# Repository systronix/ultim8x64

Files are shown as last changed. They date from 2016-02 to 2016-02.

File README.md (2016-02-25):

# ultim8x64

ultimate LED panel

built using APA102 RGB LEDs

8x64 matrix

Modular

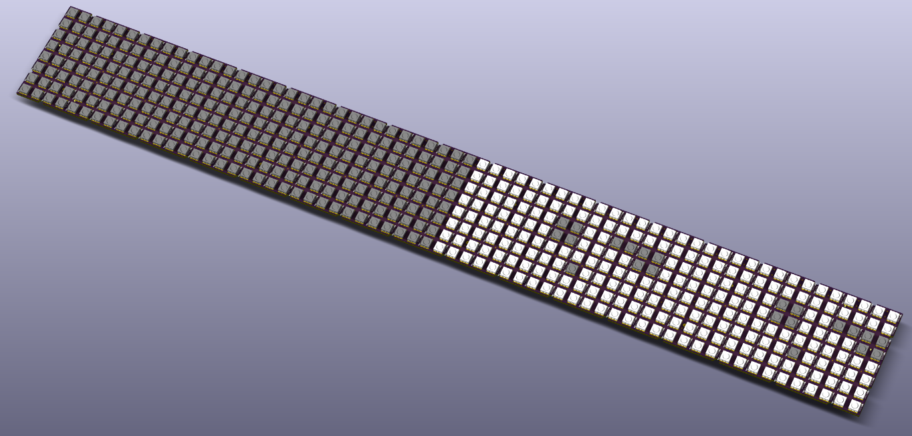
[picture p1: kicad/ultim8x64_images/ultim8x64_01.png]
ultim8x64 top


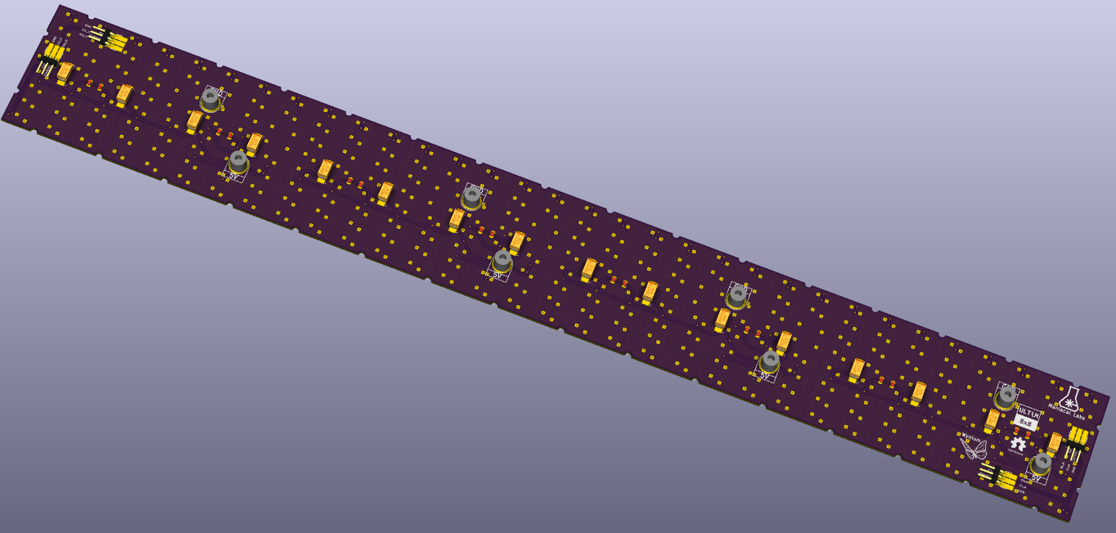
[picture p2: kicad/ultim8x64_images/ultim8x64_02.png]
ultim8x64 bottom


License
-------
[CERN Open Hardware Licence v1.2 ]

[CERN Open Hardware Licence v1.2 ]:http://www.ohwr.org/attachments/2388/cern_ohl_v_1_2.txt

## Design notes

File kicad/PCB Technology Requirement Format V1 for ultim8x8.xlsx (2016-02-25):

深圳矽递科技有限公司 Seeed Technology Limited
PCB Technology Requirement Format
PCB Name & Version | ULTiM8x8
PCB Material PCB板材： | (Rigid)FR－4
PCB Size PCB大小： | inch | ( 2.40 ) × (2.40 )
PCB Layer PCB层数： | 2
Thickness PCB厚度：
 | 1.6mm
Copper Weight 铜厚： | 1oz
PCB Colour 阻焊颜色： |  | White白色
Silkscreen 字符颜色： |  | Black 黑色 | other:( )
Pads Finished 焊盘喷镀： | (Hasl-lead free) 无铅喷锡
Via solder mask 阻焊覆盖： |  | solder mask opening 过孔开窗
Minimum trace/space (mm) 最小线宽 | 0.254mm/0.254mm | Minimum hole size (mm) 最小孔径 | 0.635mm
Special requirements 特殊工艺： | No | (Put requirements here)
Comment:

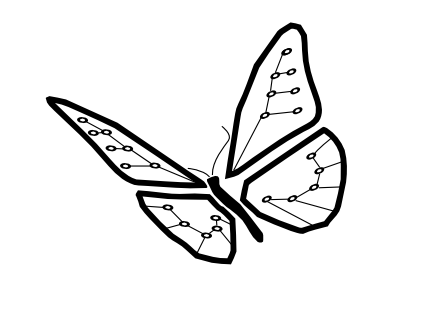
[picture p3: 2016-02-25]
kicad/ultim8x64_data/wyolum_butterfly.png

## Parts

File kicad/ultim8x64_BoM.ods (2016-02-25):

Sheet: BoM_TinyTiM
Id | Reference | Quantity | Value | Package
1 | C1,C3 | 2 | 100nF | c_0805
2 | C2,C4 | 2 | 47uF 20V | c_2917
3 | P1, P2, P5, P6 | 1 | Input1, Input2, Output1,Output2 | header_3pos_smd_male
4 | P3, P4 | 1 | 5V, GND | PowerIn_stud
5 | U01 ~ U64 | 64 | APA102 | APA102

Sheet: BoM_PCB
Id | Value | Reference | Quantity | Package
1 | 100nF | C3,C1 | 2 | c_0805
2 | 47uF 20V | C2,C4 | 2 | c_2917
3 | Input1, Input2, Output1,Output2 | P1, P2, P5, P6 | 1 | header_3pos_smd_male
4 | 5V, GND | P3, P4 | 1 | PowerIn_stud
5 | APA102 | U01 ~ U64 | 64 | APA102

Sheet: BoM_SCH
Reference | Value | Footprint
C1, C3 | 100nF | ultim8x8_libs:c_0805
C2, C4 | 47uF 20V | ultim8x8_libs:c_2917
P1, P2, P5, P6 | Input1, Input2, Output1, Output2 | ultim8x8_libs:header_3pos_smd_male
P3, P4 | 5V, GND | ultim8x8_libs:PowerIn_stud
U01 ~ U64 | APA102 | ultim8x8_libs:APA102

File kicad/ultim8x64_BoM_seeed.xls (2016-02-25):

Electronic Engineering BOM List
Product Name：ULTiM8x8
Version：V1.0
Issue Date：19/Feb/2016
Item No. (序号) | Reference Des (上件位置) | Qty (用量) | Catalog (分类） | Part_Description (规格描述) | Part_Value （元件值） | Part_Package （元件封装） | Manufacturers Name (使用厂牌名称) | Manufacturers Part No. (使用厂牌型号) | Distributors Name （供应商名称） | Distributors Part No. (供貨商型号) | Unit Price （单价） | Price Break To Use （价格分段的购买量） | Notes/Remark （备注）
Example（填写范例）
1 | U01 ~ U64 | 64 | OTHER | 5050 SMD RGB LED with built-in controller | APA102 | 5050 | Shiji Lighting | APA102C | Aliexpress | APA102C
2 | C1 , C3 | 2 | Capacitor | CAP CER 0.1UF 25V 10% X7R 0805 | 100nF, 25V | Surface Mount, MLCC (c0805) | Kemet | C0805C104K3RACTU | Digikey | 399-1168-1-ND |  |  | http://www.digikey.com/product-detail/en/C0805C104K3RACTU/399-1168-1-ND/411443
3 | C2, C4 | 2 | Capacitor | CAP POLY 47UF 20% 20V SMD | 47uF, 20V | Surface Mount 2917 (7343 Metric) | Panasonic Electronic Components | EEF-CT1D470R | Digikey | P18993CT-ND |  |  | http://www.digikey.com/product-detail/en/EEF-CT1D470R/P18993CT-ND/5805643
4 | P1, P2, P5, P6 | 4 | Connector | CONN HEADER 3POS .100 RT/A SMD | Input1, Input2, Output1,Output2 | Male Pin, Header, Unshrouded, Breakaway, 3 pin | Sullins Connector Solutions | GBC03SGSN-M89 | Digikey | S1143E-03-ND |  |  | http://www.digikey.com/product-detail/en/GBC03SGSN-M89/S1143E-03-ND/862388
5 | P3, P4 | 2 | Connector | POWER ELEMENT BUSH | 5V, GND | Screw Terminal, Power Tap, M3 | Wurth Electronics Inc | 7466103 | Digikey | 732-5242-ND |  |  | http://www.digikey.com/product-detail/en/7466103/732-5242-ND/4733834
1. Recommended Distributor: Digi-Key, Mouser, Avnet Express, Farnell.
2. Catalog: Capacitor,Resister,Diode,Connector,Transistor,IC,PROTECTOR CATEGORY,OTHER
3. Required Fields: Item No, Reference Des, Qty, Catalog, Part_Value, Part Package
Optional Fields: Part_Description, Manufacturers Name, Manufacturers Part No, Distributors Name, Distributors Part No, Unit Cost, Price break to use, Notes/Remark

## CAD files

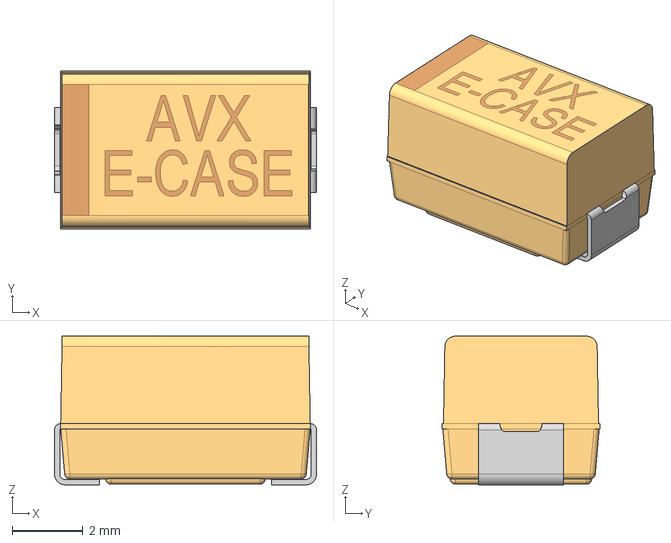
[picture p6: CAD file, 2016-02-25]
kicad/ultim8x64_3D_modules/Cap_2917_AVX_E_CASE.step
7.40 x 4.45 x 4.20 mm

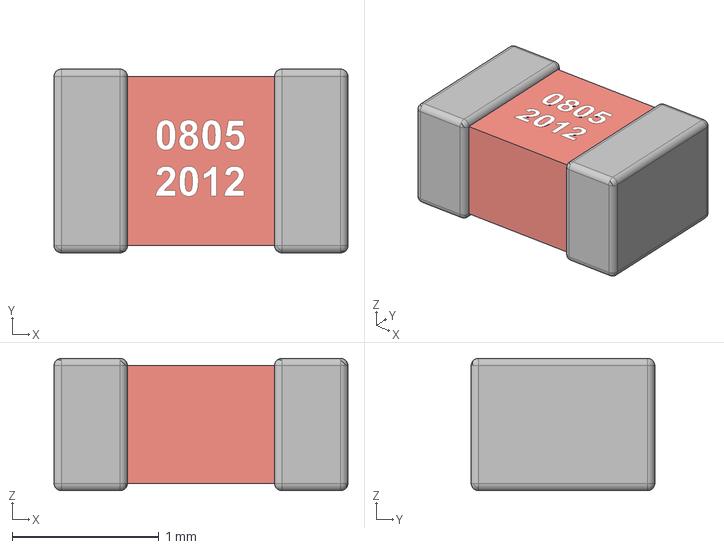
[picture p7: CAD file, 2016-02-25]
kicad/ultim8x64_3D_modules/Cap_0805_2012.step
2.00 x 1.25 x 0.9 mm

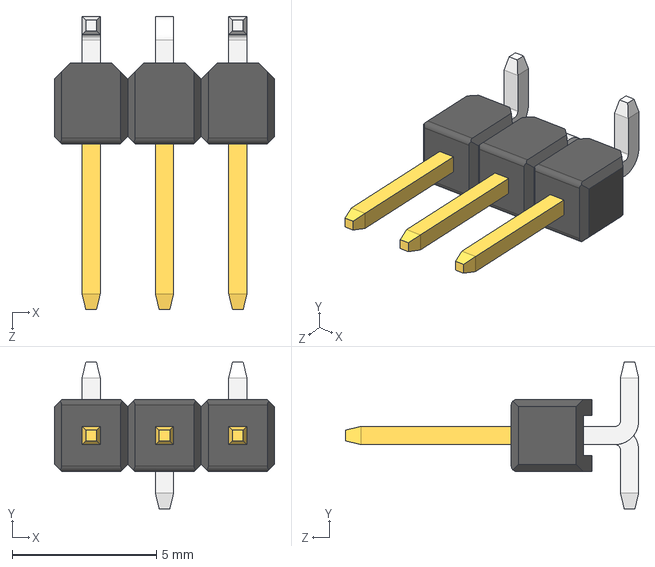
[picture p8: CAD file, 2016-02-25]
kicad/ultim8x64_3D_modules/header1x3_1241150-3.step
7.62 x 5.08 x 10.2 mm

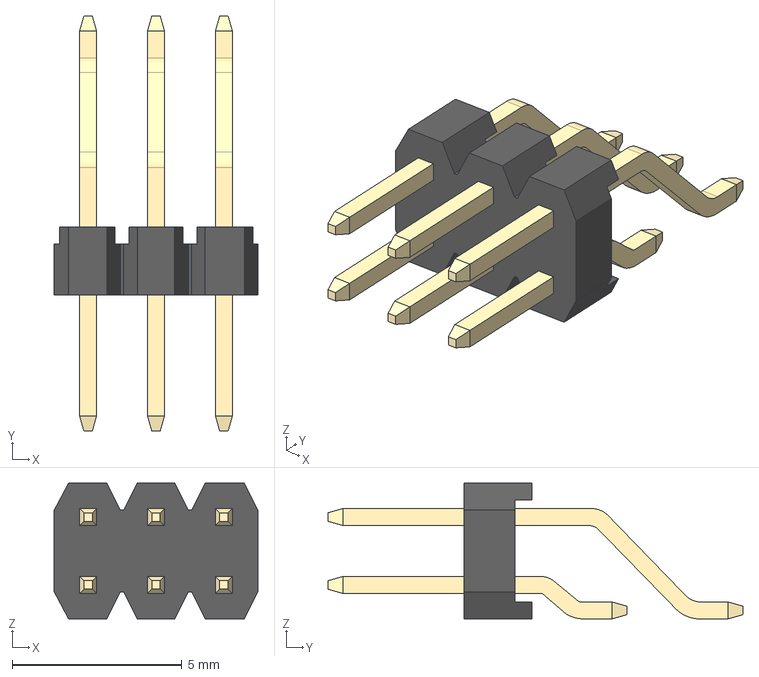
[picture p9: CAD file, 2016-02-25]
kicad/ultim8x64_3D_modules/header_a-sl200-da-g06mp1.step
6.00 x 12.2 x 4.00 mm

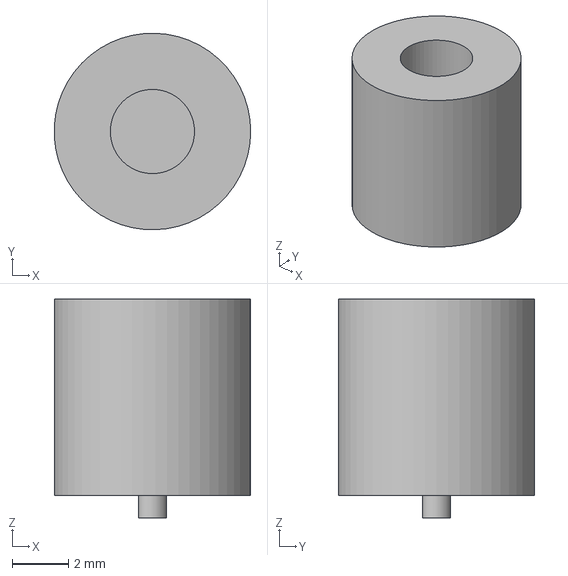
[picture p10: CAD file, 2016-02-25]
kicad/ultim8x64_3D_modules/PowerIn_Stud.step
6.99 x 7.00 x 7.80 mm

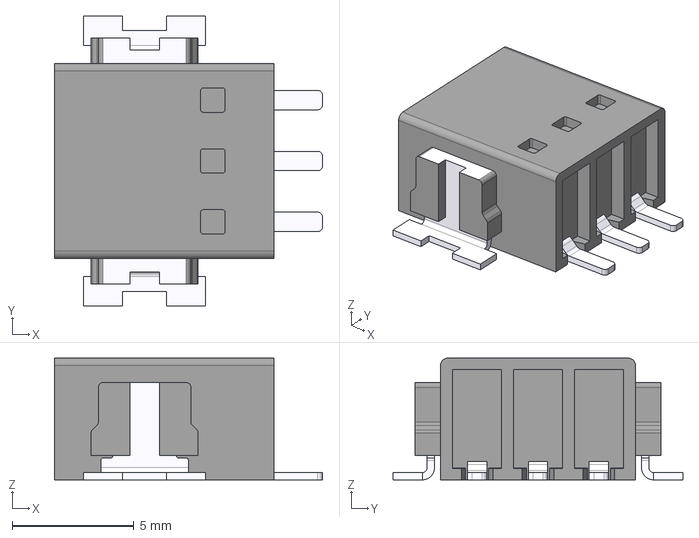
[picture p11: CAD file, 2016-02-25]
kicad/ultim8x64_3D_modules/conn_1771033.stp
11.0 x 11.9 x 5.00 mm

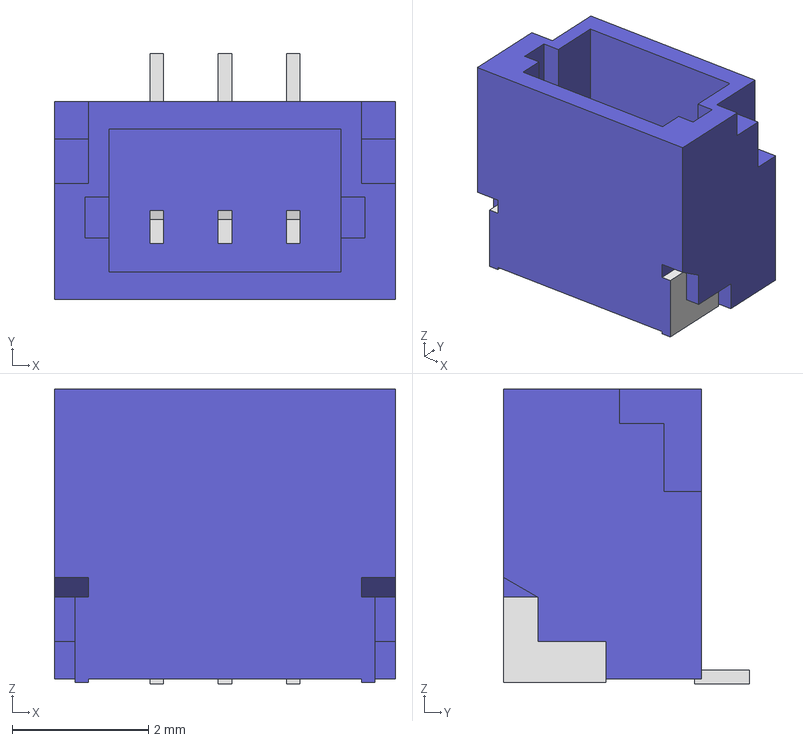
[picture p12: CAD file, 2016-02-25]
kicad/ultim8x64_3D_modules/BM03B-SRSS-TB.step
5.00 x 3.60 x 4.32 mm

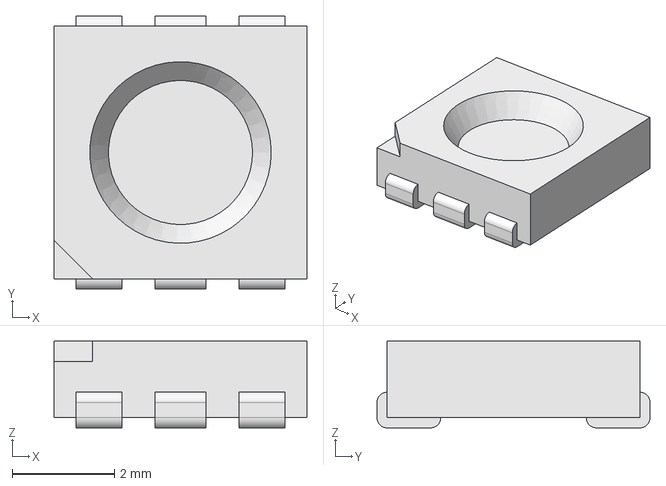
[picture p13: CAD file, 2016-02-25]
kicad/ultim8x64_3D_modules/LED_SMD_APA102.step
4.95 x 5.35 x 1.70 mm

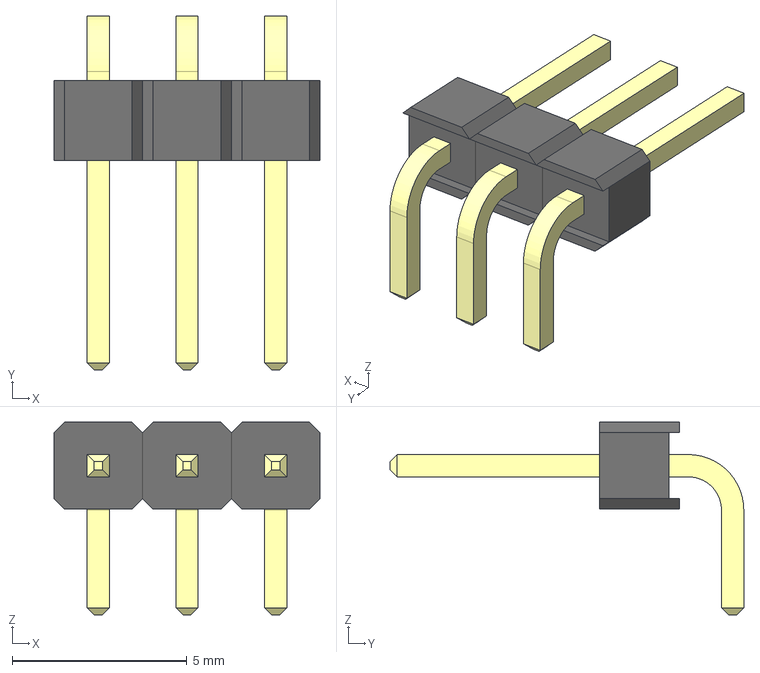
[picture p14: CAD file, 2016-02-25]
kicad/ultim8x64_3D_modules/header_Male_RA_Low_3Pin.step
7.62 x 10.1 x 5.52 mm

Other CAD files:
kicad/ultim8x64_3D_modules/PowerIn_Stud.fcstd

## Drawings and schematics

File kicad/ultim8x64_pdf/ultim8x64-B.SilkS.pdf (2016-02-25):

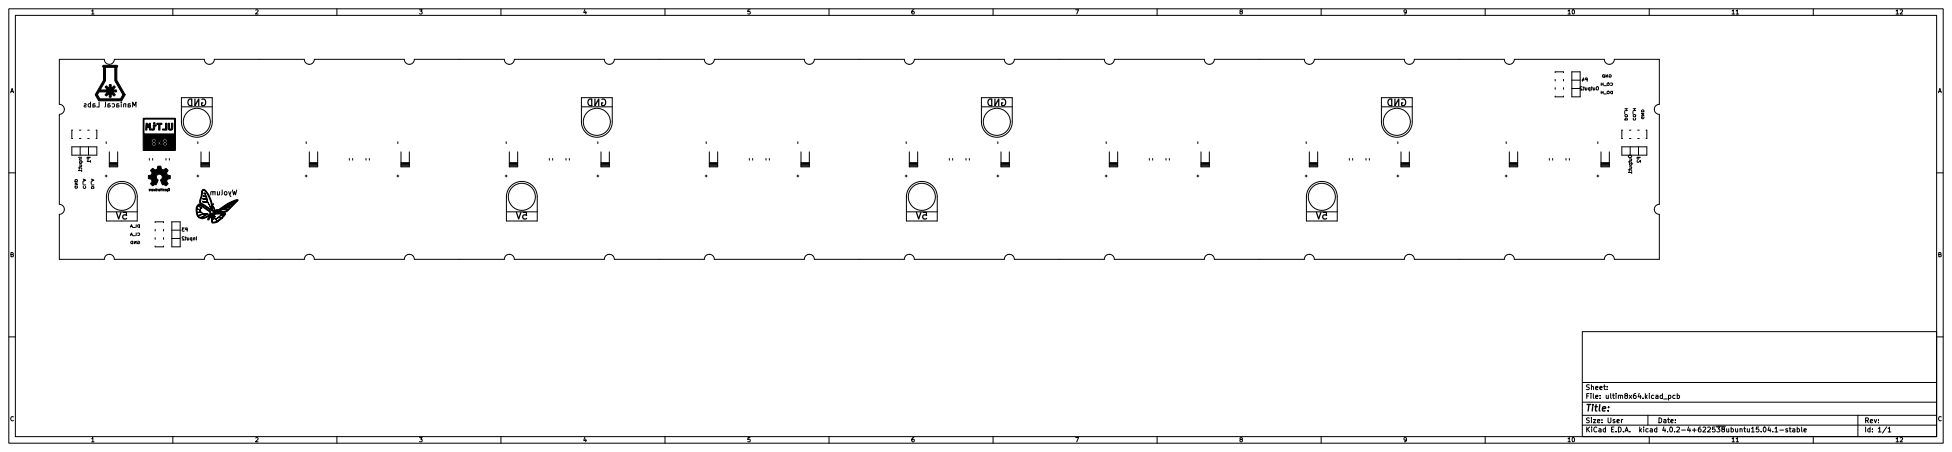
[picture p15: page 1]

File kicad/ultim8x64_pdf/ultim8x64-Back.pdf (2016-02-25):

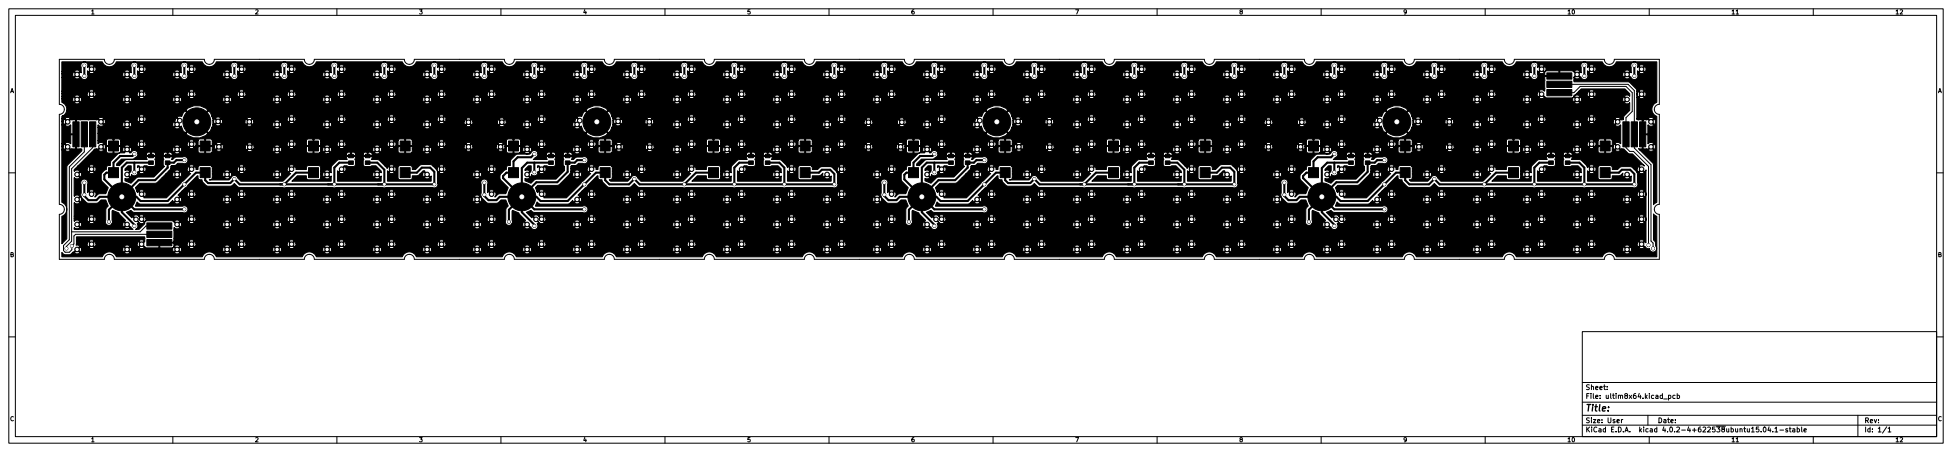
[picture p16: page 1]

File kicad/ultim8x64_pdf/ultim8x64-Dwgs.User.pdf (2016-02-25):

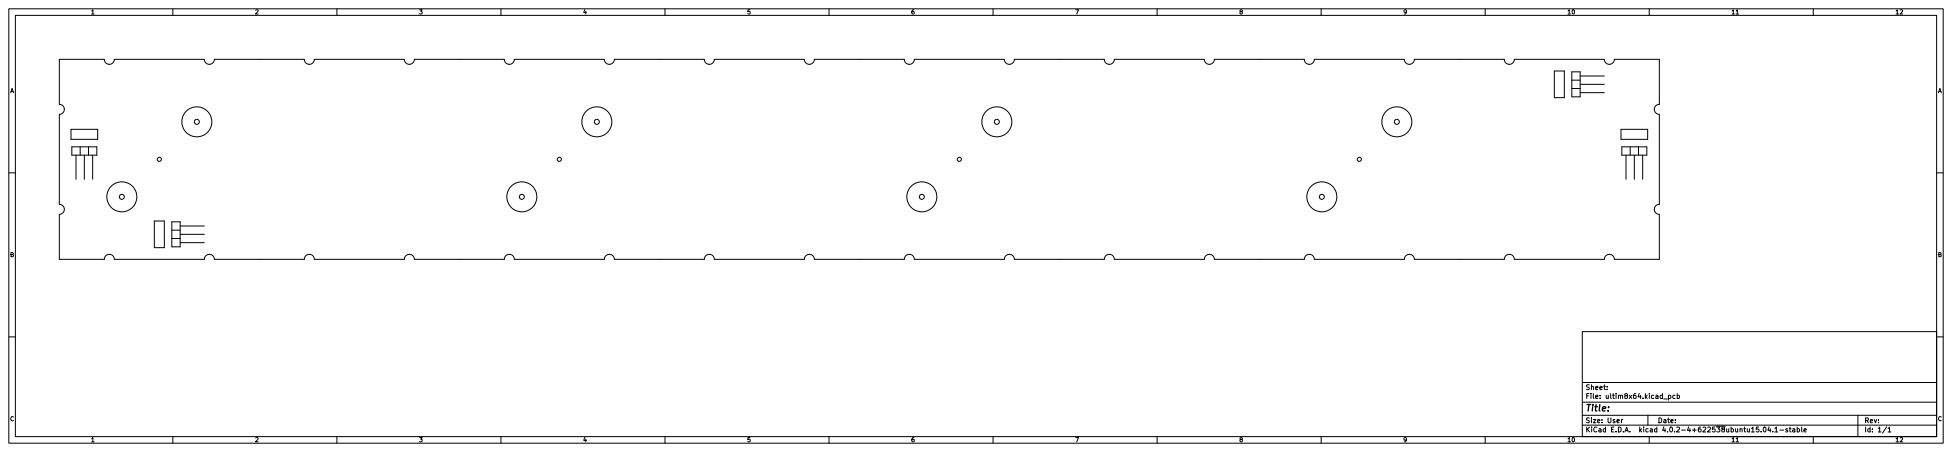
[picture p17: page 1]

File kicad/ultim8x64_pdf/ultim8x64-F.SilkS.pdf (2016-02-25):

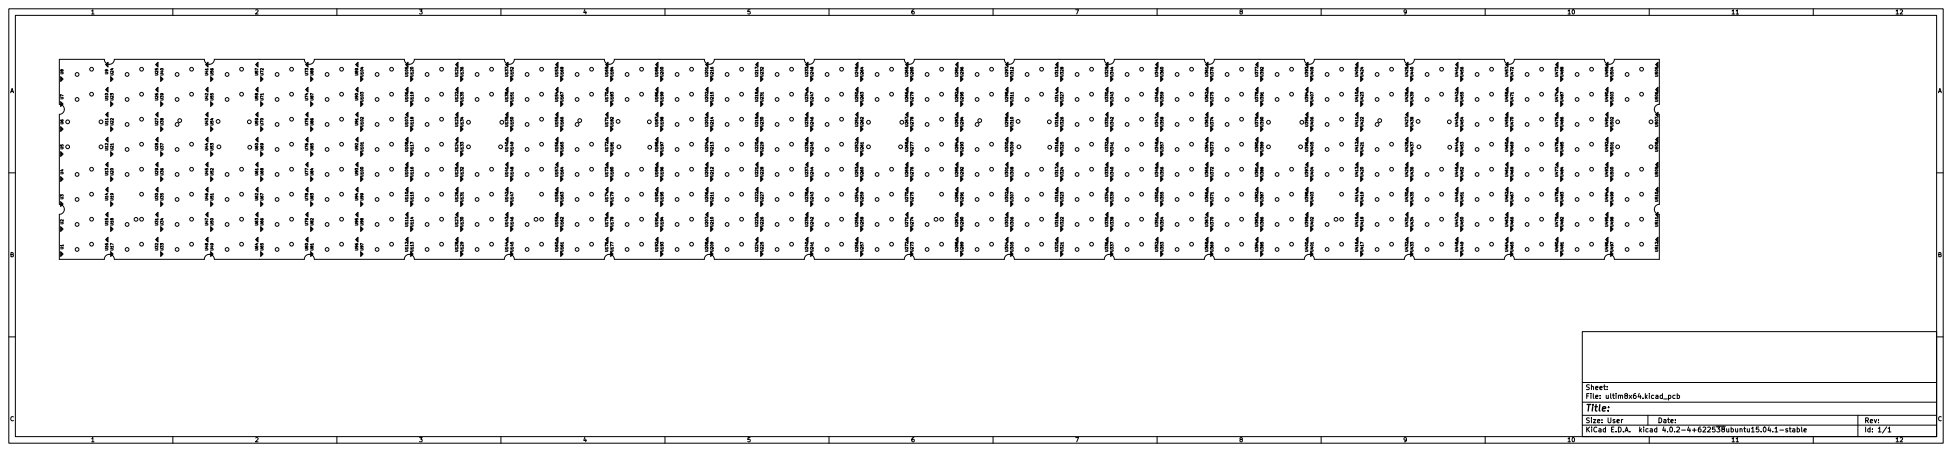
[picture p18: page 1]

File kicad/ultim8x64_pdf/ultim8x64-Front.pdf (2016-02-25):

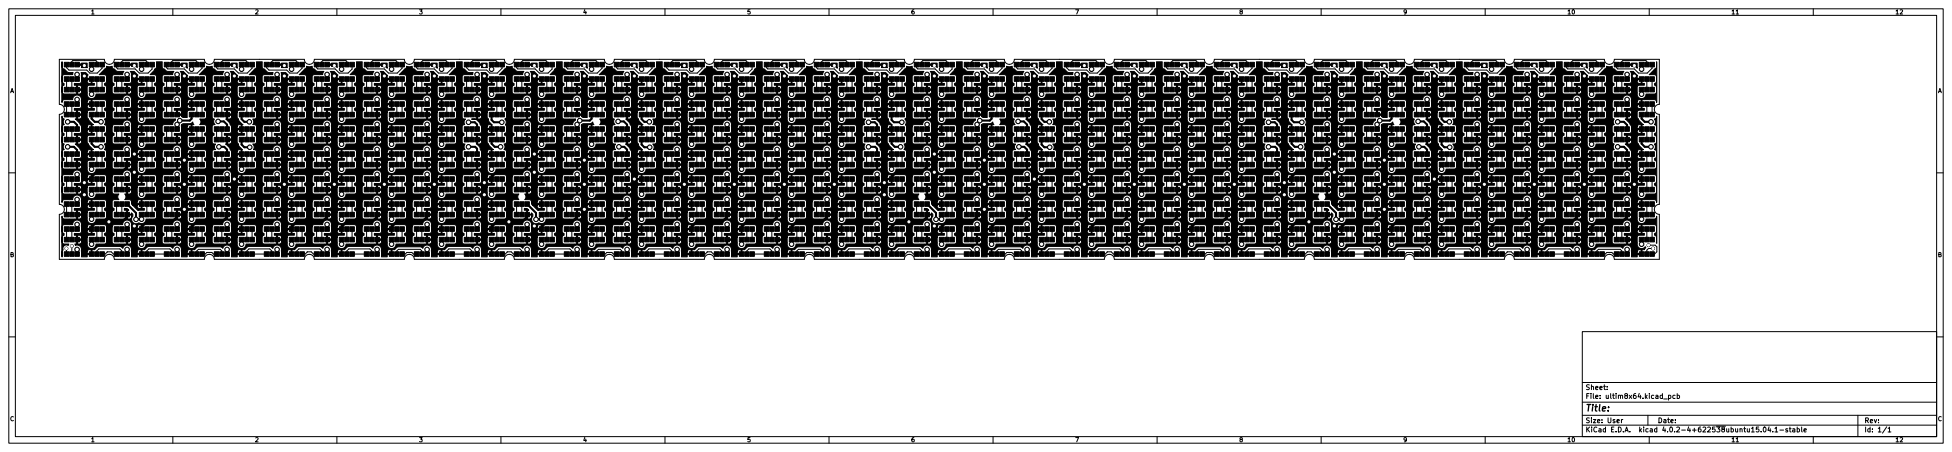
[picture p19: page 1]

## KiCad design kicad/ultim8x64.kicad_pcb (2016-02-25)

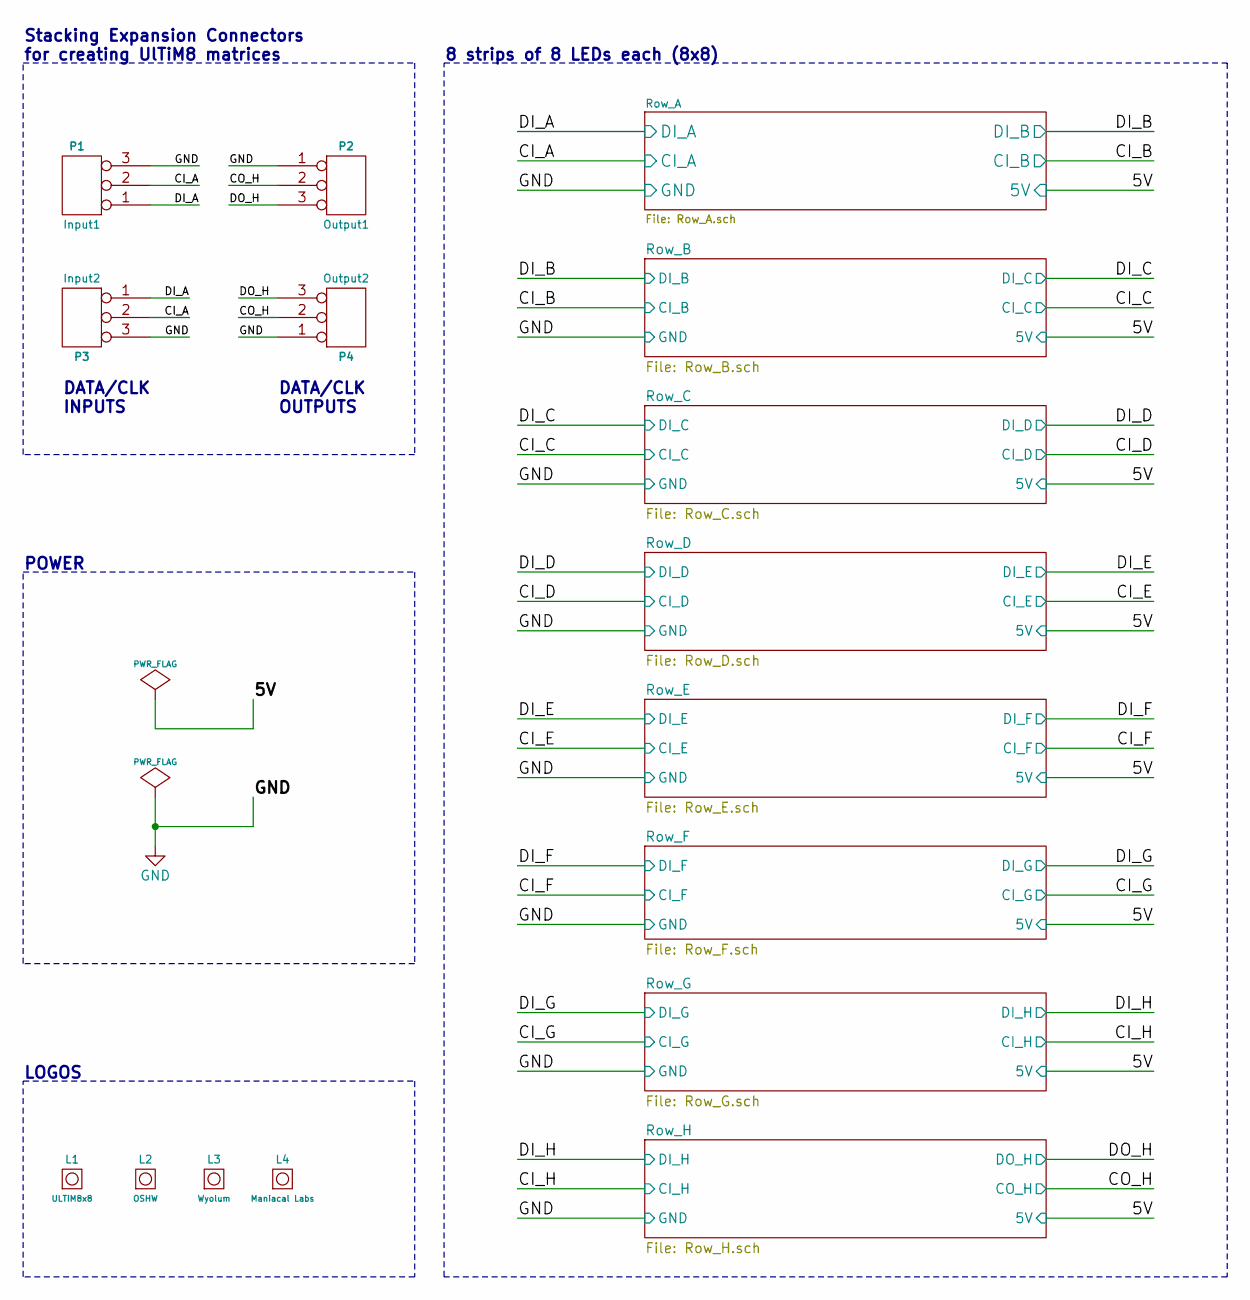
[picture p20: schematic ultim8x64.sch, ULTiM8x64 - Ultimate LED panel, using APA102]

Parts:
L1: ULTiM8x8; logo_ultim8x8
L2: OSHW; OSHW_6mm
L3: Wyolum; logo_wyo_butterfly
L4: Maniacal Labs; logo_MLlabs
P1: Input1; header_3pos_smd_male
P2: Output1; header_3pos_smd_male
P3: Input2; header_3pos_smd_male
P4: Output2; header_3pos_smd_male

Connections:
/Row_A/CI_A: P1.2, P3.2; also elsewhere on the board
/Row_A/DI_A: P1.1, P3.1; also elsewhere on the board
/Row_H/CO_H: P2.2, P4.2; also elsewhere on the board
/Row_H/DO_H: P2.3, P4.3; also elsewhere on the board
GND: P1.3, P2.1, P3.3, P4.1; also elsewhere on the board

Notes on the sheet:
Stacking Expansion Connectors for creating UlTiM8 matrices
LOGOS
POWER
DATA/CLK OUTPUTS
DATA/CLK INPUTS
8 strips of 8 LEDs each (8x8)

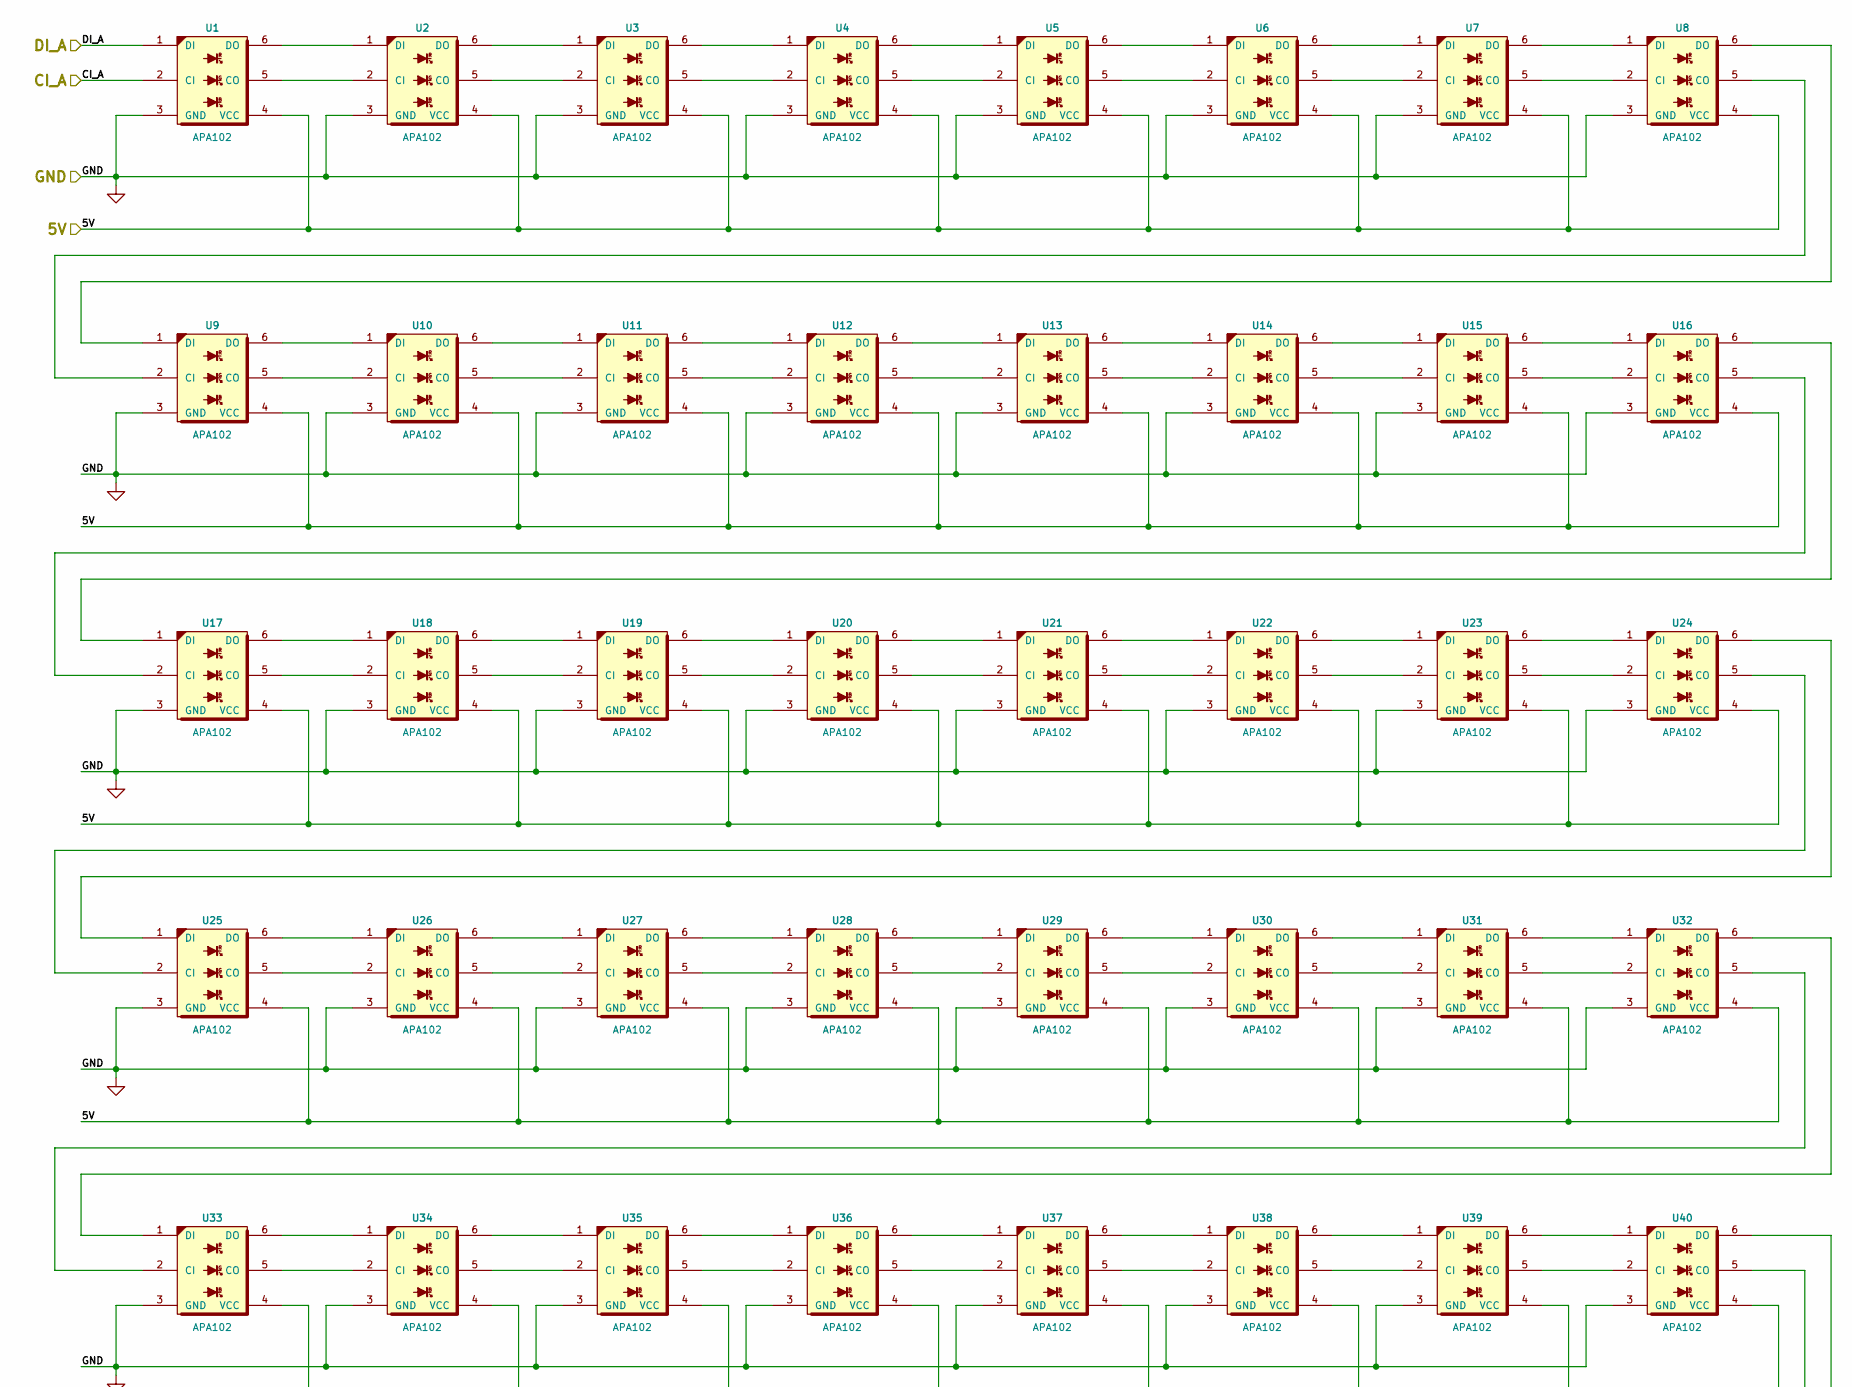
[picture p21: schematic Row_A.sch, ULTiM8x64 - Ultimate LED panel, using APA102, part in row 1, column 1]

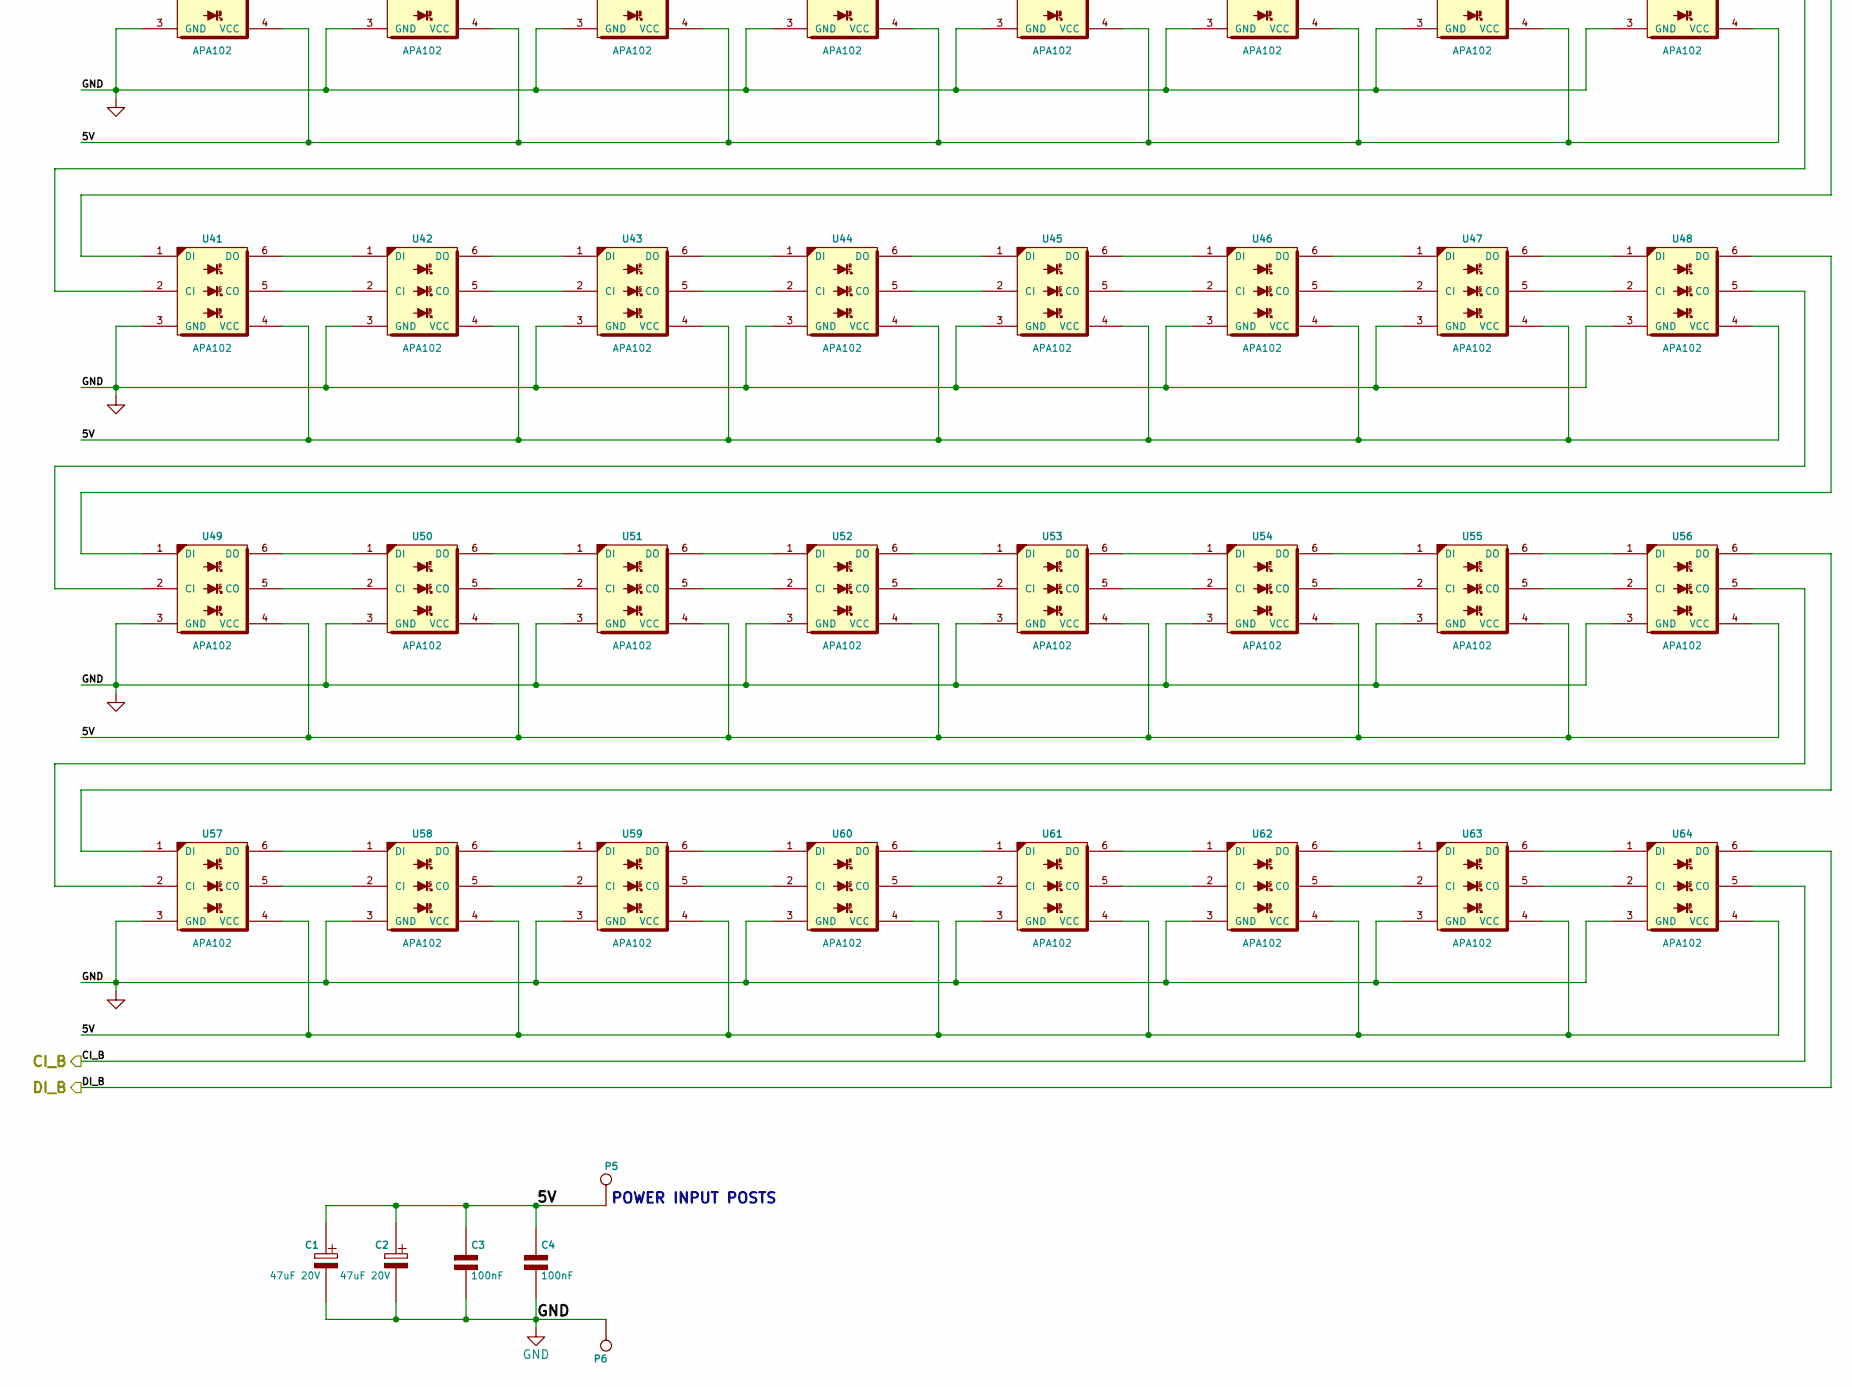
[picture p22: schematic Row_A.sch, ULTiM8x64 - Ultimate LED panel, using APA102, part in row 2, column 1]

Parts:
C1, C2: 47uF 20V; c_2917
C3, C4: 100nF; c_0805
P5: 5V; PowerIn_stud
P6: GND; PowerIn_stud
U1, U2, U3, U4, U7, U8, U9, U10, U13, U14, U15, U16, U17, U18, U20, U21, U22, U23, U24, U25, U26, U27, U28, U29, U30, U31, U32, U33, U34, U35, U36, U37, U39, U40, U41, U42, U44, U45, U46, U47, U48, U49, U50, U51, U52, U55, U56, U57, U58, U61, U62, U63, U64: APA102
U5: APA102; APA102_U05
U6: APA102; APA102_U06
U11: APA102; APA102_U11
U12: APA102; APA102_U12
U19: APA102; APA102_U19
U38: APA102; APA102_U38
U43: APA102; APA102_U43
U53: APA102; APA102_U53
U54: APA102; APA102_U54
U59: APA102; APA102_U59
U60: APA102; APA102_U60

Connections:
/Row_A/5V: C1.1 (+), C2.1 (+), C3.1, C4.1, P5.1, U1.4 (VCC), U2.4 (VCC), U3.4 (VCC), U4.4 (VCC), U5.4 (VCC), U6.4 (VCC), U7.4 (VCC), U8.4 (VCC), U9.4 (VCC), U10.4 (VCC), U11.4 (VCC), U12.4 (VCC), U13.4 (VCC), U14.4 (VCC), U15.4 (VCC), U16.4 (VCC), U17.4 (VCC), U18.4 (VCC), U19.4 (VCC), U20.4 (VCC), U21.4 (VCC), U22.4 (VCC), U23.4 (VCC), U24.4 (VCC), U25.4 (VCC), U26.4 (VCC), U27.4 (VCC), U28.4 (VCC), U29.4 (VCC), U30.4 (VCC), U31.4 (VCC), U32.4 (VCC), U33.4 (VCC), U34.4 (VCC), U35.4 (VCC), U36.4 (VCC), U37.4 (VCC), U38.4 (VCC), U39.4 (VCC), U40.4 (VCC), U41.4 (VCC), U42.4 (VCC), U43.4 (VCC), U44.4 (VCC), U45.4 (VCC), U46.4 (VCC), U47.4 (VCC), U48.4 (VCC), U49.4 (VCC), U50.4 (VCC), U51.4 (VCC), U52.4 (VCC), U53.4 (VCC), U54.4 (VCC), U55.4 (VCC), U56.4 (VCC), U57.4 (VCC), U58.4 (VCC), U59.4 (VCC), U60.4 (VCC), U61.4 (VCC), U62.4 (VCC), U63.4 (VCC), U64.4 (VCC); also elsewhere on the board
/Row_A/CI_A: U1.2 (CI); also elsewhere on the board
/Row_A/CI_B: U64.5 (CO); also elsewhere on the board
/Row_A/DI_A: U1.1 (DI); also elsewhere on the board
/Row_A/DI_B: U64.6 (DO); also elsewhere on the board
GND: C1.2 (-), C2.2 (-), C3.2, C4.2, P6.1, U1.3 (GND), U2.3 (GND), U3.3 (GND), U4.3 (GND), U5.3 (GND), U6.3 (GND), U7.3 (GND), U8.3 (GND), U9.3 (GND), U10.3 (GND), U11.3 (GND), U12.3 (GND), U13.3 (GND), U14.3 (GND), U15.3 (GND), U16.3 (GND), U17.3 (GND), U18.3 (GND), U19.3 (GND), U20.3 (GND), U21.3 (GND), U22.3 (GND), U23.3 (GND), U24.3 (GND), U25.3 (GND), U26.3 (GND), U27.3 (GND), U28.3 (GND), U29.3 (GND), U30.3 (GND), U31.3 (GND), U32.3 (GND), U33.3 (GND), U34.3 (GND), U35.3 (GND), U36.3 (GND), U37.3 (GND), U38.3 (GND), U39.3 (GND), U40.3 (GND), U41.3 (GND), U42.3 (GND), U43.3 (GND), U44.3 (GND), U45.3 (GND), U46.3 (GND), U47.3 (GND), U48.3 (GND), U49.3 (GND), U50.3 (GND), U51.3 (GND), U52.3 (GND), U53.3 (GND), U54.3 (GND), U55.3 (GND), U56.3 (GND), U57.3 (GND), U58.3 (GND), U59.3 (GND), U60.3 (GND), U61.3 (GND), U62.3 (GND), U63.3 (GND), U64.3 (GND); also elsewhere on the board
unnamed: U1.5 (CO), U2.2 (CI)
unnamed: U1.6 (DO), U2.1 (DI)
unnamed: U2.5 (CO), U3.2 (CI)
unnamed: U2.6 (DO), U3.1 (DI)
unnamed: U3.5 (CO), U4.2 (CI)
unnamed: U3.6 (DO), U4.1 (DI)
unnamed: U4.5 (CO), U5.2 (CI)
unnamed: U4.6 (DO), U5.1 (DI)
unnamed: U5.5 (CO), U6.2 (CI)
unnamed: U5.6 (DO), U6.1 (DI)
unnamed: U6.5 (CO), U7.2 (CI)
unnamed: U6.6 (DO), U7.1 (DI)
unnamed: U7.5 (CO), U8.2 (CI)
unnamed: U7.6 (DO), U8.1 (DI)
unnamed: U8.5 (CO), U9.2 (CI)
unnamed: U8.6 (DO), U9.1 (DI)
unnamed: U9.6 (DO), U10.1 (DI)
unnamed: U9.5 (CO), U10.2 (CI)
unnamed: U10.5 (CO), U11.2 (CI)
unnamed: U10.6 (DO), U11.1 (DI)
unnamed: U11.5 (CO), U12.2 (CI)
unnamed: U11.6 (DO), U12.1 (DI)
unnamed: U12.5 (CO), U13.2 (CI)
unnamed: U12.6 (DO), U13.1 (DI)
unnamed: U13.5 (CO), U14.2 (CI)
unnamed: U13.6 (DO), U14.1 (DI)
unnamed: U14.5 (CO), U15.2 (CI)
unnamed: U14.6 (DO), U15.1 (DI)
unnamed: U15.5 (CO), U16.2 (CI)
unnamed: U15.6 (DO), U16.1 (DI)
unnamed: U16.5 (CO), U17.2 (CI)
unnamed: U16.6 (DO), U17.1 (DI)
unnamed: U17.5 (CO), U18.2 (CI)
unnamed: U17.6 (DO), U18.1 (DI)
unnamed: U18.5 (CO), U19.2 (CI)
unnamed: U18.6 (DO), U19.1 (DI)
unnamed: U19.5 (CO), U20.2 (CI)
unnamed: U19.6 (DO), U20.1 (DI)
unnamed: U20.5 (CO), U21.2 (CI)
unnamed: U20.6 (DO), U21.1 (DI)
unnamed: U21.5 (CO), U22.2 (CI)
unnamed: U21.6 (DO), U22.1 (DI)
unnamed: U22.5 (CO), U23.2 (CI)
unnamed: U22.6 (DO), U23.1 (DI)
unnamed: U23.5 (CO), U24.2 (CI)
unnamed: U23.6 (DO), U24.1 (DI)
unnamed: U24.5 (CO), U25.2 (CI)
unnamed: U24.6 (DO), U25.1 (DI)
unnamed: U25.5 (CO), U26.2 (CI)
unnamed: U25.6 (DO), U26.1 (DI)
unnamed: U26.5 (CO), U27.2 (CI)
unnamed: U26.6 (DO), U27.1 (DI)
unnamed: U27.5 (CO), U28.2 (CI)
unnamed: U27.6 (DO), U28.1 (DI)
unnamed: U28.5 (CO), U29.2 (CI)
unnamed: U28.6 (DO), U29.1 (DI)
unnamed: U29.5 (CO), U30.2 (CI)
unnamed: U29.6 (DO), U30.1 (DI)
unnamed: U30.5 (CO), U31.2 (CI)
unnamed: U30.6 (DO), U31.1 (DI)
unnamed: U31.5 (CO), U32.2 (CI)
unnamed: U31.6 (DO), U32.1 (DI)
unnamed: U32.5 (CO), U33.2 (CI)
unnamed: U32.6 (DO), U33.1 (DI)
unnamed: U33.5 (CO), U34.2 (CI)
unnamed: U33.6 (DO), U34.1 (DI)
unnamed: U34.5 (CO), U35.2 (CI)
unnamed: U34.6 (DO), U35.1 (DI)
unnamed: U35.5 (CO), U36.2 (CI)
unnamed: U35.6 (DO), U36.1 (DI)
unnamed: U36.5 (CO), U37.2 (CI)
unnamed: U36.6 (DO), U37.1 (DI)
unnamed: U37.5 (CO), U38.2 (CI)
unnamed: U37.6 (DO), U38.1 (DI)
unnamed: U38.5 (CO), U39.2 (CI)
unnamed: U38.6 (DO), U39.1 (DI)
unnamed: U39.5 (CO), U40.2 (CI)
unnamed: U39.6 (DO), U40.1 (DI)
unnamed: U40.5 (CO), U41.2 (CI)
unnamed: U40.6 (DO), U41.1 (DI)
unnamed: U41.5 (CO), U42.2 (CI)
unnamed: U41.6 (DO), U42.1 (DI)
unnamed: U42.5 (CO), U43.2 (CI)
unnamed: U42.6 (DO), U43.1 (DI)
unnamed: U43.5 (CO), U44.2 (CI)
unnamed: U43.6 (DO), U44.1 (DI)
unnamed: U44.5 (CO), U45.2 (CI)
unnamed: U44.6 (DO), U45.1 (DI)
unnamed: U45.5 (CO), U46.2 (CI)
unnamed: U45.6 (DO), U46.1 (DI)
unnamed: U46.5 (CO), U47.2 (CI)
unnamed: U46.6 (DO), U47.1 (DI)
unnamed: U47.5 (CO), U48.2 (CI)
unnamed: U47.6 (DO), U48.1 (DI)
unnamed: U48.5 (CO), U49.2 (CI)
unnamed: U48.6 (DO), U49.1 (DI)
unnamed: U49.5 (CO), U50.2 (CI)
unnamed: U49.6 (DO), U50.1 (DI)
unnamed: U50.5 (CO), U51.2 (CI)
unnamed: U50.6 (DO), U51.1 (DI)
unnamed: U51.5 (CO), U52.2 (CI)
unnamed: U51.6 (DO), U52.1 (DI)
unnamed: U52.5 (CO), U53.2 (CI)
unnamed: U52.6 (DO), U53.1 (DI)
unnamed: U53.5 (CO), U54.2 (CI)
unnamed: U53.6 (DO), U54.1 (DI)
unnamed: U54.5 (CO), U55.2 (CI)
unnamed: U54.6 (DO), U55.1 (DI)
unnamed: U55.5 (CO), U56.2 (CI)
unnamed: U55.6 (DO), U56.1 (DI)
unnamed: U56.5 (CO), U57.2 (CI)
unnamed: U56.6 (DO), U57.1 (DI)
unnamed: U57.5 (CO), U58.2 (CI)
unnamed: U57.6 (DO), U58.1 (DI)
unnamed: U58.5 (CO), U59.2 (CI)
unnamed: U58.6 (DO), U59.1 (DI)
unnamed: U59.5 (CO), U60.2 (CI)
unnamed: U59.6 (DO), U60.1 (DI)
unnamed: U60.5 (CO), U61.2 (CI)
unnamed: U60.6 (DO), U61.1 (DI)
unnamed: U61.5 (CO), U62.2 (CI)
unnamed: U61.6 (DO), U62.1 (DI)
unnamed: U62.5 (CO), U63.2 (CI)
unnamed: U62.6 (DO), U63.1 (DI)
unnamed: U63.5 (CO), U64.2 (CI)
unnamed: U63.6 (DO), U64.1 (DI)

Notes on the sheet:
POWER INPUT POSTS

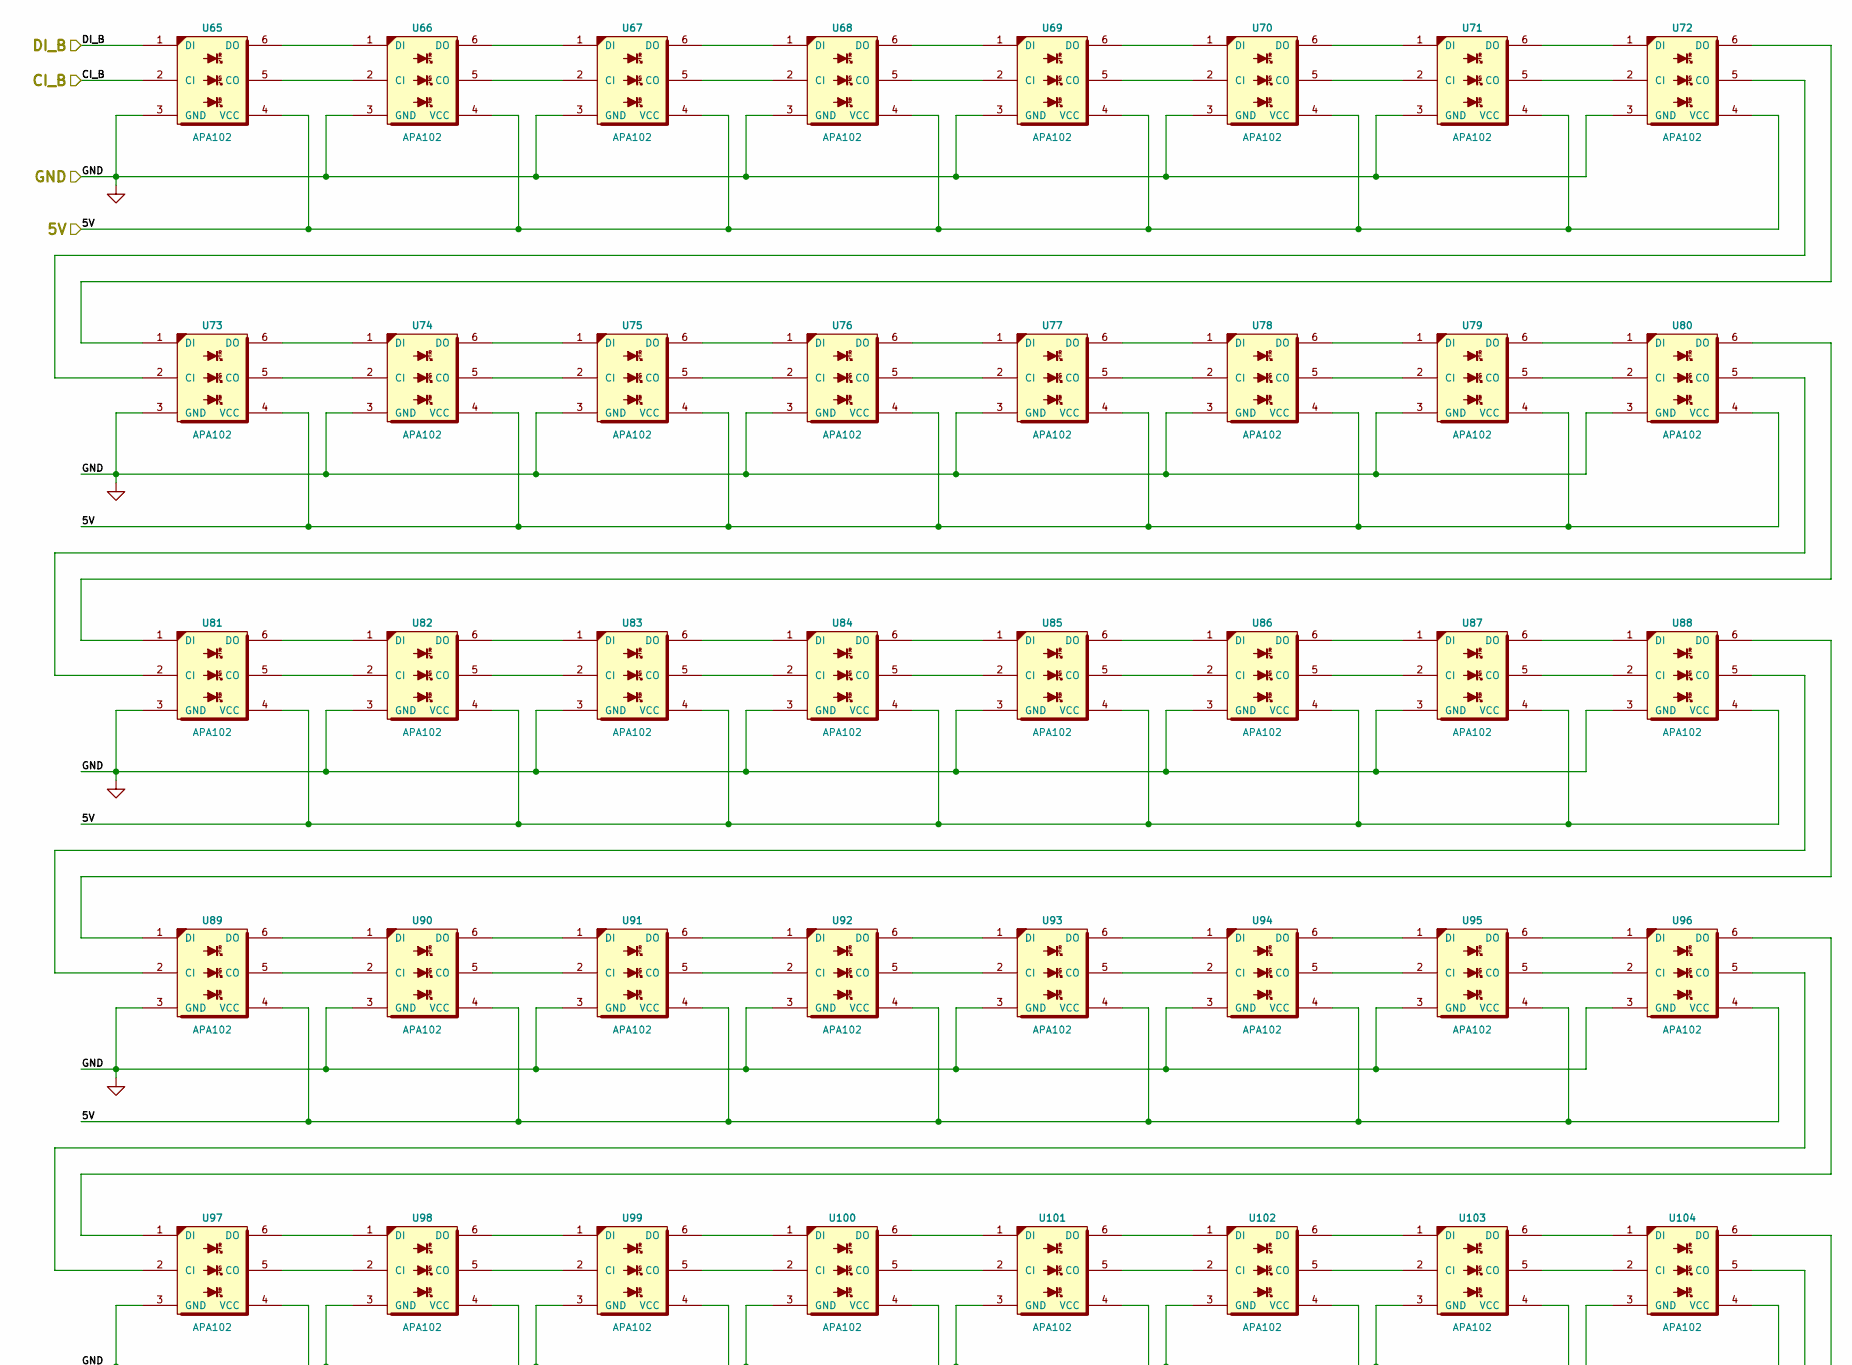
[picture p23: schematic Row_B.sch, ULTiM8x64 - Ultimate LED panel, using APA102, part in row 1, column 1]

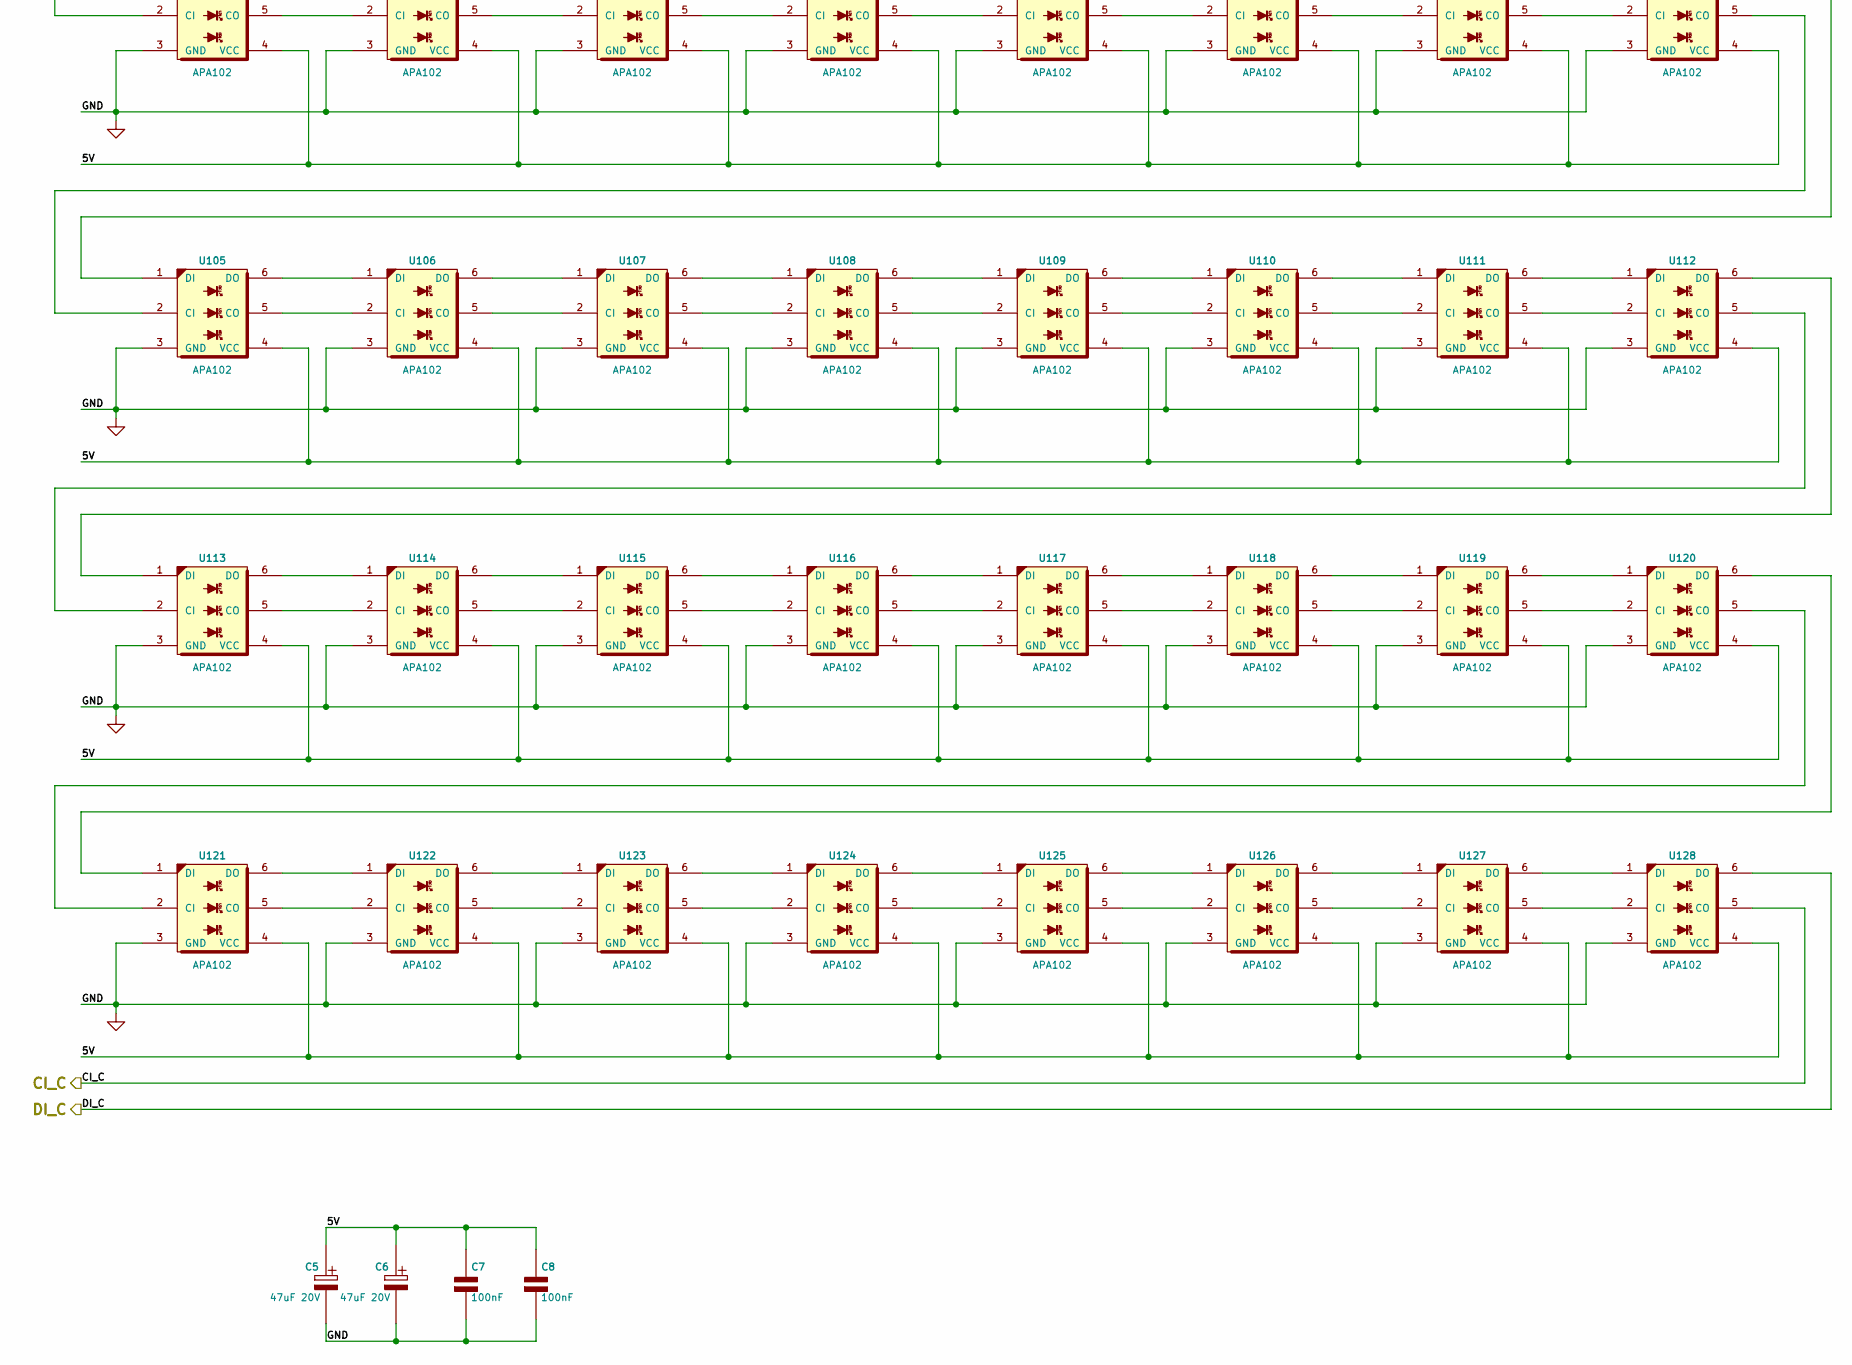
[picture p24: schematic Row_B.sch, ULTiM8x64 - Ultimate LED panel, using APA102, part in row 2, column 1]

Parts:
C5, C6: 47uF 20V; c_2917
C7, C8: 100nF; c_0805
U65, U66, U67, U68, U69, U70, U71, U72, U73, U74, U75, U76, U77, U78, U79, U80, U81, U82, U83, U84, U85, U86, U87, U88, U89, U90, U91, U92, U93, U94, U95, U96, U97, U98, U99, U100, U101, U102, U103, U104, U105, U106, U107, U108, U109, U110, U111, U112, U113, U114, U115, U116, U117, U118, U119, U120, U121, U122, U123, U124, U125, U126, U127, U128: APA102

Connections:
/Row_A/5V: C5.1 (+), C6.1 (+), C7.1, C8.1, U65.4 (VCC), U66.4 (VCC), U67.4 (VCC), U68.4 (VCC), U69.4 (VCC), U70.4 (VCC), U71.4 (VCC), U72.4 (VCC), U73.4 (VCC), U74.4 (VCC), U75.4 (VCC), U76.4 (VCC), U77.4 (VCC), U78.4 (VCC), U79.4 (VCC), U80.4 (VCC), U81.4 (VCC), U82.4 (VCC), U83.4 (VCC), U84.4 (VCC), U85.4 (VCC), U86.4 (VCC), U87.4 (VCC), U88.4 (VCC), U89.4 (VCC), U90.4 (VCC), U91.4 (VCC), U92.4 (VCC), U93.4 (VCC), U94.4 (VCC), U95.4 (VCC), U96.4 (VCC), U97.4 (VCC), U98.4 (VCC), U99.4 (VCC), U100.4 (VCC), U101.4 (VCC), U102.4 (VCC), U103.4 (VCC), U104.4 (VCC), U105.4 (VCC), U106.4 (VCC), U107.4 (VCC), U108.4 (VCC), U109.4 (VCC), U110.4 (VCC), U111.4 (VCC), U112.4 (VCC), U113.4 (VCC), U114.4 (VCC), U115.4 (VCC), U116.4 (VCC), U117.4 (VCC), U118.4 (VCC), U119.4 (VCC), U120.4 (VCC), U121.4 (VCC), U122.4 (VCC), U123.4 (VCC), U124.4 (VCC), U125.4 (VCC), U126.4 (VCC), U127.4 (VCC), U128.4 (VCC); also elsewhere on the board
/Row_A/CI_B: U65.2 (CI); also elsewhere on the board
/Row_A/DI_B: U65.1 (DI); also elsewhere on the board
/Row_B/CI_C: U128.5 (CO); also elsewhere on the board
/Row_B/DI_C: U128.6 (DO); also elsewhere on the board
GND: C5.2 (-), C6.2 (-), C7.2, C8.2, U65.3 (GND), U66.3 (GND), U67.3 (GND), U68.3 (GND), U69.3 (GND), U70.3 (GND), U71.3 (GND), U72.3 (GND), U73.3 (GND), U74.3 (GND), U75.3 (GND), U76.3 (GND), U77.3 (GND), U78.3 (GND), U79.3 (GND), U80.3 (GND), U81.3 (GND), U82.3 (GND), U83.3 (GND), U84.3 (GND), U85.3 (GND), U86.3 (GND), U87.3 (GND), U88.3 (GND), U89.3 (GND), U90.3 (GND), U91.3 (GND), U92.3 (GND), U93.3 (GND), U94.3 (GND), U95.3 (GND), U96.3 (GND), U97.3 (GND), U98.3 (GND), U99.3 (GND), U100.3 (GND), U101.3 (GND), U102.3 (GND), U103.3 (GND), U104.3 (GND), U105.3 (GND), U106.3 (GND), U107.3 (GND), U108.3 (GND), U109.3 (GND), U110.3 (GND), U111.3 (GND), U112.3 (GND), U113.3 (GND), U114.3 (GND), U115.3 (GND), U116.3 (GND), U117.3 (GND), U118.3 (GND), U119.3 (GND), U120.3 (GND), U121.3 (GND), U122.3 (GND), U123.3 (GND), U124.3 (GND), U125.3 (GND), U126.3 (GND), U127.3 (GND), U128.3 (GND); also elsewhere on the board
unnamed: U65.5 (CO), U66.2 (CI)
unnamed: U65.6 (DO), U66.1 (DI)
unnamed: U66.5 (CO), U67.2 (CI)
unnamed: U66.6 (DO), U67.1 (DI)
unnamed: U67.5 (CO), U68.2 (CI)
unnamed: U67.6 (DO), U68.1 (DI)
unnamed: U68.5 (CO), U69.2 (CI)
unnamed: U68.6 (DO), U69.1 (DI)
unnamed: U69.5 (CO), U70.2 (CI)
unnamed: U69.6 (DO), U70.1 (DI)
unnamed: U70.5 (CO), U71.2 (CI)
unnamed: U70.6 (DO), U71.1 (DI)
unnamed: U71.5 (CO), U72.2 (CI)
unnamed: U71.6 (DO), U72.1 (DI)
unnamed: U72.5 (CO), U73.2 (CI)
unnamed: U72.6 (DO), U73.1 (DI)
unnamed: U73.5 (CO), U74.2 (CI)
unnamed: U73.6 (DO), U74.1 (DI)
unnamed: U74.5 (CO), U75.2 (CI)
unnamed: U74.6 (DO), U75.1 (DI)
unnamed: U75.5 (CO), U76.2 (CI)
unnamed: U75.6 (DO), U76.1 (DI)
unnamed: U76.5 (CO), U77.2 (CI)
unnamed: U76.6 (DO), U77.1 (DI)
unnamed: U77.5 (CO), U78.2 (CI)
unnamed: U77.6 (DO), U78.1 (DI)
unnamed: U78.5 (CO), U79.2 (CI)
unnamed: U78.6 (DO), U79.1 (DI)
unnamed: U79.5 (CO), U80.2 (CI)
unnamed: U79.6 (DO), U80.1 (DI)
unnamed: U80.5 (CO), U81.2 (CI)
unnamed: U80.6 (DO), U81.1 (DI)
unnamed: U81.5 (CO), U82.2 (CI)
unnamed: U81.6 (DO), U82.1 (DI)
unnamed: U82.5 (CO), U83.2 (CI)
unnamed: U82.6 (DO), U83.1 (DI)
unnamed: U83.5 (CO), U84.2 (CI)
unnamed: U83.6 (DO), U84.1 (DI)
unnamed: U84.5 (CO), U85.2 (CI)
unnamed: U84.6 (DO), U85.1 (DI)
unnamed: U85.5 (CO), U86.2 (CI)
unnamed: U85.6 (DO), U86.1 (DI)
unnamed: U86.5 (CO), U87.2 (CI)
unnamed: U86.6 (DO), U87.1 (DI)
unnamed: U87.5 (CO), U88.2 (CI)
unnamed: U87.6 (DO), U88.1 (DI)
unnamed: U88.5 (CO), U89.2 (CI)
unnamed: U88.6 (DO), U89.1 (DI)
unnamed: U89.5 (CO), U90.2 (CI)
unnamed: U89.6 (DO), U90.1 (DI)
unnamed: U90.5 (CO), U91.2 (CI)
unnamed: U90.6 (DO), U91.1 (DI)
unnamed: U91.5 (CO), U92.2 (CI)
unnamed: U91.6 (DO), U92.1 (DI)
unnamed: U92.5 (CO), U93.2 (CI)
unnamed: U92.6 (DO), U93.1 (DI)
unnamed: U93.5 (CO), U94.2 (CI)
unnamed: U93.6 (DO), U94.1 (DI)
unnamed: U94.5 (CO), U95.2 (CI)
unnamed: U94.6 (DO), U95.1 (DI)
unnamed: U95.5 (CO), U96.2 (CI)
unnamed: U95.6 (DO), U96.1 (DI)
unnamed: U96.5 (CO), U97.2 (CI)
unnamed: U96.6 (DO), U97.1 (DI)
unnamed: U97.5 (CO), U98.2 (CI)
unnamed: U97.6 (DO), U98.1 (DI)
unnamed: U98.5 (CO), U99.2 (CI)
unnamed: U98.6 (DO), U99.1 (DI)
unnamed: U99.6 (DO), U100.1 (DI)
unnamed: U99.5 (CO), U100.2 (CI)
unnamed: U100.5 (CO), U101.2 (CI)
unnamed: U100.6 (DO), U101.1 (DI)
unnamed: U101.5 (CO), U102.2 (CI)
unnamed: U101.6 (DO), U102.1 (DI)
unnamed: U102.5 (CO), U103.2 (CI)
unnamed: U102.6 (DO), U103.1 (DI)
unnamed: U103.5 (CO), U104.2 (CI)
unnamed: U103.6 (DO), U104.1 (DI)
unnamed: U104.5 (CO), U105.2 (CI)
unnamed: U104.6 (DO), U105.1 (DI)
unnamed: U105.5 (CO), U106.2 (CI)
unnamed: U105.6 (DO), U106.1 (DI)
unnamed: U106.5 (CO), U107.2 (CI)
unnamed: U106.6 (DO), U107.1 (DI)
unnamed: U107.5 (CO), U108.2 (CI)
unnamed: U107.6 (DO), U108.1 (DI)
unnamed: U108.5 (CO), U109.2 (CI)
unnamed: U108.6 (DO), U109.1 (DI)
unnamed: U109.5 (CO), U110.2 (CI)
unnamed: U109.6 (DO), U110.1 (DI)
unnamed: U110.5 (CO), U111.2 (CI)
unnamed: U110.6 (DO), U111.1 (DI)
unnamed: U111.5 (CO), U112.2 (CI)
unnamed: U111.6 (DO), U112.1 (DI)
unnamed: U112.5 (CO), U113.2 (CI)
unnamed: U112.6 (DO), U113.1 (DI)
unnamed: U113.5 (CO), U114.2 (CI)
unnamed: U113.6 (DO), U114.1 (DI)
unnamed: U114.5 (CO), U115.2 (CI)
unnamed: U114.6 (DO), U115.1 (DI)
unnamed: U115.5 (CO), U116.2 (CI)
unnamed: U115.6 (DO), U116.1 (DI)
unnamed: U116.5 (CO), U117.2 (CI)
unnamed: U116.6 (DO), U117.1 (DI)
unnamed: U117.5 (CO), U118.2 (CI)
unnamed: U117.6 (DO), U118.1 (DI)
unnamed: U118.5 (CO), U119.2 (CI)
unnamed: U118.6 (DO), U119.1 (DI)
unnamed: U119.5 (CO), U120.2 (CI)
unnamed: U119.6 (DO), U120.1 (DI)
unnamed: U120.5 (CO), U121.2 (CI)
unnamed: U120.6 (DO), U121.1 (DI)
unnamed: U121.5 (CO), U122.2 (CI)
unnamed: U121.6 (DO), U122.1 (DI)
unnamed: U122.5 (CO), U123.2 (CI)
unnamed: U122.6 (DO), U123.1 (DI)
unnamed: U123.5 (CO), U124.2 (CI)
unnamed: U123.6 (DO), U124.1 (DI)
unnamed: U124.5 (CO), U125.2 (CI)
unnamed: U124.6 (DO), U125.1 (DI)
unnamed: U125.5 (CO), U126.2 (CI)
unnamed: U125.6 (DO), U126.1 (DI)
unnamed: U126.5 (CO), U127.2 (CI)
unnamed: U126.6 (DO), U127.1 (DI)
unnamed: U127.5 (CO), U128.2 (CI)
unnamed: U127.6 (DO), U128.1 (DI)

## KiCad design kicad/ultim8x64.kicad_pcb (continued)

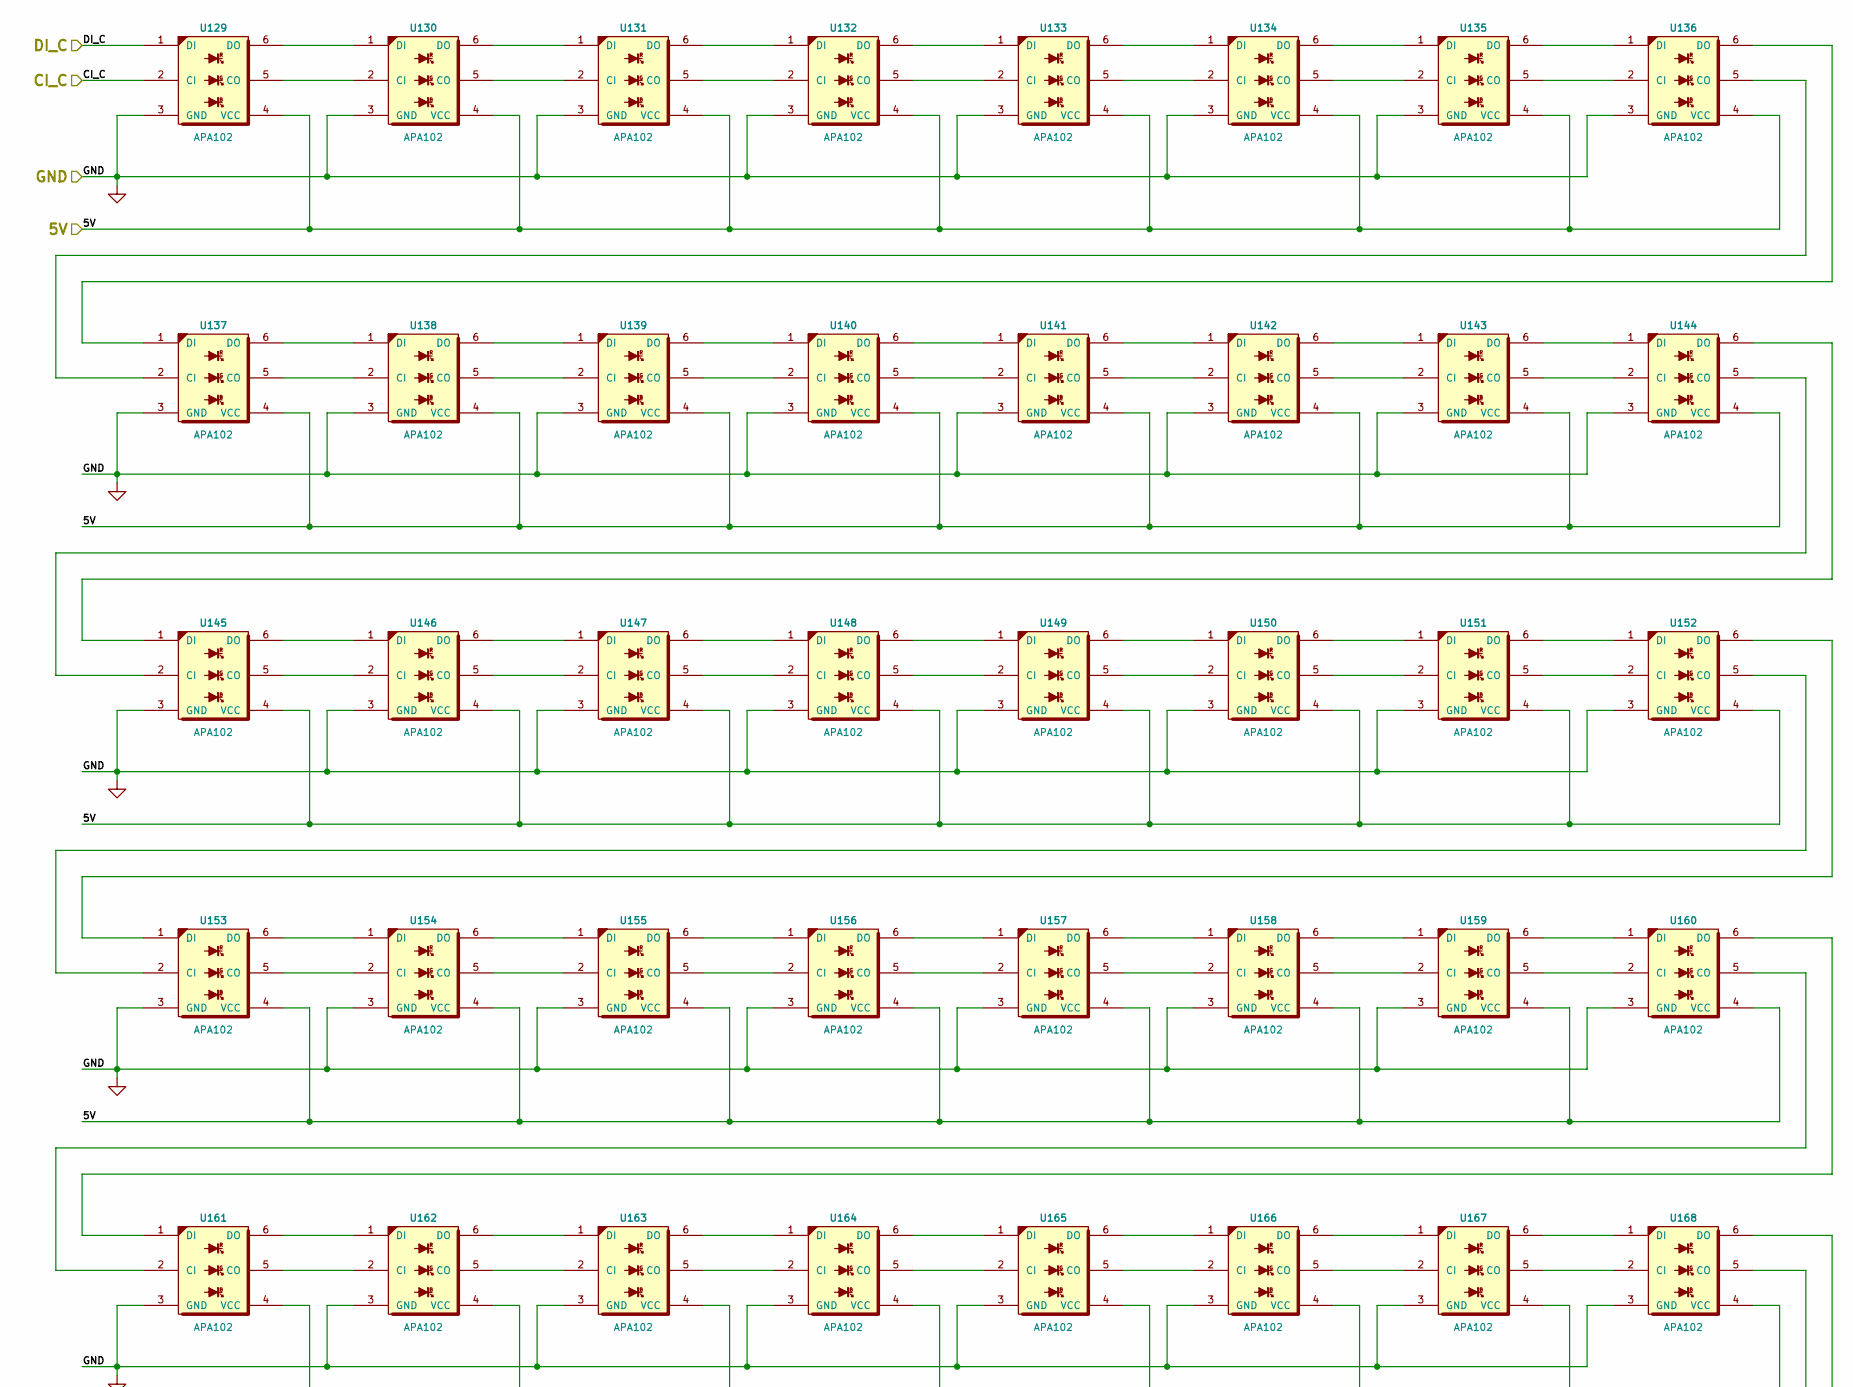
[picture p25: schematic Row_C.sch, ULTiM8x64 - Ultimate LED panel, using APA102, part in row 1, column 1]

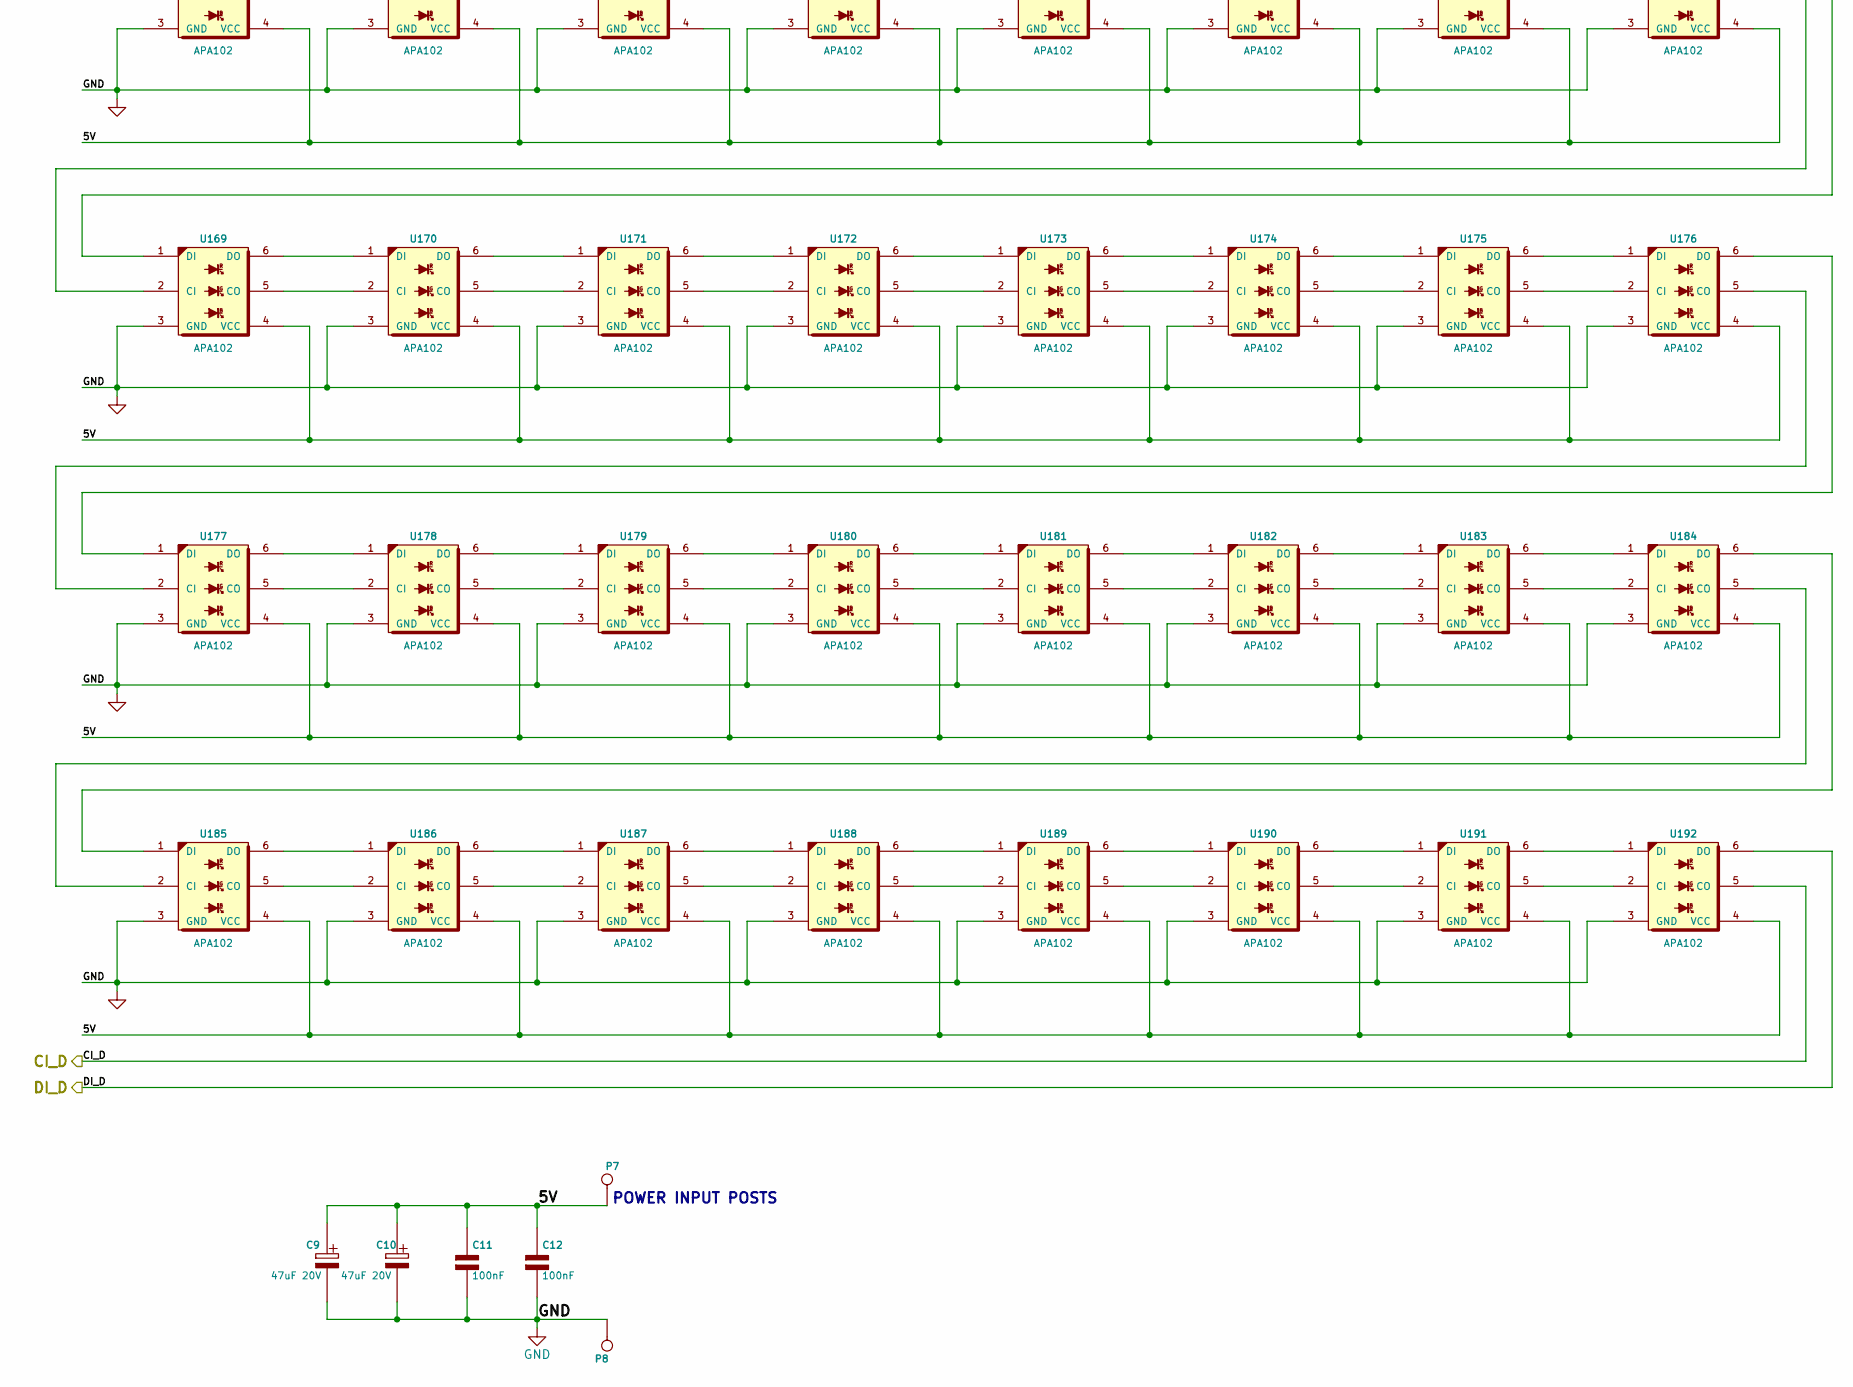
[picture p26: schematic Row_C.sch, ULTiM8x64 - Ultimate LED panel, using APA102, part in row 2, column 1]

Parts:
C9, C10: 47uF 20V; c_2917
C11, C12: 100nF; c_0805
P7: 5V; PowerIn_stud
P8: GND; PowerIn_stud
U129, U130, U131, U132, U135, U136, U137, U138, U141, U142, U143, U144, U145, U146, U148, U149, U150, U151, U152, U153, U154, U155, U156, U157, U158, U159, U160, U161, U162, U163, U164, U165, U167, U168, U169, U170, U172, U173, U174, U175, U176, U177, U178, U179, U180, U183, U184, U185, U186, U189, U190, U191, U192: APA102
U133: APA102; APA102_U05
U134: APA102; APA102_U06
U139: APA102; APA102_U11
U140: APA102; APA102_U12
U147: APA102; APA102_U19
U166: APA102; APA102_U38
U171: APA102; APA102_U43
U181: APA102; APA102_U53
U182: APA102; APA102_U54
U187: APA102; APA102_U59
U188: APA102; APA102_U60

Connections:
/Row_A/5V: C9.1 (+), C10.1 (+), C11.1, C12.1, P7.1, U129.4 (VCC), U130.4 (VCC), U131.4 (VCC), U132.4 (VCC), U133.4 (VCC), U134.4 (VCC), U135.4 (VCC), U136.4 (VCC), U137.4 (VCC), U138.4 (VCC), U139.4 (VCC), U140.4 (VCC), U141.4 (VCC), U142.4 (VCC), U143.4 (VCC), U144.4 (VCC), U145.4 (VCC), U146.4 (VCC), U147.4 (VCC), U148.4 (VCC), U149.4 (VCC), U150.4 (VCC), U151.4 (VCC), U152.4 (VCC), U153.4 (VCC), U154.4 (VCC), U155.4 (VCC), U156.4 (VCC), U157.4 (VCC), U158.4 (VCC), U159.4 (VCC), U160.4 (VCC), U161.4 (VCC), U162.4 (VCC), U163.4 (VCC), U164.4 (VCC), U165.4 (VCC), U166.4 (VCC), U167.4 (VCC), U168.4 (VCC), U169.4 (VCC), U170.4 (VCC), U171.4 (VCC), U172.4 (VCC), U173.4 (VCC), U174.4 (VCC), U175.4 (VCC), U176.4 (VCC), U177.4 (VCC), U178.4 (VCC), U179.4 (VCC), U180.4 (VCC), U181.4 (VCC), U182.4 (VCC), U183.4 (VCC), U184.4 (VCC), U185.4 (VCC), U186.4 (VCC), U187.4 (VCC), U188.4 (VCC), U189.4 (VCC), U190.4 (VCC), U191.4 (VCC), U192.4 (VCC); also elsewhere on the board
/Row_B/CI_C: U129.2 (CI); also elsewhere on the board
/Row_B/DI_C: U129.1 (DI); also elsewhere on the board
/Row_C/CI_D: U192.5 (CO); also elsewhere on the board
/Row_C/DI_D: U192.6 (DO); also elsewhere on the board
GND: C9.2 (-), C10.2 (-), C11.2, C12.2, P8.1, U129.3 (GND), U130.3 (GND), U131.3 (GND), U132.3 (GND), U133.3 (GND), U134.3 (GND), U135.3 (GND), U136.3 (GND), U137.3 (GND), U138.3 (GND), U139.3 (GND), U140.3 (GND), U141.3 (GND), U142.3 (GND), U143.3 (GND), U144.3 (GND), U145.3 (GND), U146.3 (GND), U147.3 (GND), U148.3 (GND), U149.3 (GND), U150.3 (GND), U151.3 (GND), U152.3 (GND), U153.3 (GND), U154.3 (GND), U155.3 (GND), U156.3 (GND), U157.3 (GND), U158.3 (GND), U159.3 (GND), U160.3 (GND), U161.3 (GND), U162.3 (GND), U163.3 (GND), U164.3 (GND), U165.3 (GND), U166.3 (GND), U167.3 (GND), U168.3 (GND), U169.3 (GND), U170.3 (GND), U171.3 (GND), U172.3 (GND), U173.3 (GND), U174.3 (GND), U175.3 (GND), U176.3 (GND), U177.3 (GND), U178.3 (GND), U179.3 (GND), U180.3 (GND), U181.3 (GND), U182.3 (GND), U183.3 (GND), U184.3 (GND), U185.3 (GND), U186.3 (GND), U187.3 (GND), U188.3 (GND), U189.3 (GND), U190.3 (GND), U191.3 (GND), U192.3 (GND); also elsewhere on the board
unnamed: U129.5 (CO), U130.2 (CI)
unnamed: U129.6 (DO), U130.1 (DI)
unnamed: U130.5 (CO), U131.2 (CI)
unnamed: U130.6 (DO), U131.1 (DI)
unnamed: U131.5 (CO), U132.2 (CI)
unnamed: U131.6 (DO), U132.1 (DI)
unnamed: U132.5 (CO), U133.2 (CI)
unnamed: U132.6 (DO), U133.1 (DI)
unnamed: U133.5 (CO), U134.2 (CI)
unnamed: U133.6 (DO), U134.1 (DI)
unnamed: U134.5 (CO), U135.2 (CI)
unnamed: U134.6 (DO), U135.1 (DI)
unnamed: U135.5 (CO), U136.2 (CI)
unnamed: U135.6 (DO), U136.1 (DI)
unnamed: U136.5 (CO), U137.2 (CI)
unnamed: U136.6 (DO), U137.1 (DI)
unnamed: U137.5 (CO), U138.2 (CI)
unnamed: U137.6 (DO), U138.1 (DI)
unnamed: U138.5 (CO), U139.2 (CI)
unnamed: U138.6 (DO), U139.1 (DI)
unnamed: U139.5 (CO), U140.2 (CI)
unnamed: U139.6 (DO), U140.1 (DI)
unnamed: U140.5 (CO), U141.2 (CI)
unnamed: U140.6 (DO), U141.1 (DI)
unnamed: U141.5 (CO), U142.2 (CI)
unnamed: U141.6 (DO), U142.1 (DI)
unnamed: U142.5 (CO), U143.2 (CI)
unnamed: U142.6 (DO), U143.1 (DI)
unnamed: U143.5 (CO), U144.2 (CI)
unnamed: U143.6 (DO), U144.1 (DI)
unnamed: U144.5 (CO), U145.2 (CI)
unnamed: U144.6 (DO), U145.1 (DI)
unnamed: U145.5 (CO), U146.2 (CI)
unnamed: U145.6 (DO), U146.1 (DI)
unnamed: U146.5 (CO), U147.2 (CI)
unnamed: U146.6 (DO), U147.1 (DI)
unnamed: U147.5 (CO), U148.2 (CI)
unnamed: U147.6 (DO), U148.1 (DI)
unnamed: U148.5 (CO), U149.2 (CI)
unnamed: U148.6 (DO), U149.1 (DI)
unnamed: U149.5 (CO), U150.2 (CI)
unnamed: U149.6 (DO), U150.1 (DI)
unnamed: U150.5 (CO), U151.2 (CI)
unnamed: U150.6 (DO), U151.1 (DI)
unnamed: U151.5 (CO), U152.2 (CI)
unnamed: U151.6 (DO), U152.1 (DI)
unnamed: U152.5 (CO), U153.2 (CI)
unnamed: U152.6 (DO), U153.1 (DI)
unnamed: U153.5 (CO), U154.2 (CI)
unnamed: U153.6 (DO), U154.1 (DI)
unnamed: U154.5 (CO), U155.2 (CI)
unnamed: U154.6 (DO), U155.1 (DI)
unnamed: U155.5 (CO), U156.2 (CI)
unnamed: U155.6 (DO), U156.1 (DI)
unnamed: U156.5 (CO), U157.2 (CI)
unnamed: U156.6 (DO), U157.1 (DI)
unnamed: U157.5 (CO), U158.2 (CI)
unnamed: U157.6 (DO), U158.1 (DI)
unnamed: U158.5 (CO), U159.2 (CI)
unnamed: U158.6 (DO), U159.1 (DI)
unnamed: U159.5 (CO), U160.2 (CI)
unnamed: U159.6 (DO), U160.1 (DI)
unnamed: U160.5 (CO), U161.2 (CI)
unnamed: U160.6 (DO), U161.1 (DI)
unnamed: U161.5 (CO), U162.2 (CI)
unnamed: U161.6 (DO), U162.1 (DI)
unnamed: U162.5 (CO), U163.2 (CI)
unnamed: U162.6 (DO), U163.1 (DI)
unnamed: U163.5 (CO), U164.2 (CI)
unnamed: U163.6 (DO), U164.1 (DI)
unnamed: U164.5 (CO), U165.2 (CI)
unnamed: U164.6 (DO), U165.1 (DI)
unnamed: U165.5 (CO), U166.2 (CI)
unnamed: U165.6 (DO), U166.1 (DI)
unnamed: U166.5 (CO), U167.2 (CI)
unnamed: U166.6 (DO), U167.1 (DI)
unnamed: U167.5 (CO), U168.2 (CI)
unnamed: U167.6 (DO), U168.1 (DI)
unnamed: U168.5 (CO), U169.2 (CI)
unnamed: U168.6 (DO), U169.1 (DI)
unnamed: U169.5 (CO), U170.2 (CI)
unnamed: U169.6 (DO), U170.1 (DI)
unnamed: U170.5 (CO), U171.2 (CI)
unnamed: U170.6 (DO), U171.1 (DI)
unnamed: U171.5 (CO), U172.2 (CI)
unnamed: U171.6 (DO), U172.1 (DI)
unnamed: U172.5 (CO), U173.2 (CI)
unnamed: U172.6 (DO), U173.1 (DI)
unnamed: U173.5 (CO), U174.2 (CI)
unnamed: U173.6 (DO), U174.1 (DI)
unnamed: U174.5 (CO), U175.2 (CI)
unnamed: U174.6 (DO), U175.1 (DI)
unnamed: U175.5 (CO), U176.2 (CI)
unnamed: U175.6 (DO), U176.1 (DI)
unnamed: U176.5 (CO), U177.2 (CI)
unnamed: U176.6 (DO), U177.1 (DI)
unnamed: U177.5 (CO), U178.2 (CI)
unnamed: U177.6 (DO), U178.1 (DI)
unnamed: U178.5 (CO), U179.2 (CI)
unnamed: U178.6 (DO), U179.1 (DI)
unnamed: U179.5 (CO), U180.2 (CI)
unnamed: U179.6 (DO), U180.1 (DI)
unnamed: U180.5 (CO), U181.2 (CI)
unnamed: U180.6 (DO), U181.1 (DI)
unnamed: U181.5 (CO), U182.2 (CI)
unnamed: U181.6 (DO), U182.1 (DI)
unnamed: U182.5 (CO), U183.2 (CI)
unnamed: U182.6 (DO), U183.1 (DI)
unnamed: U183.5 (CO), U184.2 (CI)
unnamed: U183.6 (DO), U184.1 (DI)
unnamed: U184.5 (CO), U185.2 (CI)
unnamed: U184.6 (DO), U185.1 (DI)
unnamed: U185.5 (CO), U186.2 (CI)
unnamed: U185.6 (DO), U186.1 (DI)
unnamed: U186.5 (CO), U187.2 (CI)
unnamed: U186.6 (DO), U187.1 (DI)
unnamed: U187.5 (CO), U188.2 (CI)
unnamed: U187.6 (DO), U188.1 (DI)
unnamed: U188.5 (CO), U189.2 (CI)
unnamed: U188.6 (DO), U189.1 (DI)
unnamed: U189.5 (CO), U190.2 (CI)
unnamed: U189.6 (DO), U190.1 (DI)
unnamed: U190.5 (CO), U191.2 (CI)
unnamed: U190.6 (DO), U191.1 (DI)
unnamed: U191.5 (CO), U192.2 (CI)
unnamed: U191.6 (DO), U192.1 (DI)

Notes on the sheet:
POWER INPUT POSTS

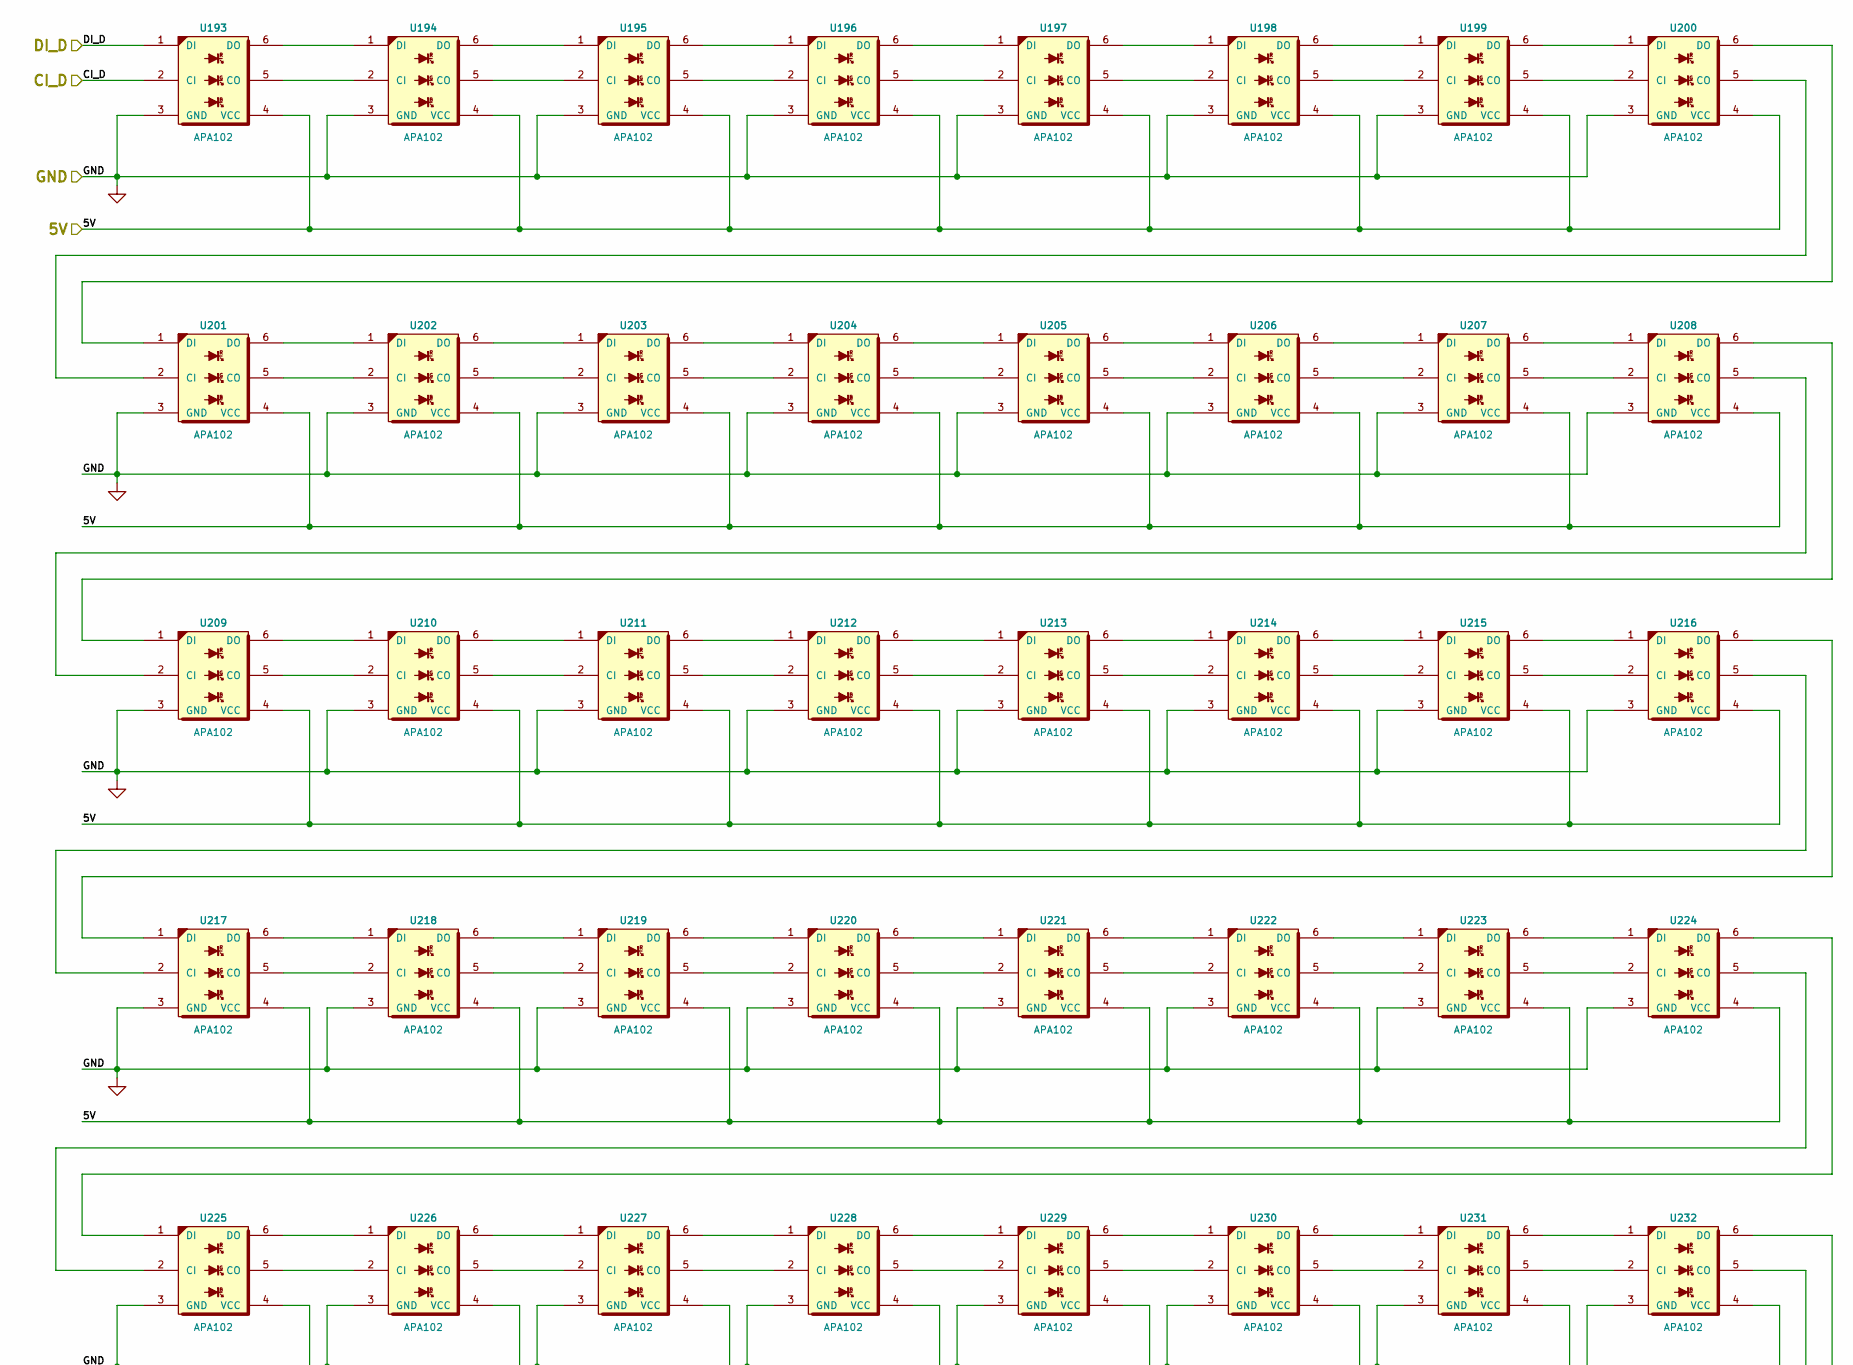
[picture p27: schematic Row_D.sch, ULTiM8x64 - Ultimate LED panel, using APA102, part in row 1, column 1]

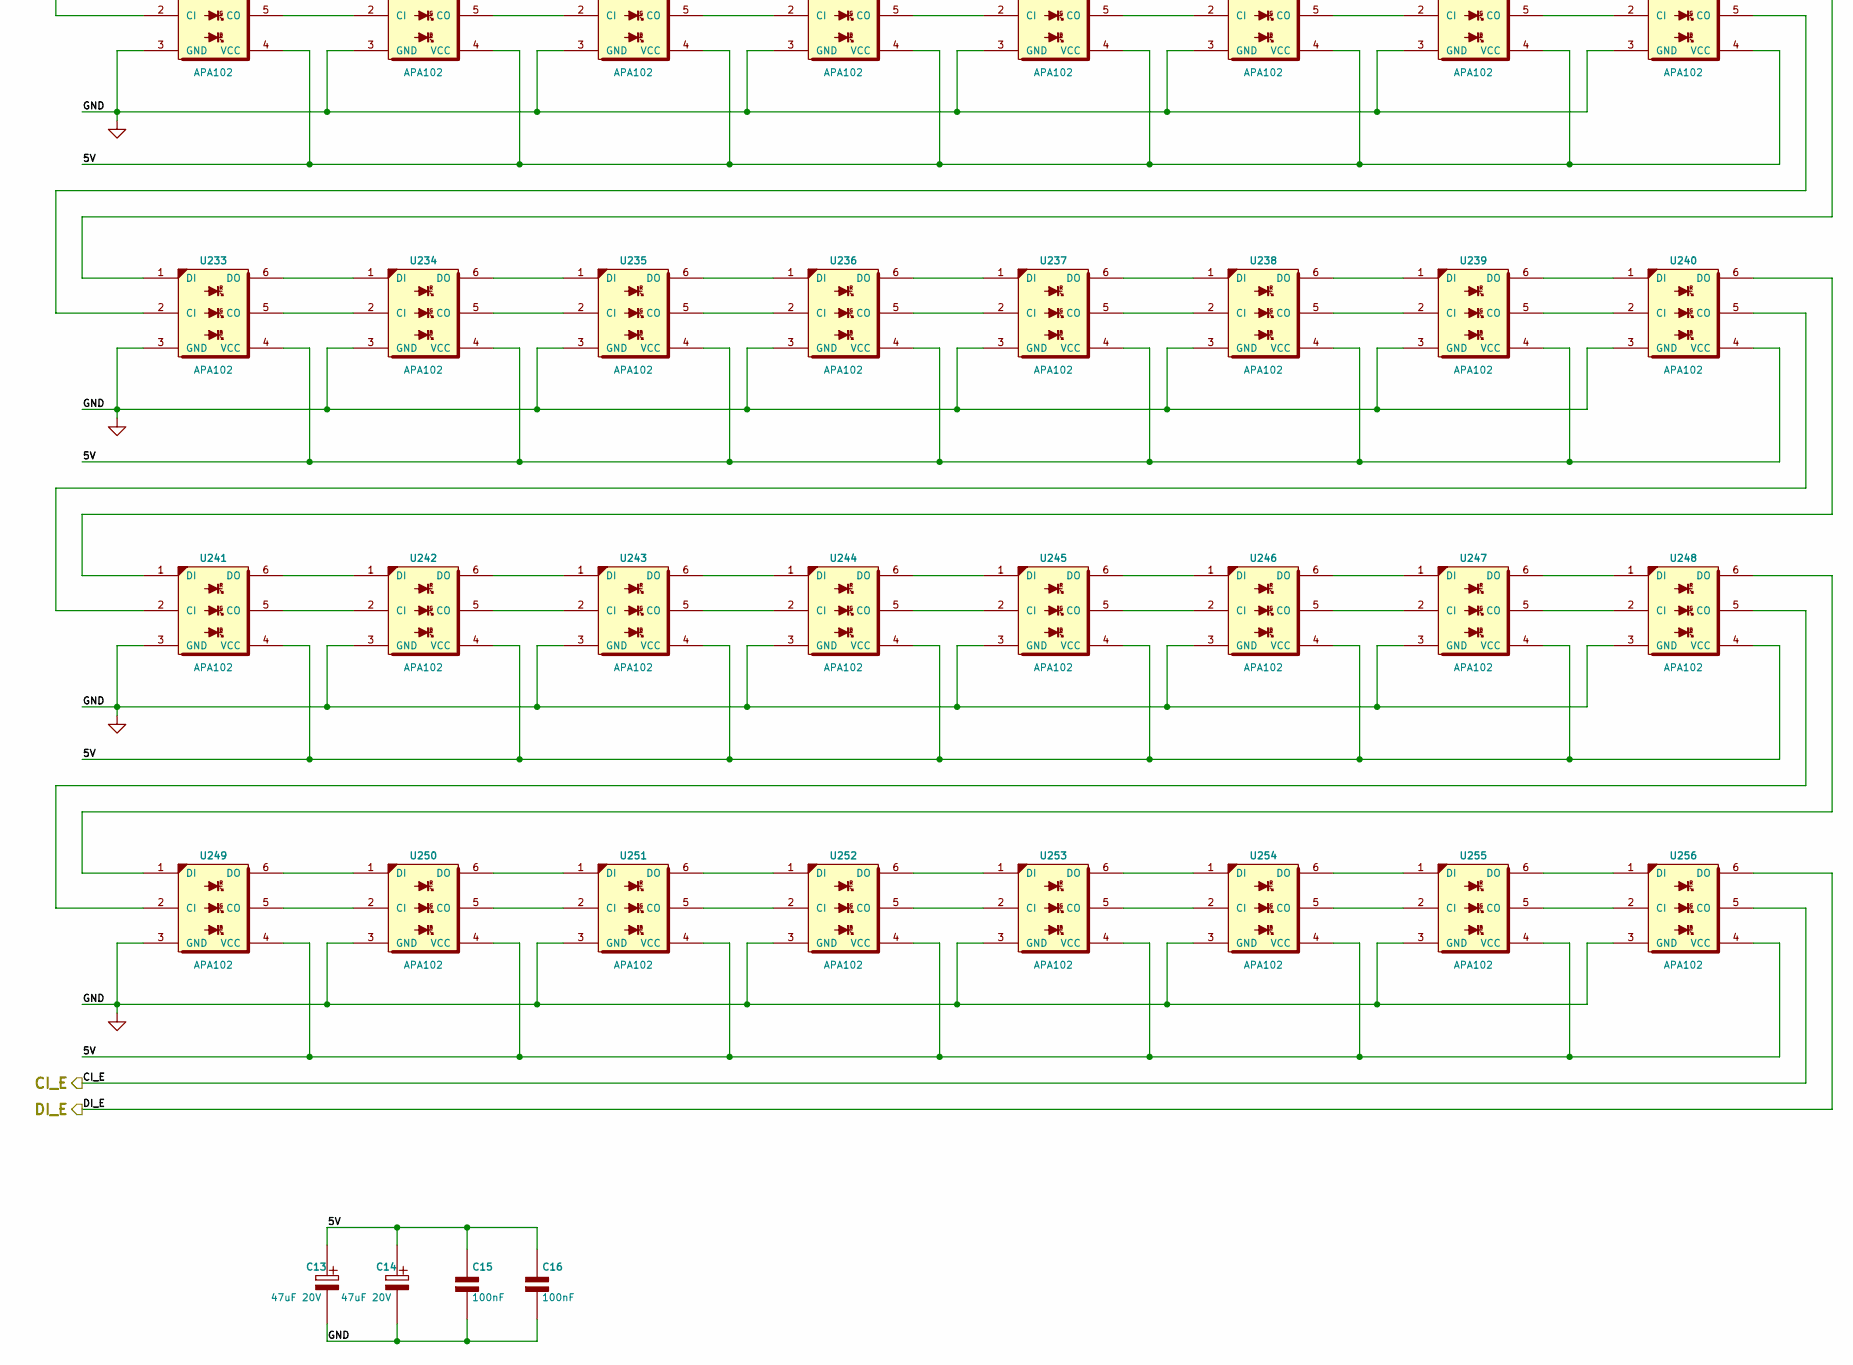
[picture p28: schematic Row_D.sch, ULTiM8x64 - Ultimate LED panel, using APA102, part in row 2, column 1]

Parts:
C13, C14: 47uF 20V; c_2917
C15, C16: 100nF; c_0805
U193, U194, U195, U196, U197, U198, U199, U200, U201, U202, U203, U204, U205, U206, U207, U208, U209, U210, U211, U212, U213, U214, U215, U216, U217, U218, U219, U220, U221, U222, U223, U224, U225, U226, U227, U228, U229, U230, U231, U232, U233, U234, U235, U236, U237, U238, U239, U240, U241, U242, U243, U244, U245, U246, U247, U248, U249, U250, U251, U252, U253, U254, U255, U256: APA102

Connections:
/Row_A/5V: C13.1 (+), C14.1 (+), C15.1, C16.1, U193.4 (VCC), U194.4 (VCC), U195.4 (VCC), U196.4 (VCC), U197.4 (VCC), U198.4 (VCC), U199.4 (VCC), U200.4 (VCC), U201.4 (VCC), U202.4 (VCC), U203.4 (VCC), U204.4 (VCC), U205.4 (VCC), U206.4 (VCC), U207.4 (VCC), U208.4 (VCC), U209.4 (VCC), U210.4 (VCC), U211.4 (VCC), U212.4 (VCC), U213.4 (VCC), U214.4 (VCC), U215.4 (VCC), U216.4 (VCC), U217.4 (VCC), U218.4 (VCC), U219.4 (VCC), U220.4 (VCC), U221.4 (VCC), U222.4 (VCC), U223.4 (VCC), U224.4 (VCC), U225.4 (VCC), U226.4 (VCC), U227.4 (VCC), U228.4 (VCC), U229.4 (VCC), U230.4 (VCC), U231.4 (VCC), U232.4 (VCC), U233.4 (VCC), U234.4 (VCC), U235.4 (VCC), U236.4 (VCC), U237.4 (VCC), U238.4 (VCC), U239.4 (VCC), U240.4 (VCC), U241.4 (VCC), U242.4 (VCC), U243.4 (VCC), U244.4 (VCC), U245.4 (VCC), U246.4 (VCC), U247.4 (VCC), U248.4 (VCC), U249.4 (VCC), U250.4 (VCC), U251.4 (VCC), U252.4 (VCC), U253.4 (VCC), U254.4 (VCC), U255.4 (VCC), U256.4 (VCC); also elsewhere on the board
/Row_C/CI_D: U193.2 (CI); also elsewhere on the board
/Row_C/DI_D: U193.1 (DI); also elsewhere on the board
/Row_D/CI_E: U256.5 (CO); also elsewhere on the board
/Row_D/DI_E: U256.6 (DO); also elsewhere on the board
GND: C13.2 (-), C14.2 (-), C15.2, C16.2, U193.3 (GND), U194.3 (GND), U195.3 (GND), U196.3 (GND), U197.3 (GND), U198.3 (GND), U199.3 (GND), U200.3 (GND), U201.3 (GND), U202.3 (GND), U203.3 (GND), U204.3 (GND), U205.3 (GND), U206.3 (GND), U207.3 (GND), U208.3 (GND), U209.3 (GND), U210.3 (GND), U211.3 (GND), U212.3 (GND), U213.3 (GND), U214.3 (GND), U215.3 (GND), U216.3 (GND), U217.3 (GND), U218.3 (GND), U219.3 (GND), U220.3 (GND), U221.3 (GND), U222.3 (GND), U223.3 (GND), U224.3 (GND), U225.3 (GND), U226.3 (GND), U227.3 (GND), U228.3 (GND), U229.3 (GND), U230.3 (GND), U231.3 (GND), U232.3 (GND), U233.3 (GND), U234.3 (GND), U235.3 (GND), U236.3 (GND), U237.3 (GND), U238.3 (GND), U239.3 (GND), U240.3 (GND), U241.3 (GND), U242.3 (GND), U243.3 (GND), U244.3 (GND), U245.3 (GND), U246.3 (GND), U247.3 (GND), U248.3 (GND), U249.3 (GND), U250.3 (GND), U251.3 (GND), U252.3 (GND), U253.3 (GND), U254.3 (GND), U255.3 (GND), U256.3 (GND); also elsewhere on the board
unnamed: U193.5 (CO), U194.2 (CI)
unnamed: U193.6 (DO), U194.1 (DI)
unnamed: U194.5 (CO), U195.2 (CI)
unnamed: U194.6 (DO), U195.1 (DI)
unnamed: U195.5 (CO), U196.2 (CI)
unnamed: U195.6 (DO), U196.1 (DI)
unnamed: U196.5 (CO), U197.2 (CI)
unnamed: U196.6 (DO), U197.1 (DI)
unnamed: U197.5 (CO), U198.2 (CI)
unnamed: U197.6 (DO), U198.1 (DI)
unnamed: U198.5 (CO), U199.2 (CI)
unnamed: U198.6 (DO), U199.1 (DI)
unnamed: U199.5 (CO), U200.2 (CI)
unnamed: U199.6 (DO), U200.1 (DI)
unnamed: U200.5 (CO), U201.2 (CI)
unnamed: U200.6 (DO), U201.1 (DI)
unnamed: U201.5 (CO), U202.2 (CI)
unnamed: U201.6 (DO), U202.1 (DI)
unnamed: U202.5 (CO), U203.2 (CI)
unnamed: U202.6 (DO), U203.1 (DI)
unnamed: U203.5 (CO), U204.2 (CI)
unnamed: U203.6 (DO), U204.1 (DI)
unnamed: U204.5 (CO), U205.2 (CI)
unnamed: U204.6 (DO), U205.1 (DI)
unnamed: U205.5 (CO), U206.2 (CI)
unnamed: U205.6 (DO), U206.1 (DI)
unnamed: U206.5 (CO), U207.2 (CI)
unnamed: U206.6 (DO), U207.1 (DI)
unnamed: U207.5 (CO), U208.2 (CI)
unnamed: U207.6 (DO), U208.1 (DI)
unnamed: U208.5 (CO), U209.2 (CI)
unnamed: U208.6 (DO), U209.1 (DI)
unnamed: U209.5 (CO), U210.2 (CI)
unnamed: U209.6 (DO), U210.1 (DI)
unnamed: U210.5 (CO), U211.2 (CI)
unnamed: U210.6 (DO), U211.1 (DI)
unnamed: U211.5 (CO), U212.2 (CI)
unnamed: U211.6 (DO), U212.1 (DI)
unnamed: U212.5 (CO), U213.2 (CI)
unnamed: U212.6 (DO), U213.1 (DI)
unnamed: U213.5 (CO), U214.2 (CI)
unnamed: U213.6 (DO), U214.1 (DI)
unnamed: U214.5 (CO), U215.2 (CI)
unnamed: U214.6 (DO), U215.1 (DI)
unnamed: U215.5 (CO), U216.2 (CI)
unnamed: U215.6 (DO), U216.1 (DI)
unnamed: U216.5 (CO), U217.2 (CI)
unnamed: U216.6 (DO), U217.1 (DI)
unnamed: U217.5 (CO), U218.2 (CI)
unnamed: U217.6 (DO), U218.1 (DI)
unnamed: U218.5 (CO), U219.2 (CI)
unnamed: U218.6 (DO), U219.1 (DI)
unnamed: U219.5 (CO), U220.2 (CI)
unnamed: U219.6 (DO), U220.1 (DI)
unnamed: U220.5 (CO), U221.2 (CI)
unnamed: U220.6 (DO), U221.1 (DI)
unnamed: U221.5 (CO), U222.2 (CI)
unnamed: U221.6 (DO), U222.1 (DI)
unnamed: U222.5 (CO), U223.2 (CI)
unnamed: U222.6 (DO), U223.1 (DI)
unnamed: U223.5 (CO), U224.2 (CI)
unnamed: U223.6 (DO), U224.1 (DI)
unnamed: U224.5 (CO), U225.2 (CI)
unnamed: U224.6 (DO), U225.1 (DI)
unnamed: U225.5 (CO), U226.2 (CI)
unnamed: U225.6 (DO), U226.1 (DI)
unnamed: U226.5 (CO), U227.2 (CI)
unnamed: U226.6 (DO), U227.1 (DI)
unnamed: U227.5 (CO), U228.2 (CI)
unnamed: U227.6 (DO), U228.1 (DI)
unnamed: U228.5 (CO), U229.2 (CI)
unnamed: U228.6 (DO), U229.1 (DI)
unnamed: U229.5 (CO), U230.2 (CI)
unnamed: U229.6 (DO), U230.1 (DI)
unnamed: U230.5 (CO), U231.2 (CI)
unnamed: U230.6 (DO), U231.1 (DI)
unnamed: U231.5 (CO), U232.2 (CI)
unnamed: U231.6 (DO), U232.1 (DI)
unnamed: U232.5 (CO), U233.2 (CI)
unnamed: U232.6 (DO), U233.1 (DI)
unnamed: U233.5 (CO), U234.2 (CI)
unnamed: U233.6 (DO), U234.1 (DI)
unnamed: U234.5 (CO), U235.2 (CI)
unnamed: U234.6 (DO), U235.1 (DI)
unnamed: U235.5 (CO), U236.2 (CI)
unnamed: U235.6 (DO), U236.1 (DI)
unnamed: U236.5 (CO), U237.2 (CI)
unnamed: U236.6 (DO), U237.1 (DI)
unnamed: U237.5 (CO), U238.2 (CI)
unnamed: U237.6 (DO), U238.1 (DI)
unnamed: U238.5 (CO), U239.2 (CI)
unnamed: U238.6 (DO), U239.1 (DI)
unnamed: U239.5 (CO), U240.2 (CI)
unnamed: U239.6 (DO), U240.1 (DI)
unnamed: U240.5 (CO), U241.2 (CI)
unnamed: U240.6 (DO), U241.1 (DI)
unnamed: U241.5 (CO), U242.2 (CI)
unnamed: U241.6 (DO), U242.1 (DI)
unnamed: U242.5 (CO), U243.2 (CI)
unnamed: U242.6 (DO), U243.1 (DI)
unnamed: U243.5 (CO), U244.2 (CI)
unnamed: U243.6 (DO), U244.1 (DI)
unnamed: U244.5 (CO), U245.2 (CI)
unnamed: U244.6 (DO), U245.1 (DI)
unnamed: U245.5 (CO), U246.2 (CI)
unnamed: U245.6 (DO), U246.1 (DI)
unnamed: U246.5 (CO), U247.2 (CI)
unnamed: U246.6 (DO), U247.1 (DI)
unnamed: U247.5 (CO), U248.2 (CI)
unnamed: U247.6 (DO), U248.1 (DI)
unnamed: U248.5 (CO), U249.2 (CI)
unnamed: U248.6 (DO), U249.1 (DI)
unnamed: U249.5 (CO), U250.2 (CI)
unnamed: U249.6 (DO), U250.1 (DI)
unnamed: U250.5 (CO), U251.2 (CI)
unnamed: U250.6 (DO), U251.1 (DI)
unnamed: U251.5 (CO), U252.2 (CI)
unnamed: U251.6 (DO), U252.1 (DI)
unnamed: U252.5 (CO), U253.2 (CI)
unnamed: U252.6 (DO), U253.1 (DI)
unnamed: U253.5 (CO), U254.2 (CI)
unnamed: U253.6 (DO), U254.1 (DI)
unnamed: U254.5 (CO), U255.2 (CI)
unnamed: U254.6 (DO), U255.1 (DI)
unnamed: U255.5 (CO), U256.2 (CI)
unnamed: U255.6 (DO), U256.1 (DI)

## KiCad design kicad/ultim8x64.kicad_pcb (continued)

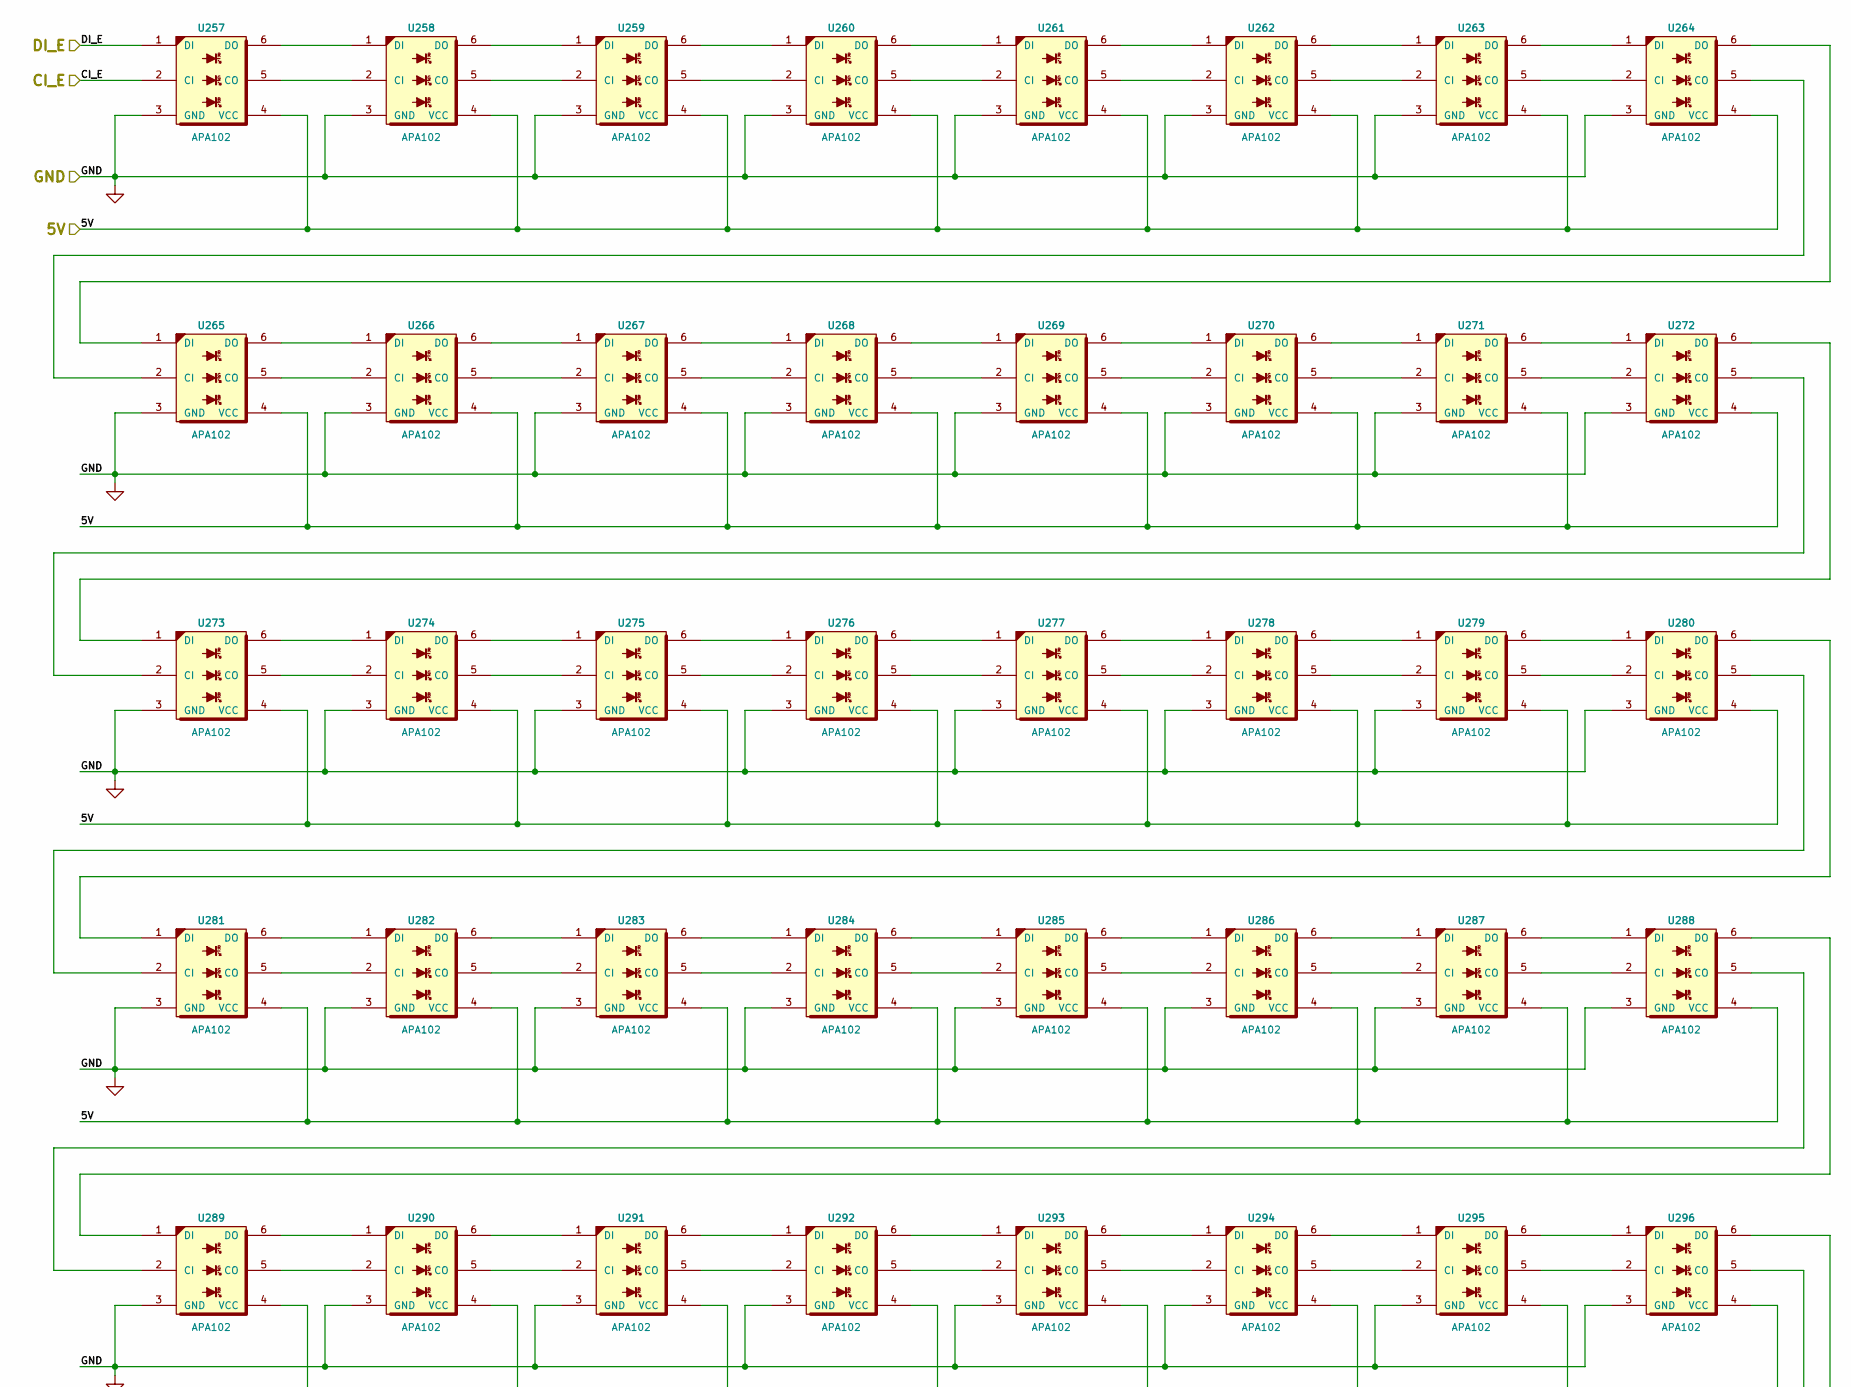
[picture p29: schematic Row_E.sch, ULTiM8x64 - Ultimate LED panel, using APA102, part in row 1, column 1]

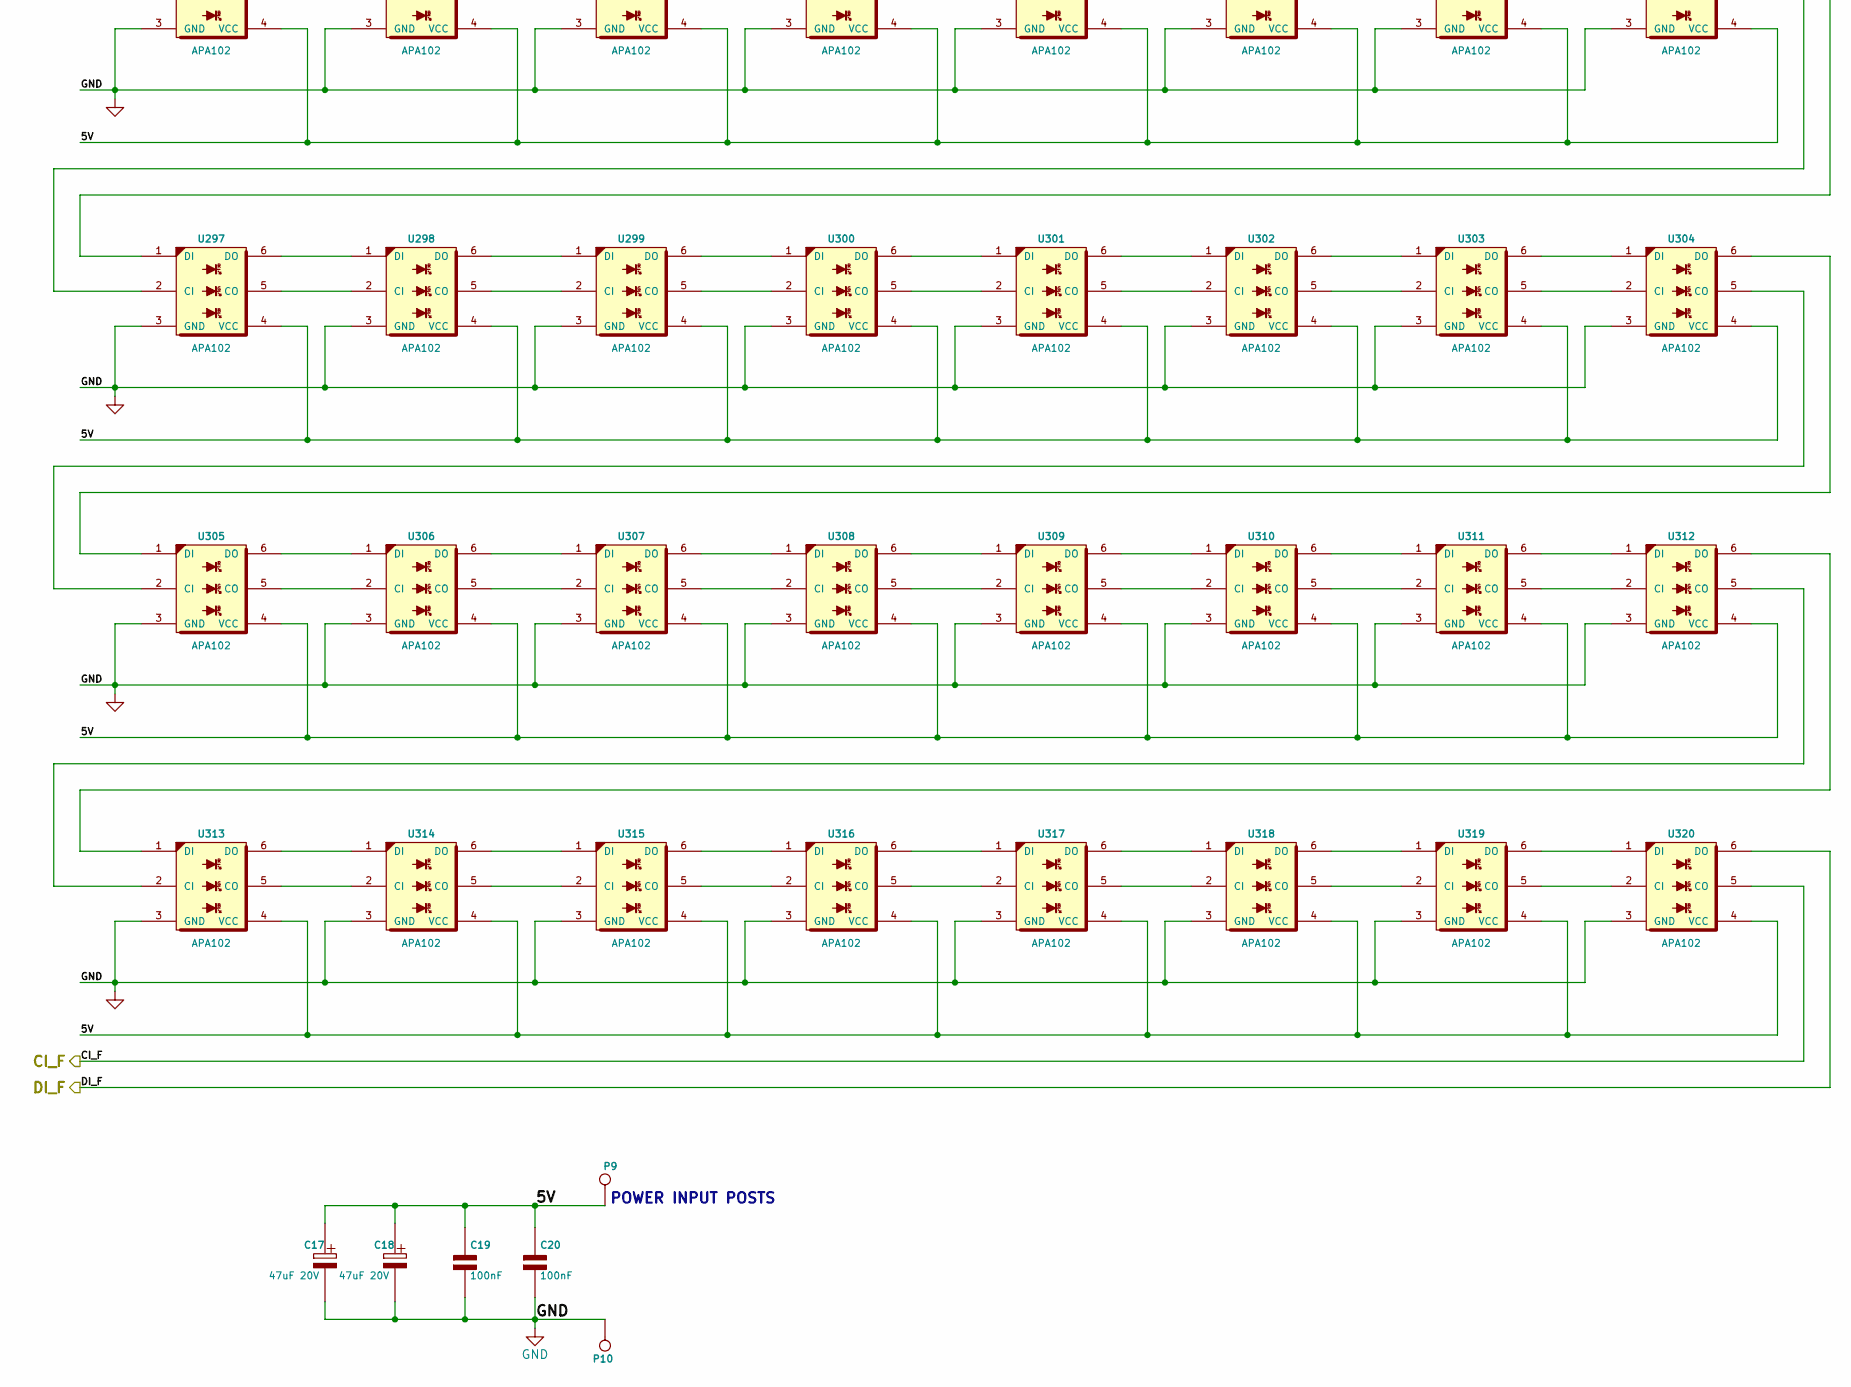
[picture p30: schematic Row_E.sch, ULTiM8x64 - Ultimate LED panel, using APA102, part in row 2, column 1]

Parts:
C17, C18: 47uF 20V; c_2917
C19, C20: 100nF; c_0805
P9: 5V; PowerIn_stud
P10: GND; PowerIn_stud
U257, U258, U259, U260, U263, U264, U265, U266, U269, U270, U271, U272, U273, U274, U276, U277, U278, U279, U280, U281, U282, U283, U284, U285, U286, U287, U288, U289, U290, U291, U292, U293, U295, U296, U297, U298, U300, U301, U302, U303, U304, U305, U306, U307, U308, U311, U312, U313, U314, U317, U318, U319, U320: APA102
U261: APA102; APA102_U05
U262: APA102; APA102_U06
U267: APA102; APA102_U11
U268: APA102; APA102_U12
U275: APA102; APA102_U19
U294: APA102; APA102_U38
U299: APA102; APA102_U43
U309: APA102; APA102_U53
U310: APA102; APA102_U54
U315: APA102; APA102_U59
U316: APA102; APA102_U60

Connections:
/Row_A/5V: C17.1 (+), C18.1 (+), C19.1, C20.1, P9.1, U257.4 (VCC), U258.4 (VCC), U259.4 (VCC), U260.4 (VCC), U261.4 (VCC), U262.4 (VCC), U263.4 (VCC), U264.4 (VCC), U265.4 (VCC), U266.4 (VCC), U267.4 (VCC), U268.4 (VCC), U269.4 (VCC), U270.4 (VCC), U271.4 (VCC), U272.4 (VCC), U273.4 (VCC), U274.4 (VCC), U275.4 (VCC), U276.4 (VCC), U277.4 (VCC), U278.4 (VCC), U279.4 (VCC), U280.4 (VCC), U281.4 (VCC), U282.4 (VCC), U283.4 (VCC), U284.4 (VCC), U285.4 (VCC), U286.4 (VCC), U287.4 (VCC), U288.4 (VCC), U289.4 (VCC), U290.4 (VCC), U291.4 (VCC), U292.4 (VCC), U293.4 (VCC), U294.4 (VCC), U295.4 (VCC), U296.4 (VCC), U297.4 (VCC), U298.4 (VCC), U299.4 (VCC), U300.4 (VCC), U301.4 (VCC), U302.4 (VCC), U303.4 (VCC), U304.4 (VCC), U305.4 (VCC), U306.4 (VCC), U307.4 (VCC), U308.4 (VCC), U309.4 (VCC), U310.4 (VCC), U311.4 (VCC), U312.4 (VCC), U313.4 (VCC), U314.4 (VCC), U315.4 (VCC), U316.4 (VCC), U317.4 (VCC), U318.4 (VCC), U319.4 (VCC), U320.4 (VCC); also elsewhere on the board
/Row_D/CI_E: U257.2 (CI); also elsewhere on the board
/Row_D/DI_E: U257.1 (DI); also elsewhere on the board
/Row_E/CI_F: U320.5 (CO); also elsewhere on the board
/Row_E/DI_F: U320.6 (DO); also elsewhere on the board
GND: C17.2 (-), C18.2 (-), C19.2, C20.2, P10.1, U257.3 (GND), U258.3 (GND), U259.3 (GND), U260.3 (GND), U261.3 (GND), U262.3 (GND), U263.3 (GND), U264.3 (GND), U265.3 (GND), U266.3 (GND), U267.3 (GND), U268.3 (GND), U269.3 (GND), U270.3 (GND), U271.3 (GND), U272.3 (GND), U273.3 (GND), U274.3 (GND), U275.3 (GND), U276.3 (GND), U277.3 (GND), U278.3 (GND), U279.3 (GND), U280.3 (GND), U281.3 (GND), U282.3 (GND), U283.3 (GND), U284.3 (GND), U285.3 (GND), U286.3 (GND), U287.3 (GND), U288.3 (GND), U289.3 (GND), U290.3 (GND), U291.3 (GND), U292.3 (GND), U293.3 (GND), U294.3 (GND), U295.3 (GND), U296.3 (GND), U297.3 (GND), U298.3 (GND), U299.3 (GND), U300.3 (GND), U301.3 (GND), U302.3 (GND), U303.3 (GND), U304.3 (GND), U305.3 (GND), U306.3 (GND), U307.3 (GND), U308.3 (GND), U309.3 (GND), U310.3 (GND), U311.3 (GND), U312.3 (GND), U313.3 (GND), U314.3 (GND), U315.3 (GND), U316.3 (GND), U317.3 (GND), U318.3 (GND), U319.3 (GND), U320.3 (GND); also elsewhere on the board
unnamed: U257.5 (CO), U258.2 (CI)
unnamed: U257.6 (DO), U258.1 (DI)
unnamed: U258.5 (CO), U259.2 (CI)
unnamed: U258.6 (DO), U259.1 (DI)
unnamed: U259.5 (CO), U260.2 (CI)
unnamed: U259.6 (DO), U260.1 (DI)
unnamed: U260.5 (CO), U261.2 (CI)
unnamed: U260.6 (DO), U261.1 (DI)
unnamed: U261.5 (CO), U262.2 (CI)
unnamed: U261.6 (DO), U262.1 (DI)
unnamed: U262.5 (CO), U263.2 (CI)
unnamed: U262.6 (DO), U263.1 (DI)
unnamed: U263.5 (CO), U264.2 (CI)
unnamed: U263.6 (DO), U264.1 (DI)
unnamed: U264.5 (CO), U265.2 (CI)
unnamed: U264.6 (DO), U265.1 (DI)
unnamed: U265.5 (CO), U266.2 (CI)
unnamed: U265.6 (DO), U266.1 (DI)
unnamed: U266.5 (CO), U267.2 (CI)
unnamed: U266.6 (DO), U267.1 (DI)
unnamed: U267.5 (CO), U268.2 (CI)
unnamed: U267.6 (DO), U268.1 (DI)
unnamed: U268.5 (CO), U269.2 (CI)
unnamed: U268.6 (DO), U269.1 (DI)
unnamed: U269.5 (CO), U270.2 (CI)
unnamed: U269.6 (DO), U270.1 (DI)
unnamed: U270.5 (CO), U271.2 (CI)
unnamed: U270.6 (DO), U271.1 (DI)
unnamed: U271.5 (CO), U272.2 (CI)
unnamed: U271.6 (DO), U272.1 (DI)
unnamed: U272.5 (CO), U273.2 (CI)
unnamed: U272.6 (DO), U273.1 (DI)
unnamed: U273.5 (CO), U274.2 (CI)
unnamed: U273.6 (DO), U274.1 (DI)
unnamed: U274.5 (CO), U275.2 (CI)
unnamed: U274.6 (DO), U275.1 (DI)
unnamed: U275.5 (CO), U276.2 (CI)
unnamed: U275.6 (DO), U276.1 (DI)
unnamed: U276.5 (CO), U277.2 (CI)
unnamed: U276.6 (DO), U277.1 (DI)
unnamed: U277.5 (CO), U278.2 (CI)
unnamed: U277.6 (DO), U278.1 (DI)
unnamed: U278.5 (CO), U279.2 (CI)
unnamed: U278.6 (DO), U279.1 (DI)
unnamed: U279.5 (CO), U280.2 (CI)
unnamed: U279.6 (DO), U280.1 (DI)
unnamed: U280.5 (CO), U281.2 (CI)
unnamed: U280.6 (DO), U281.1 (DI)
unnamed: U281.5 (CO), U282.2 (CI)
unnamed: U281.6 (DO), U282.1 (DI)
unnamed: U282.5 (CO), U283.2 (CI)
unnamed: U282.6 (DO), U283.1 (DI)
unnamed: U283.5 (CO), U284.2 (CI)
unnamed: U283.6 (DO), U284.1 (DI)
unnamed: U284.5 (CO), U285.2 (CI)
unnamed: U284.6 (DO), U285.1 (DI)
unnamed: U285.5 (CO), U286.2 (CI)
unnamed: U285.6 (DO), U286.1 (DI)
unnamed: U286.5 (CO), U287.2 (CI)
unnamed: U286.6 (DO), U287.1 (DI)
unnamed: U287.5 (CO), U288.2 (CI)
unnamed: U287.6 (DO), U288.1 (DI)
unnamed: U288.5 (CO), U289.2 (CI)
unnamed: U288.6 (DO), U289.1 (DI)
unnamed: U289.5 (CO), U290.2 (CI)
unnamed: U289.6 (DO), U290.1 (DI)
unnamed: U290.5 (CO), U291.2 (CI)
unnamed: U290.6 (DO), U291.1 (DI)
unnamed: U291.5 (CO), U292.2 (CI)
unnamed: U291.6 (DO), U292.1 (DI)
unnamed: U292.5 (CO), U293.2 (CI)
unnamed: U292.6 (DO), U293.1 (DI)
unnamed: U293.5 (CO), U294.2 (CI)
unnamed: U293.6 (DO), U294.1 (DI)
unnamed: U294.5 (CO), U295.2 (CI)
unnamed: U294.6 (DO), U295.1 (DI)
unnamed: U295.5 (CO), U296.2 (CI)
unnamed: U295.6 (DO), U296.1 (DI)
unnamed: U296.5 (CO), U297.2 (CI)
unnamed: U296.6 (DO), U297.1 (DI)
unnamed: U297.5 (CO), U298.2 (CI)
unnamed: U297.6 (DO), U298.1 (DI)
unnamed: U298.5 (CO), U299.2 (CI)
unnamed: U298.6 (DO), U299.1 (DI)
unnamed: U299.5 (CO), U300.2 (CI)
unnamed: U299.6 (DO), U300.1 (DI)
unnamed: U300.5 (CO), U301.2 (CI)
unnamed: U300.6 (DO), U301.1 (DI)
unnamed: U301.5 (CO), U302.2 (CI)
unnamed: U301.6 (DO), U302.1 (DI)
unnamed: U302.5 (CO), U303.2 (CI)
unnamed: U302.6 (DO), U303.1 (DI)
unnamed: U303.5 (CO), U304.2 (CI)
unnamed: U303.6 (DO), U304.1 (DI)
unnamed: U304.5 (CO), U305.2 (CI)
unnamed: U304.6 (DO), U305.1 (DI)
unnamed: U305.5 (CO), U306.2 (CI)
unnamed: U305.6 (DO), U306.1 (DI)
unnamed: U306.5 (CO), U307.2 (CI)
unnamed: U306.6 (DO), U307.1 (DI)
unnamed: U307.5 (CO), U308.2 (CI)
unnamed: U307.6 (DO), U308.1 (DI)
unnamed: U308.5 (CO), U309.2 (CI)
unnamed: U308.6 (DO), U309.1 (DI)
unnamed: U309.5 (CO), U310.2 (CI)
unnamed: U309.6 (DO), U310.1 (DI)
unnamed: U310.5 (CO), U311.2 (CI)
unnamed: U310.6 (DO), U311.1 (DI)
unnamed: U311.5 (CO), U312.2 (CI)
unnamed: U311.6 (DO), U312.1 (DI)
unnamed: U312.5 (CO), U313.2 (CI)
unnamed: U312.6 (DO), U313.1 (DI)
unnamed: U313.5 (CO), U314.2 (CI)
unnamed: U313.6 (DO), U314.1 (DI)
unnamed: U314.5 (CO), U315.2 (CI)
unnamed: U314.6 (DO), U315.1 (DI)
unnamed: U315.5 (CO), U316.2 (CI)
unnamed: U315.6 (DO), U316.1 (DI)
unnamed: U316.5 (CO), U317.2 (CI)
unnamed: U316.6 (DO), U317.1 (DI)
unnamed: U317.5 (CO), U318.2 (CI)
unnamed: U317.6 (DO), U318.1 (DI)
unnamed: U318.5 (CO), U319.2 (CI)
unnamed: U318.6 (DO), U319.1 (DI)
unnamed: U319.5 (CO), U320.2 (CI)
unnamed: U319.6 (DO), U320.1 (DI)

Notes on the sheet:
POWER INPUT POSTS

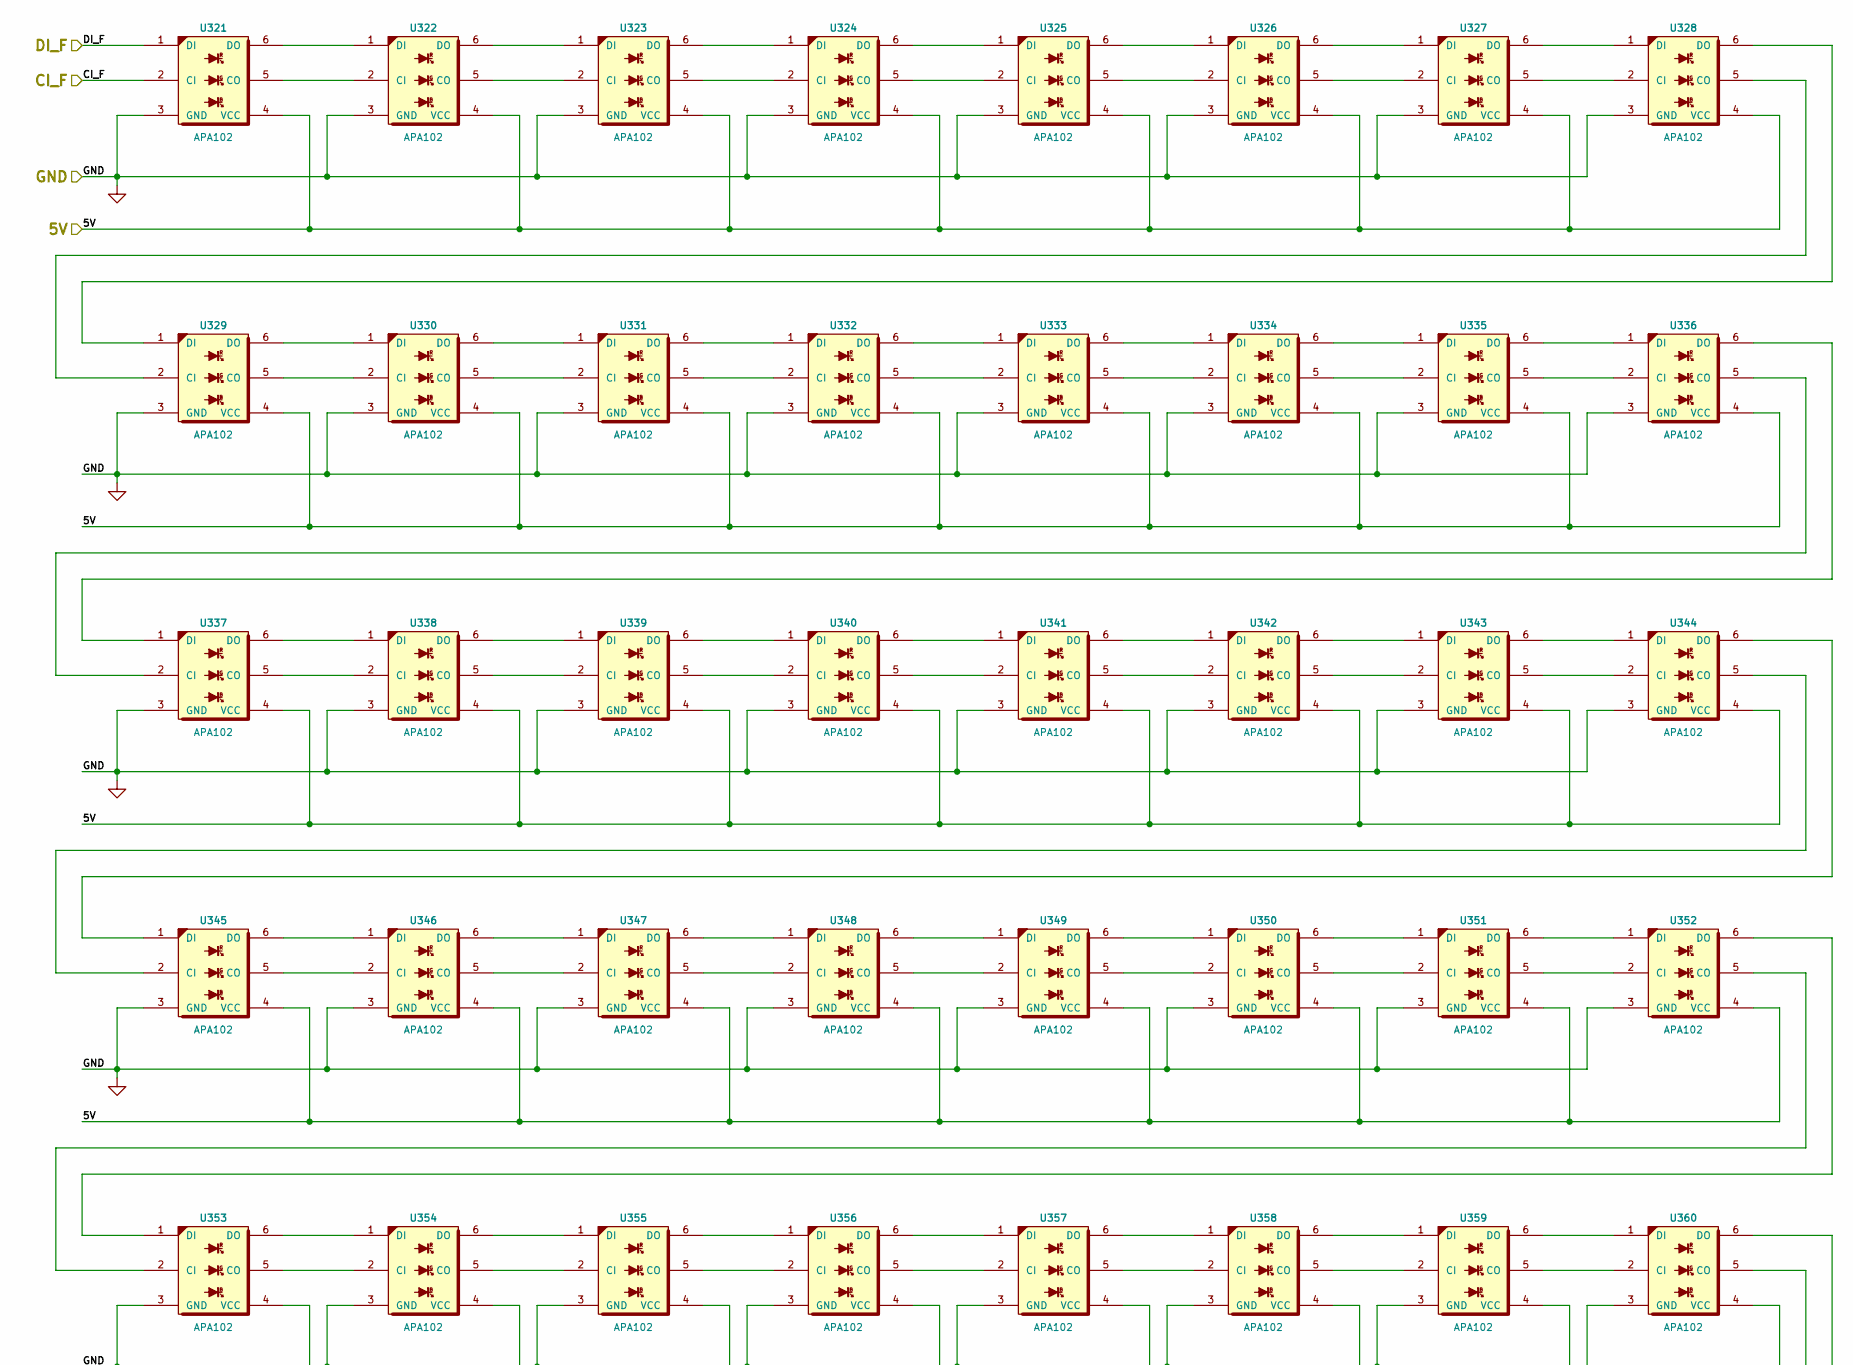
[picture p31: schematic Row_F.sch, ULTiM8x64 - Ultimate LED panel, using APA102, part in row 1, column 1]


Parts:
C21, C22: 47uF 20V; c_2917
C23, C24: 100nF; c_0805
U321, U322, U323, U324, U325, U326, U327, U328, U329, U330, U331, U332, U333, U334, U335, U336, U337, U338, U339, U340, U341, U342, U343, U344, U345, U346, U347, U348, U349, U350, U351, U352, U353, U354, U355, U356, U357, U358, U359, U360, U361, U362, U363, U364, U365, U366, U367, U368, U369, U370, U371, U372, U373, U374, U375, U376, U377, U378, U379, U380, U381, U382, U383, U384: APA102

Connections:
/Row_A/5V: C21.1 (+), C22.1 (+), C23.1, C24.1, U321.4 (VCC), U322.4 (VCC), U323.4 (VCC), U324.4 (VCC), U325.4 (VCC), U326.4 (VCC), U327.4 (VCC), U328.4 (VCC), U329.4 (VCC), U330.4 (VCC), U331.4 (VCC), U332.4 (VCC), U333.4 (VCC), U334.4 (VCC), U335.4 (VCC), U336.4 (VCC), U337.4 (VCC), U338.4 (VCC), U339.4 (VCC), U340.4 (VCC), U341.4 (VCC), U342.4 (VCC), U343.4 (VCC), U344.4 (VCC), U345.4 (VCC), U346.4 (VCC), U347.4 (VCC), U348.4 (VCC), U349.4 (VCC), U350.4 (VCC), U351.4 (VCC), U352.4 (VCC), U353.4 (VCC), U354.4 (VCC), U355.4 (VCC), U356.4 (VCC), U357.4 (VCC), U358.4 (VCC), U359.4 (VCC), U360.4 (VCC), U361.4 (VCC), U362.4 (VCC), U363.4 (VCC), U364.4 (VCC), U365.4 (VCC), U366.4 (VCC), U367.4 (VCC), U368.4 (VCC), U369.4 (VCC), U370.4 (VCC), U371.4 (VCC), U372.4 (VCC), U373.4 (VCC), U374.4 (VCC), U375.4 (VCC), U376.4 (VCC), U377.4 (VCC), U378.4 (VCC), U379.4 (VCC), U380.4 (VCC), U381.4 (VCC), U382.4 (VCC), U383.4 (VCC), U384.4 (VCC); also elsewhere on the board
/Row_E/CI_F: U321.2 (CI); also elsewhere on the board
/Row_E/DI_F: U321.1 (DI); also elsewhere on the board
/Row_F/CI_G: U384.5 (CO); also elsewhere on the board
/Row_F/DI_G: U384.6 (DO); also elsewhere on the board
GND: C21.2 (-), C22.2 (-), C23.2, C24.2, U321.3 (GND), U322.3 (GND), U323.3 (GND), U324.3 (GND), U325.3 (GND), U326.3 (GND), U327.3 (GND), U328.3 (GND), U329.3 (GND), U330.3 (GND), U331.3 (GND), U332.3 (GND), U333.3 (GND), U334.3 (GND), U335.3 (GND), U336.3 (GND), U337.3 (GND), U338.3 (GND), U339.3 (GND), U340.3 (GND), U341.3 (GND), U342.3 (GND), U343.3 (GND), U344.3 (GND), U345.3 (GND), U346.3 (GND), U347.3 (GND), U348.3 (GND), U349.3 (GND), U350.3 (GND), U351.3 (GND), U352.3 (GND), U353.3 (GND), U354.3 (GND), U355.3 (GND), U356.3 (GND), U357.3 (GND), U358.3 (GND), U359.3 (GND), U360.3 (GND), U361.3 (GND), U362.3 (GND), U363.3 (GND), U364.3 (GND), U365.3 (GND), U366.3 (GND), U367.3 (GND), U368.3 (GND), U369.3 (GND), U370.3 (GND), U371.3 (GND), U372.3 (GND), U373.3 (GND), U374.3 (GND), U375.3 (GND), U376.3 (GND), U377.3 (GND), U378.3 (GND), U379.3 (GND), U380.3 (GND), U381.3 (GND), U382.3 (GND), U383.3 (GND), U384.3 (GND); also elsewhere on the board
unnamed: U321.5 (CO), U322.2 (CI)
unnamed: U321.6 (DO), U322.1 (DI)
unnamed: U322.5 (CO), U323.2 (CI)
unnamed: U322.6 (DO), U323.1 (DI)
unnamed: U323.5 (CO), U324.2 (CI)
unnamed: U323.6 (DO), U324.1 (DI)
unnamed: U324.5 (CO), U325.2 (CI)
unnamed: U324.6 (DO), U325.1 (DI)
unnamed: U325.5 (CO), U326.2 (CI)
unnamed: U325.6 (DO), U326.1 (DI)
unnamed: U326.5 (CO), U327.2 (CI)
unnamed: U326.6 (DO), U327.1 (DI)
unnamed: U327.5 (CO), U328.2 (CI)
unnamed: U327.6 (DO), U328.1 (DI)
unnamed: U328.5 (CO), U329.2 (CI)
unnamed: U328.6 (DO), U329.1 (DI)
unnamed: U329.5 (CO), U330.2 (CI)
unnamed: U329.6 (DO), U330.1 (DI)
unnamed: U330.5 (CO), U331.2 (CI)
unnamed: U330.6 (DO), U331.1 (DI)
unnamed: U331.5 (CO), U332.2 (CI)
unnamed: U331.6 (DO), U332.1 (DI)
unnamed: U332.5 (CO), U333.2 (CI)
unnamed: U332.6 (DO), U333.1 (DI)
unnamed: U333.5 (CO), U334.2 (CI)
unnamed: U333.6 (DO), U334.1 (DI)
unnamed: U334.5 (CO), U335.2 (CI)
unnamed: U334.6 (DO), U335.1 (DI)
unnamed: U335.5 (CO), U336.2 (CI)
unnamed: U335.6 (DO), U336.1 (DI)
unnamed: U336.5 (CO), U337.2 (CI)
unnamed: U336.6 (DO), U337.1 (DI)
unnamed: U337.5 (CO), U338.2 (CI)
unnamed: U337.6 (DO), U338.1 (DI)
unnamed: U338.5 (CO), U339.2 (CI)
unnamed: U338.6 (DO), U339.1 (DI)
unnamed: U339.5 (CO), U340.2 (CI)
unnamed: U339.6 (DO), U340.1 (DI)
unnamed: U340.5 (CO), U341.2 (CI)
unnamed: U340.6 (DO), U341.1 (DI)
unnamed: U341.5 (CO), U342.2 (CI)
unnamed: U341.6 (DO), U342.1 (DI)
unnamed: U342.5 (CO), U343.2 (CI)
unnamed: U342.6 (DO), U343.1 (DI)
unnamed: U343.5 (CO), U344.2 (CI)
unnamed: U343.6 (DO), U344.1 (DI)
unnamed: U344.5 (CO), U345.2 (CI)
unnamed: U344.6 (DO), U345.1 (DI)
unnamed: U345.5 (CO), U346.2 (CI)
unnamed: U345.6 (DO), U346.1 (DI)
unnamed: U346.5 (CO), U347.2 (CI)
unnamed: U346.6 (DO), U347.1 (DI)
unnamed: U347.5 (CO), U348.2 (CI)
unnamed: U347.6 (DO), U348.1 (DI)
unnamed: U348.5 (CO), U349.2 (CI)
unnamed: U348.6 (DO), U349.1 (DI)
unnamed: U349.5 (CO), U350.2 (CI)
unnamed: U349.6 (DO), U350.1 (DI)
unnamed: U350.5 (CO), U351.2 (CI)
unnamed: U350.6 (DO), U351.1 (DI)
unnamed: U351.5 (CO), U352.2 (CI)
unnamed: U351.6 (DO), U352.1 (DI)
unnamed: U352.5 (CO), U353.2 (CI)
unnamed: U352.6 (DO), U353.1 (DI)
unnamed: U353.5 (CO), U354.2 (CI)
unnamed: U353.6 (DO), U354.1 (DI)
unnamed: U354.5 (CO), U355.2 (CI)
unnamed: U354.6 (DO), U355.1 (DI)
unnamed: U355.5 (CO), U356.2 (CI)
unnamed: U355.6 (DO), U356.1 (DI)
unnamed: U356.5 (CO), U357.2 (CI)
unnamed: U356.6 (DO), U357.1 (DI)
unnamed: U357.5 (CO), U358.2 (CI)
unnamed: U357.6 (DO), U358.1 (DI)
unnamed: U358.5 (CO), U359.2 (CI)
unnamed: U358.6 (DO), U359.1 (DI)
unnamed: U359.5 (CO), U360.2 (CI)
unnamed: U359.6 (DO), U360.1 (DI)
unnamed: U360.5 (CO), U361.2 (CI)
unnamed: U360.6 (DO), U361.1 (DI)
unnamed: U361.5 (CO), U362.2 (CI)
unnamed: U361.6 (DO), U362.1 (DI)
unnamed: U362.5 (CO), U363.2 (CI)
unnamed: U362.6 (DO), U363.1 (DI)
unnamed: U363.5 (CO), U364.2 (CI)
unnamed: U363.6 (DO), U364.1 (DI)
unnamed: U364.5 (CO), U365.2 (CI)
unnamed: U364.6 (DO), U365.1 (DI)
unnamed: U365.5 (CO), U366.2 (CI)
unnamed: U365.6 (DO), U366.1 (DI)
unnamed: U366.5 (CO), U367.2 (CI)
unnamed: U366.6 (DO), U367.1 (DI)
unnamed: U367.5 (CO), U368.2 (CI)
unnamed: U367.6 (DO), U368.1 (DI)
unnamed: U368.5 (CO), U369.2 (CI)
unnamed: U368.6 (DO), U369.1 (DI)
unnamed: U369.5 (CO), U370.2 (CI)
unnamed: U369.6 (DO), U370.1 (DI)
unnamed: U370.5 (CO), U371.2 (CI)
unnamed: U370.6 (DO), U371.1 (DI)
unnamed: U371.5 (CO), U372.2 (CI)
unnamed: U371.6 (DO), U372.1 (DI)
unnamed: U372.5 (CO), U373.2 (CI)
unnamed: U372.6 (DO), U373.1 (DI)
unnamed: U373.5 (CO), U374.2 (CI)
unnamed: U373.6 (DO), U374.1 (DI)
unnamed: U374.5 (CO), U375.2 (CI)
unnamed: U374.6 (DO), U375.1 (DI)
unnamed: U375.5 (CO), U376.2 (CI)
unnamed: U375.6 (DO), U376.1 (DI)
unnamed: U376.5 (CO), U377.2 (CI)
unnamed: U376.6 (DO), U377.1 (DI)
unnamed: U377.5 (CO), U378.2 (CI)
unnamed: U377.6 (DO), U378.1 (DI)
unnamed: U378.5 (CO), U379.2 (CI)
unnamed: U378.6 (DO), U379.1 (DI)
unnamed: U379.5 (CO), U380.2 (CI)
unnamed: U379.6 (DO), U380.1 (DI)
unnamed: U380.5 (CO), U381.2 (CI)
unnamed: U380.6 (DO), U381.1 (DI)
unnamed: U381.5 (CO), U382.2 (CI)
unnamed: U381.6 (DO), U382.1 (DI)
unnamed: U382.5 (CO), U383.2 (CI)
unnamed: U382.6 (DO), U383.1 (DI)
unnamed: U383.5 (CO), U384.2 (CI)
unnamed: U383.6 (DO), U384.1 (DI)

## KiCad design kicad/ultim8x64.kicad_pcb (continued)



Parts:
C25, C26: 47uF 20V; c_2917
C27, C28: 100nF; c_0805
P11: 5V; PowerIn_stud
P12: GND; PowerIn_stud
U385, U386, U387, U388, U391, U392, U393, U394, U397, U398, U399, U400, U401, U402, U404, U405, U406, U407, U408, U409, U410, U411, U412, U413, U414, U415, U416, U417, U418, U419, U420, U421, U423, U424, U425, U426, U428, U429, U430, U431, U432, U433, U434, U435, U436, U439, U440, U441, U442, U445, U446, U447, U448: APA102
U389: APA102; APA102_U05
U390: APA102; APA102_U06
U395: APA102; APA102_U11
U396: APA102; APA102_U12
U403: APA102; APA102_U19
U422: APA102; APA102_U38
U427: APA102; APA102_U43
U437: APA102; APA102_U53
U438: APA102; APA102_U54
U443: APA102; APA102_U59
U444: APA102; APA102_U60

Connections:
/Row_A/5V: C25.1 (+), C26.1 (+), C27.1, C28.1, P11.1, U385.4 (VCC), U386.4 (VCC), U387.4 (VCC), U388.4 (VCC), U389.4 (VCC), U390.4 (VCC), U391.4 (VCC), U392.4 (VCC), U393.4 (VCC), U394.4 (VCC), U395.4 (VCC), U396.4 (VCC), U397.4 (VCC), U398.4 (VCC), U399.4 (VCC), U400.4 (VCC), U401.4 (VCC), U402.4 (VCC), U403.4 (VCC), U404.4 (VCC), U405.4 (VCC), U406.4 (VCC), U407.4 (VCC), U408.4 (VCC), U409.4 (VCC), U410.4 (VCC), U411.4 (VCC), U412.4 (VCC), U413.4 (VCC), U414.4 (VCC), U415.4 (VCC), U416.4 (VCC), U417.4 (VCC), U418.4 (VCC), U419.4 (VCC), U420.4 (VCC), U421.4 (VCC), U422.4 (VCC), U423.4 (VCC), U424.4 (VCC), U425.4 (VCC), U426.4 (VCC), U427.4 (VCC), U428.4 (VCC), U429.4 (VCC), U430.4 (VCC), U431.4 (VCC), U432.4 (VCC), U433.4 (VCC), U434.4 (VCC), U435.4 (VCC), U436.4 (VCC), U437.4 (VCC), U438.4 (VCC), U439.4 (VCC), U440.4 (VCC), U441.4 (VCC), U442.4 (VCC), U443.4 (VCC), U444.4 (VCC), U445.4 (VCC), U446.4 (VCC), U447.4 (VCC), U448.4 (VCC); also elsewhere on the board
/Row_F/CI_G: U385.2 (CI); also elsewhere on the board
/Row_F/DI_G: U385.1 (DI); also elsewhere on the board
/Row_G/CI_H: U448.5 (CO); also elsewhere on the board
/Row_G/DI_H: U448.6 (DO); also elsewhere on the board
GND: C25.2 (-), C26.2 (-), C27.2, C28.2, P12.1, U385.3 (GND), U386.3 (GND), U387.3 (GND), U388.3 (GND), U389.3 (GND), U390.3 (GND), U391.3 (GND), U392.3 (GND), U393.3 (GND), U394.3 (GND), U395.3 (GND), U396.3 (GND), U397.3 (GND), U398.3 (GND), U399.3 (GND), U400.3 (GND), U401.3 (GND), U402.3 (GND), U403.3 (GND), U404.3 (GND), U405.3 (GND), U406.3 (GND), U407.3 (GND), U408.3 (GND), U409.3 (GND), U410.3 (GND), U411.3 (GND), U412.3 (GND), U413.3 (GND), U414.3 (GND), U415.3 (GND), U416.3 (GND), U417.3 (GND), U418.3 (GND), U419.3 (GND), U420.3 (GND), U421.3 (GND), U422.3 (GND), U423.3 (GND), U424.3 (GND), U425.3 (GND), U426.3 (GND), U427.3 (GND), U428.3 (GND), U429.3 (GND), U430.3 (GND), U431.3 (GND), U432.3 (GND), U433.3 (GND), U434.3 (GND), U435.3 (GND), U436.3 (GND), U437.3 (GND), U438.3 (GND), U439.3 (GND), U440.3 (GND), U441.3 (GND), U442.3 (GND), U443.3 (GND), U444.3 (GND), U445.3 (GND), U446.3 (GND), U447.3 (GND), U448.3 (GND); also elsewhere on the board
unnamed: U385.5 (CO), U386.2 (CI)
unnamed: U385.6 (DO), U386.1 (DI)
unnamed: U386.5 (CO), U387.2 (CI)
unnamed: U386.6 (DO), U387.1 (DI)
unnamed: U387.5 (CO), U388.2 (CI)
unnamed: U387.6 (DO), U388.1 (DI)
unnamed: U388.5 (CO), U389.2 (CI)
unnamed: U388.6 (DO), U389.1 (DI)
unnamed: U389.5 (CO), U390.2 (CI)
unnamed: U389.6 (DO), U390.1 (DI)
unnamed: U390.5 (CO), U391.2 (CI)
unnamed: U390.6 (DO), U391.1 (DI)
unnamed: U391.5 (CO), U392.2 (CI)
unnamed: U391.6 (DO), U392.1 (DI)
unnamed: U392.5 (CO), U393.2 (CI)
unnamed: U392.6 (DO), U393.1 (DI)
unnamed: U393.5 (CO), U394.2 (CI)
unnamed: U393.6 (DO), U394.1 (DI)
unnamed: U394.5 (CO), U395.2 (CI)
unnamed: U394.6 (DO), U395.1 (DI)
unnamed: U395.5 (CO), U396.2 (CI)
unnamed: U395.6 (DO), U396.1 (DI)
unnamed: U396.5 (CO), U397.2 (CI)
unnamed: U396.6 (DO), U397.1 (DI)
unnamed: U397.5 (CO), U398.2 (CI)
unnamed: U397.6 (DO), U398.1 (DI)
unnamed: U398.5 (CO), U399.2 (CI)
unnamed: U398.6 (DO), U399.1 (DI)
unnamed: U399.5 (CO), U400.2 (CI)
unnamed: U399.6 (DO), U400.1 (DI)
unnamed: U400.5 (CO), U401.2 (CI)
unnamed: U400.6 (DO), U401.1 (DI)
unnamed: U401.5 (CO), U402.2 (CI)
unnamed: U401.6 (DO), U402.1 (DI)
unnamed: U402.5 (CO), U403.2 (CI)
unnamed: U402.6 (DO), U403.1 (DI)
unnamed: U403.5 (CO), U404.2 (CI)
unnamed: U403.6 (DO), U404.1 (DI)
unnamed: U404.5 (CO), U405.2 (CI)
unnamed: U404.6 (DO), U405.1 (DI)
unnamed: U405.5 (CO), U406.2 (CI)
unnamed: U405.6 (DO), U406.1 (DI)
unnamed: U406.5 (CO), U407.2 (CI)
unnamed: U406.6 (DO), U407.1 (DI)
unnamed: U407.5 (CO), U408.2 (CI)
unnamed: U407.6 (DO), U408.1 (DI)
unnamed: U408.5 (CO), U409.2 (CI)
unnamed: U408.6 (DO), U409.1 (DI)
unnamed: U409.5 (CO), U410.2 (CI)
unnamed: U409.6 (DO), U410.1 (DI)
unnamed: U410.5 (CO), U411.2 (CI)
unnamed: U410.6 (DO), U411.1 (DI)
unnamed: U411.5 (CO), U412.2 (CI)
unnamed: U411.6 (DO), U412.1 (DI)
unnamed: U412.5 (CO), U413.2 (CI)
unnamed: U412.6 (DO), U413.1 (DI)
unnamed: U413.5 (CO), U414.2 (CI)
unnamed: U413.6 (DO), U414.1 (DI)
unnamed: U414.5 (CO), U415.2 (CI)
unnamed: U414.6 (DO), U415.1 (DI)
unnamed: U415.5 (CO), U416.2 (CI)
unnamed: U415.6 (DO), U416.1 (DI)
unnamed: U416.5 (CO), U417.2 (CI)
unnamed: U416.6 (DO), U417.1 (DI)
unnamed: U417.5 (CO), U418.2 (CI)
unnamed: U417.6 (DO), U418.1 (DI)
unnamed: U418.5 (CO), U419.2 (CI)
unnamed: U418.6 (DO), U419.1 (DI)
unnamed: U419.5 (CO), U420.2 (CI)
unnamed: U419.6 (DO), U420.1 (DI)
unnamed: U420.5 (CO), U421.2 (CI)
unnamed: U420.6 (DO), U421.1 (DI)
unnamed: U421.5 (CO), U422.2 (CI)
unnamed: U421.6 (DO), U422.1 (DI)
unnamed: U422.5 (CO), U423.2 (CI)
unnamed: U422.6 (DO), U423.1 (DI)
unnamed: U423.5 (CO), U424.2 (CI)
unnamed: U423.6 (DO), U424.1 (DI)
unnamed: U424.5 (CO), U425.2 (CI)
unnamed: U424.6 (DO), U425.1 (DI)
unnamed: U425.5 (CO), U426.2 (CI)
unnamed: U425.6 (DO), U426.1 (DI)
unnamed: U426.5 (CO), U427.2 (CI)
unnamed: U426.6 (DO), U427.1 (DI)
unnamed: U427.5 (CO), U428.2 (CI)
unnamed: U427.6 (DO), U428.1 (DI)
unnamed: U428.5 (CO), U429.2 (CI)
unnamed: U428.6 (DO), U429.1 (DI)
unnamed: U429.5 (CO), U430.2 (CI)
unnamed: U429.6 (DO), U430.1 (DI)
unnamed: U430.5 (CO), U431.2 (CI)
unnamed: U430.6 (DO), U431.1 (DI)
unnamed: U431.5 (CO), U432.2 (CI)
unnamed: U431.6 (DO), U432.1 (DI)
unnamed: U432.5 (CO), U433.2 (CI)
unnamed: U432.6 (DO), U433.1 (DI)
unnamed: U433.5 (CO), U434.2 (CI)
unnamed: U433.6 (DO), U434.1 (DI)
unnamed: U434.5 (CO), U435.2 (CI)
unnamed: U434.6 (DO), U435.1 (DI)
unnamed: U435.5 (CO), U436.2 (CI)
unnamed: U435.6 (DO), U436.1 (DI)
unnamed: U436.5 (CO), U437.2 (CI)
unnamed: U436.6 (DO), U437.1 (DI)
unnamed: U437.5 (CO), U438.2 (CI)
unnamed: U437.6 (DO), U438.1 (DI)
unnamed: U438.5 (CO), U439.2 (CI)
unnamed: U438.6 (DO), U439.1 (DI)
unnamed: U439.5 (CO), U440.2 (CI)
unnamed: U439.6 (DO), U440.1 (DI)
unnamed: U440.5 (CO), U441.2 (CI)
unnamed: U440.6 (DO), U441.1 (DI)
unnamed: U441.5 (CO), U442.2 (CI)
unnamed: U441.6 (DO), U442.1 (DI)
unnamed: U442.5 (CO), U443.2 (CI)
unnamed: U442.6 (DO), U443.1 (DI)
unnamed: U443.5 (CO), U444.2 (CI)
unnamed: U443.6 (DO), U444.1 (DI)
unnamed: U444.5 (CO), U445.2 (CI)
unnamed: U444.6 (DO), U445.1 (DI)
unnamed: U445.5 (CO), U446.2 (CI)
unnamed: U445.6 (DO), U446.1 (DI)
unnamed: U446.5 (CO), U447.2 (CI)
unnamed: U446.6 (DO), U447.1 (DI)
unnamed: U447.5 (CO), U448.2 (CI)
unnamed: U447.6 (DO), U448.1 (DI)

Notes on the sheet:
POWER INPUT POSTS

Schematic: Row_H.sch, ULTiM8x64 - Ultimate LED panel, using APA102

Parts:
C29, C30: 47uF 20V; c_2917
C31, C32: 100nF; c_0805
U449, U450, U451, U452, U453, U454, U455, U456, U457, U458, U459, U460, U461, U462, U463, U464, U465, U466, U467, U468, U469, U470, U471, U472, U473, U474, U475, U476, U477, U478, U479, U480, U481, U482, U483, U484, U485, U486, U487, U488, U489, U490, U491, U492, U493, U494, U495, U496, U497, U498, U499, U500, U501, U502, U503, U504, U505, U506, U507, U508, U509, U510, U511, U512: APA102

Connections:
/Row_A/5V: C29.1 (+), C30.1 (+), C31.1, C32.1, U449.4 (VCC), U450.4 (VCC), U451.4 (VCC), U452.4 (VCC), U453.4 (VCC), U454.4 (VCC), U455.4 (VCC), U456.4 (VCC), U457.4 (VCC), U458.4 (VCC), U459.4 (VCC), U460.4 (VCC), U461.4 (VCC), U462.4 (VCC), U463.4 (VCC), U464.4 (VCC), U465.4 (VCC), U466.4 (VCC), U467.4 (VCC), U468.4 (VCC), U469.4 (VCC), U470.4 (VCC), U471.4 (VCC), U472.4 (VCC), U473.4 (VCC), U474.4 (VCC), U475.4 (VCC), U476.4 (VCC), U477.4 (VCC), U478.4 (VCC), U479.4 (VCC), U480.4 (VCC), U481.4 (VCC), U482.4 (VCC), U483.4 (VCC), U484.4 (VCC), U485.4 (VCC), U486.4 (VCC), U487.4 (VCC), U488.4 (VCC), U489.4 (VCC), U490.4 (VCC), U491.4 (VCC), U492.4 (VCC), U493.4 (VCC), U494.4 (VCC), U495.4 (VCC), U496.4 (VCC), U497.4 (VCC), U498.4 (VCC), U499.4 (VCC), U500.4 (VCC), U501.4 (VCC), U502.4 (VCC), U503.4 (VCC), U504.4 (VCC), U505.4 (VCC), U506.4 (VCC), U507.4 (VCC), U508.4 (VCC), U509.4 (VCC), U510.4 (VCC), U511.4 (VCC), U512.4 (VCC); also elsewhere on the board
/Row_G/CI_H: U449.2 (CI); also elsewhere on the board
/Row_G/DI_H: U449.1 (DI); also elsewhere on the board
/Row_H/CO_H: U512.5 (CO); also elsewhere on the board
/Row_H/DO_H: U512.6 (DO); also elsewhere on the board
GND: C29.2 (-), C30.2 (-), C31.2, C32.2, U449.3 (GND), U450.3 (GND), U451.3 (GND), U452.3 (GND), U453.3 (GND), U454.3 (GND), U455.3 (GND), U456.3 (GND), U457.3 (GND), U458.3 (GND), U459.3 (GND), U460.3 (GND), U461.3 (GND), U462.3 (GND), U463.3 (GND), U464.3 (GND), U465.3 (GND), U466.3 (GND), U467.3 (GND), U468.3 (GND), U469.3 (GND), U470.3 (GND), U471.3 (GND), U472.3 (GND), U473.3 (GND), U474.3 (GND), U475.3 (GND), U476.3 (GND), U477.3 (GND), U478.3 (GND), U479.3 (GND), U480.3 (GND), U481.3 (GND), U482.3 (GND), U483.3 (GND), U484.3 (GND), U485.3 (GND), U486.3 (GND), U487.3 (GND), U488.3 (GND), U489.3 (GND), U490.3 (GND), U491.3 (GND), U492.3 (GND), U493.3 (GND), U494.3 (GND), U495.3 (GND), U496.3 (GND), U497.3 (GND), U498.3 (GND), U499.3 (GND), U500.3 (GND), U501.3 (GND), U502.3 (GND), U503.3 (GND), U504.3 (GND), U505.3 (GND), U506.3 (GND), U507.3 (GND), U508.3 (GND), U509.3 (GND), U510.3 (GND), U511.3 (GND), U512.3 (GND); also elsewhere on the board
unnamed: U449.5 (CO), U450.2 (CI)
unnamed: U449.6 (DO), U450.1 (DI)
unnamed: U450.5 (CO), U451.2 (CI)
unnamed: U450.6 (DO), U451.1 (DI)
unnamed: U451.5 (CO), U452.2 (CI)
unnamed: U451.6 (DO), U452.1 (DI)
unnamed: U452.5 (CO), U453.2 (CI)
unnamed: U452.6 (DO), U453.1 (DI)
unnamed: U453.5 (CO), U454.2 (CI)
unnamed: U453.6 (DO), U454.1 (DI)
unnamed: U454.5 (CO), U455.2 (CI)
unnamed: U454.6 (DO), U455.1 (DI)
unnamed: U455.5 (CO), U456.2 (CI)
unnamed: U455.6 (DO), U456.1 (DI)
unnamed: U456.5 (CO), U457.2 (CI)
unnamed: U456.6 (DO), U457.1 (DI)
unnamed: U457.5 (CO), U458.2 (CI)
unnamed: U457.6 (DO), U458.1 (DI)
unnamed: U458.5 (CO), U459.2 (CI)
unnamed: U458.6 (DO), U459.1 (DI)
unnamed: U459.5 (CO), U460.2 (CI)
unnamed: U459.6 (DO), U460.1 (DI)
unnamed: U460.5 (CO), U461.2 (CI)
unnamed: U460.6 (DO), U461.1 (DI)
unnamed: U461.5 (CO), U462.2 (CI)
unnamed: U461.6 (DO), U462.1 (DI)
unnamed: U462.5 (CO), U463.2 (CI)
unnamed: U462.6 (DO), U463.1 (DI)
unnamed: U463.5 (CO), U464.2 (CI)
unnamed: U463.6 (DO), U464.1 (DI)
unnamed: U464.5 (CO), U465.2 (CI)
unnamed: U464.6 (DO), U465.1 (DI)
unnamed: U465.5 (CO), U466.2 (CI)
unnamed: U465.6 (DO), U466.1 (DI)
unnamed: U466.5 (CO), U467.2 (CI)
unnamed: U466.6 (DO), U467.1 (DI)
unnamed: U467.5 (CO), U468.2 (CI)
unnamed: U467.6 (DO), U468.1 (DI)
unnamed: U468.5 (CO), U469.2 (CI)
unnamed: U468.6 (DO), U469.1 (DI)
unnamed: U469.5 (CO), U470.2 (CI)
unnamed: U469.6 (DO), U470.1 (DI)
unnamed: U470.5 (CO), U471.2 (CI)
unnamed: U470.6 (DO), U471.1 (DI)
unnamed: U471.5 (CO), U472.2 (CI)
unnamed: U471.6 (DO), U472.1 (DI)
unnamed: U472.5 (CO), U473.2 (CI)
unnamed: U472.6 (DO), U473.1 (DI)
unnamed: U473.5 (CO), U474.2 (CI)
unnamed: U473.6 (DO), U474.1 (DI)
unnamed: U474.5 (CO), U475.2 (CI)
unnamed: U474.6 (DO), U475.1 (DI)
unnamed: U475.5 (CO), U476.2 (CI)
unnamed: U475.6 (DO), U476.1 (DI)
unnamed: U476.5 (CO), U477.2 (CI)
unnamed: U476.6 (DO), U477.1 (DI)
unnamed: U477.5 (CO), U478.2 (CI)
unnamed: U477.6 (DO), U478.1 (DI)
unnamed: U478.5 (CO), U479.2 (CI)
unnamed: U478.6 (DO), U479.1 (DI)
unnamed: U479.5 (CO), U480.2 (CI)
unnamed: U479.6 (DO), U480.1 (DI)
unnamed: U480.5 (CO), U481.2 (CI)
unnamed: U480.6 (DO), U481.1 (DI)
unnamed: U481.5 (CO), U482.2 (CI)
unnamed: U481.6 (DO), U482.1 (DI)
unnamed: U482.5 (CO), U483.2 (CI)
unnamed: U482.6 (DO), U483.1 (DI)
unnamed: U483.5 (CO), U484.2 (CI)
unnamed: U483.6 (DO), U484.1 (DI)
unnamed: U484.5 (CO), U485.2 (CI)
unnamed: U484.6 (DO), U485.1 (DI)
unnamed: U485.5 (CO), U486.2 (CI)
unnamed: U485.6 (DO), U486.1 (DI)
unnamed: U486.5 (CO), U487.2 (CI)
unnamed: U486.6 (DO), U487.1 (DI)
unnamed: U487.5 (CO), U488.2 (CI)
unnamed: U487.6 (DO), U488.1 (DI)
unnamed: U488.5 (CO), U489.2 (CI)
unnamed: U488.6 (DO), U489.1 (DI)
unnamed: U489.5 (CO), U490.2 (CI)
unnamed: U489.6 (DO), U490.1 (DI)
unnamed: U490.5 (CO), U491.2 (CI)
unnamed: U490.6 (DO), U491.1 (DI)
unnamed: U491.5 (CO), U492.2 (CI)
unnamed: U491.6 (DO), U492.1 (DI)
unnamed: U492.5 (CO), U493.2 (CI)
unnamed: U492.6 (DO), U493.1 (DI)
unnamed: U493.5 (CO), U494.2 (CI)
unnamed: U493.6 (DO), U494.1 (DI)
unnamed: U494.5 (CO), U495.2 (CI)
unnamed: U494.6 (DO), U495.1 (DI)
unnamed: U495.5 (CO), U496.2 (CI)
unnamed: U495.6 (DO), U496.1 (DI)
unnamed: U496.5 (CO), U497.2 (CI)
unnamed: U496.6 (DO), U497.1 (DI)
unnamed: U497.5 (CO), U498.2 (CI)
unnamed: U497.6 (DO), U498.1 (DI)
unnamed: U498.5 (CO), U499.2 (CI)
unnamed: U498.6 (DO), U499.1 (DI)
unnamed: U499.5 (CO), U500.2 (CI)
unnamed: U499.6 (DO), U500.1 (DI)
unnamed: U500.5 (CO), U501.2 (CI)
unnamed: U500.6 (DO), U501.1 (DI)
unnamed: U501.5 (CO), U502.2 (CI)
unnamed: U501.6 (DO), U502.1 (DI)
unnamed: U502.5 (CO), U503.2 (CI)
unnamed: U502.6 (DO), U503.1 (DI)
unnamed: U503.5 (CO), U504.2 (CI)
unnamed: U503.6 (DO), U504.1 (DI)
unnamed: U504.5 (CO), U505.2 (CI)
unnamed: U504.6 (DO), U505.1 (DI)
unnamed: U505.5 (CO), U506.2 (CI)
unnamed: U505.6 (DO), U506.1 (DI)
unnamed: U506.5 (CO), U507.2 (CI)
unnamed: U506.6 (DO), U507.1 (DI)
unnamed: U507.5 (CO), U508.2 (CI)
unnamed: U507.6 (DO), U508.1 (DI)
unnamed: U508.5 (CO), U509.2 (CI)
unnamed: U508.6 (DO), U509.1 (DI)
unnamed: U509.5 (CO), U510.2 (CI)
unnamed: U509.6 (DO), U510.1 (DI)
unnamed: U510.5 (CO), U511.2 (CI)
unnamed: U510.6 (DO), U511.1 (DI)
unnamed: U511.5 (CO), U512.2 (CI)
unnamed: U511.6 (DO), U512.1 (DI)



Board: 2 copper layers, 487.7 x 61.0 mm, 560 parts (48 on the bottom side), 1028 nets.
